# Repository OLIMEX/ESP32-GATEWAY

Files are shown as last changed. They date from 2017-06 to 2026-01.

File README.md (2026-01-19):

# ESP32-GATEWAY
ESP32 WiFi / BLE development board with Ethernet, microSD card, GPIOs, made with KiCAD

Board page: https://www.olimex.com/Products/IoT/ESP32/ESP32-GATEWAY/open-source-hardware

Hardware is released under Apache 2.0 License

Box design is released under CC BY 4.0 License

Software is released under GPL3 License

Documentation is released under CC BY-SA 3.0

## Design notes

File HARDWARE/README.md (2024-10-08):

# ESP32-GATEWAY
ESP32 WIFI / BLE development board with Ethernet, micro SD card, GPIOs made with KiCAD.

Notice that we use the latest nightly KiCad builds.

Hardware change log:

- Hardware revision I

1. To reduce noise getting picked by Ethernet clock, disconnected GPIO17 from the CON1 header. Added 
jumper pads GPIO17_E1 (open by default) if somebody wants to lead it to the header...

---

- Hardawre revision H

1. Added diode D5 on esp_en;
3. Added TVS1 on PHY;
4. Opravi se value na NA(HN1x20);
5. T1 now LMUN2211LT1G;
6. USB connector changed to type C (more popular nowadays);
7. Added r12 and c6;
8. Added CE sign;
9. R28,R31,R32,R33 lowered to 0402 size;
10. DCDC - SY8089 changed to TPS62A02ADRLR. C3 now NA. L2 changed to 1.0uH/2.5A/CD32;
11. Updated the CH340X module to the latest one. 

---

- Hardware revision G

1. R54 removed. R24 and R16 moved further away from the button.
2. Improved EN signal - added C5(1uF/0603) on pin #3 of ESP32. R24 now 10k.

---

- Hardware revision F

- Added 3D view. Major changes to GPIO header, SD card mode, power consumption!:

1. GPIO6-11, which are used by the ESP32's internal flash, were disconnected from CON1 
and the 6 SD card signals are now routed instead for use when SD card is not present;
2.  SD card changed from 4-bit mode of operation to 1-bit mode of operation! Added 3 
NA resistor pads (R9-R11) for backwards compatiblity.
3. A lot of deep sleep mode improvements to lower the consumption to 100uA or less:

- R19 was changed from 4.99k/1%/R0603 to 220k/R0603;

- R20 was changed from 1.1k/1%/R0603 to 49.9k/1%/R0603;

- R30 was changed from 10k/0603 to 1M/R0603;

- LED_E1 jumper added to provide an option to disable the power LED;

- R24 changed from 1k/0603 to 1M/R0603;

- U5(CH340)'s pin 20disconnected from GND and left opened;

- CH340 now powered only when USB is present;

- R35 and R40 were changed from 220R/R0603 to 10k/R0603;

- D1 and D3 added, 1N5819S4/SOD123, as level shifters;

4. L2 was changed from 2.2uH/1.5A/DCR<0.1R/CD32 to 2.2uH/1.5A/DCR=72mR/20%/3.00x3.00x1.50mm/CD32(NR3015T2R2M);
5. U3's value was changed from ESP-WROOM-32 to ESP32-WROOM-32D-4MB;
6. U9(BAT54C(SOT23-3)) was renamed to D4;

---

- Hardware revision E1

1. Added C2/22uF/0603 for slower PHY powering

- Hardware revision E

1. R5 connected after T1's collector and value changed from NA to 1K. 
2. Improved drill distances.

- Hardware revision D

>Major Ethernet schematic changes, now similar to ESP32-PoE:

1. LAN8710's pin XTAL1 was disconnected from GPIO0 and connected to GPIO17/EMAC_CLK_OUT_180. GPIO17 
is now source clock. GPIO5 is now used as Ethernet "power enable pin".
2. CR1(Q50MHz/25ppm/3V/4P/5x3.2mm) and all surrounding elements were deleted.
3. U8(NCP303LSN27T1G(SOT-23-5)) and all surrounding elements were deleted.
4. U10(BAT54C), R44 and R5 were deleted.
5. FET1, R5, R6, C2, T1 and L1 were added to enable Ethernet power on/off feature.
6. GPIO5 is used for Ethernet power on/off.

- Hardware revision C

1. R5(1k) resistor added between OSC_EN and NRST(pin #19) of LAN8710A chip. Later, it was changed to NA!
2. U2 changed from SY8009AAAC(SOT23-5) to SY8089AAAC(SOT23-5).
3. FET2 changed from IRLML6402 to WPM2015-3/TR.
4. ESP32-WROOM module pad improvements 

>Major changes to the Ethernet PHY and reset similar to EVB's_Rev_D1:

5. U8 changed from BD5230G-TR(SSOP5/SOT-23-5) to NCP303LSN27T1G(SOT-23-5).
6. C28 changed from 10nF/50V/20%/Y5V/C0603 to 470nF/16V/10%/X7R/C0603.
7. C18 changed from 10uF/6.3V/20%/X5R/C0603 to NA.
8. R38 changed from 100k to 10k/R0603.
9. R5 changed from 1k/R0603 to NA.

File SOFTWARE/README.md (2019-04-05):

# ESP32-GATEWAY software development

This repo contains ESP-IDF examples for Olimex ESP32-GATEWAY.

Since there are major hardware changes between revision C and D, there
are two folders with examples! The clock source for the Ethernet is different!

If you own newer board, revision D or newer then get the IDF exmaples from
folder "Newest-hardware-revisions"

If you have board revision B or C then get the demos from folder
"Hardware-revisions-B-or-C"

If you are looking for Arduino demos just install the official ESP32 json,
our board is supported in the official branches.

## Install ESP-IDF
To run the examples in this directory or your own you'll need to get
SDK from Espressif called [ESP-IDF](https://github.com/espressif/esp-idf).
We recommend reading their
[setup guide](https://github.com/espressif/esp-idf#setting-up-esp-idf).

When IDF_PATH is in your PATH you're ready to continue with example running.

## Run examples
To run our example all you need to do is:

* Run menuconfig
```sh
    make menuconfig
```

    * Configure serial flasher

    ESP32-GATEWAY has built-in serial flasher to help users upload their projects.
    Connect the board to PC via USB-micro cable. New serial device should
    apear, for example **/dev/ttyUSB0**. Then in the menuconfig configure
    flasher as follows:

    ```
    Serial flasher config  --->
            (/dev/ttyUSB0) Default serial port
            Default baud rate (115200 baud) --->
            [*] Use compressed upload
            Flash SPI mode (DIO)  --->
            Flash SPI speed (40 MHz) --->
            Flash size (4 MB) --->
            [*] Detect flash size when flashing bootloader
            Before flashing (Reset to bootloader)  --->
            After flashing (Reset after flashing)  --->
            'make monitor' baud rate (115200 bps)  --->
    ```

    * Configure example

    Some examples have their own configuration menu. If it's present
    you can modify the options:

    ```
    Example Configuration  --->
            Select board relay to use in the example (Relay 1)  --->
    ```

Exit and save configuration.

* Compile example
To compile example run:
```sh
make
```

* Uploading example
As we previously mention uploading application is done automatically.
If serial flasher is configured do:
```sh
make flash
```

You'll see something like this:
```
esptool.py v2.0-beta3
Flashing binaries to serial port /dev/ttyUSB0 (app at offset 0x10000)...
esptool.py v2.0-beta3
Connecting........__
Uploading stub...
Running stub...
Stub running...
Configuring flash size...
Auto-detected Flash size: 4MB
Flash params set to 0x0220
Compressed 15808 bytes to 9219...
Wrote 15808 bytes (9219 compressed) at 0x00001000 in 0.8 seconds (effective 154.5 kbit/s)...
Hash of data verified.
Compressed 356080 bytes to 168292...
Wrote 356080 bytes (168292 compressed) at 0x00010000 in 14.9 seconds (effective 191.3 kbit/s)...
Hash of data verified.
Compressed 3072 bytes to 82...
Wrote 3072 bytes (82 compressed) at 0x00008000 in 0.0 seconds (effective 1905.4 kbit/s)...
Hash of data verified.

Leaving...
Hard resetting...
```

Optionally you can open serial monitor by typing:
```sh
make monitor
```

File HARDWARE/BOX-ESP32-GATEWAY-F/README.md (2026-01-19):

Box can be purchased from here: https://www.olimex.com/Products/IoT/ESP32/BOX-ESP32-GATEWAY-F/

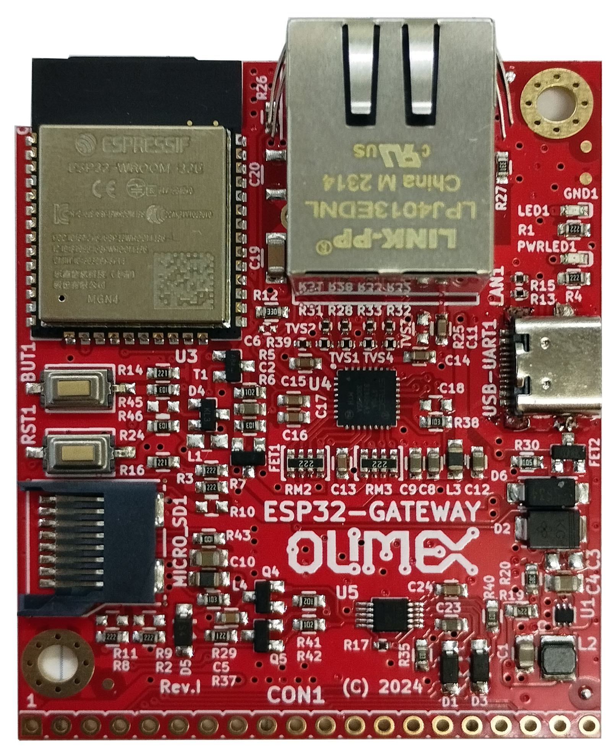
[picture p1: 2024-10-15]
DOCS/ESP32-GATEWAY-2-USB-C.jpg

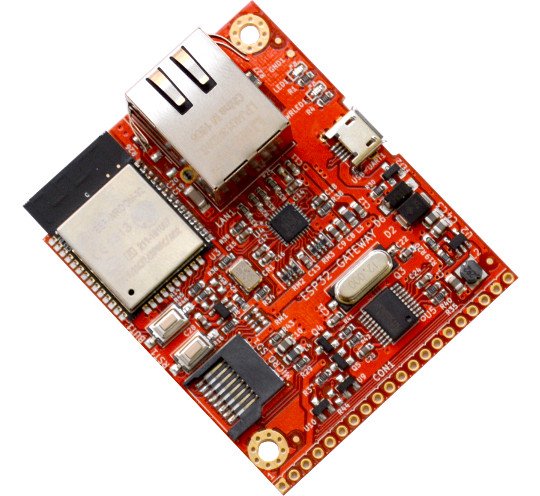
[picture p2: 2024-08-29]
DOCS/ESP32-GATEWAY-1.jpg

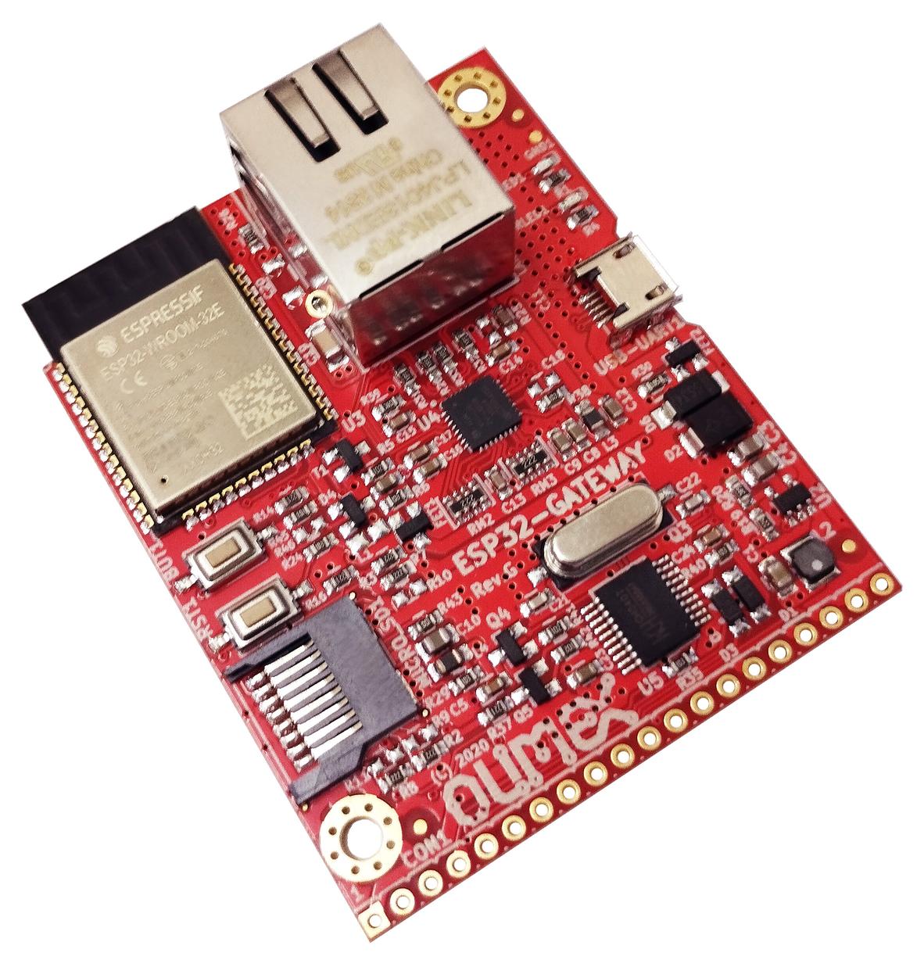
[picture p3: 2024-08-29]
DOCS/ESP32-GATEWAY-1-new.jpg

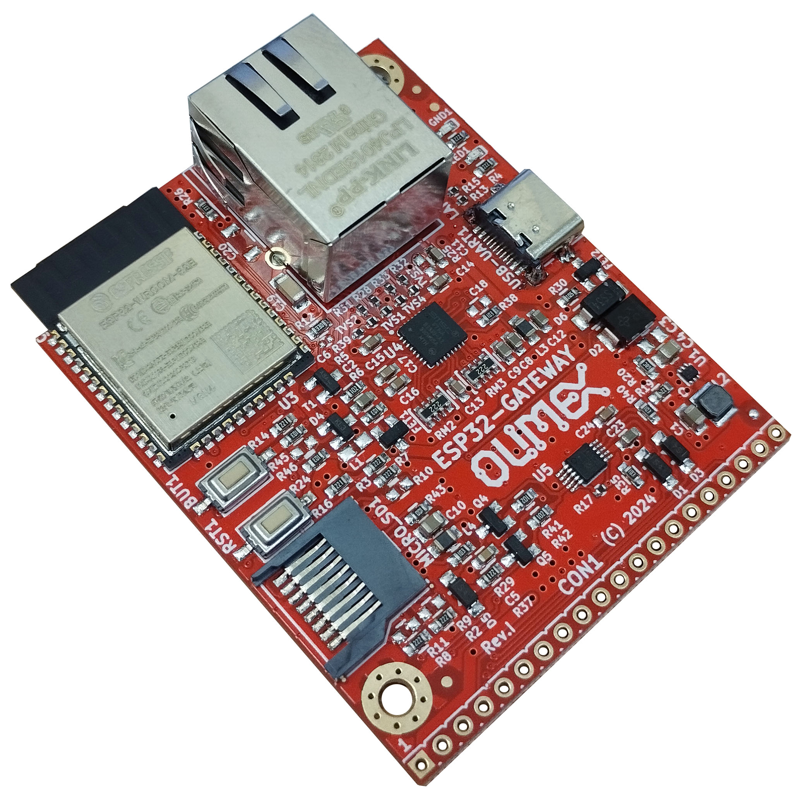
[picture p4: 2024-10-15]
DOCS/ESP32-GATEWAY-USB-C.jpg

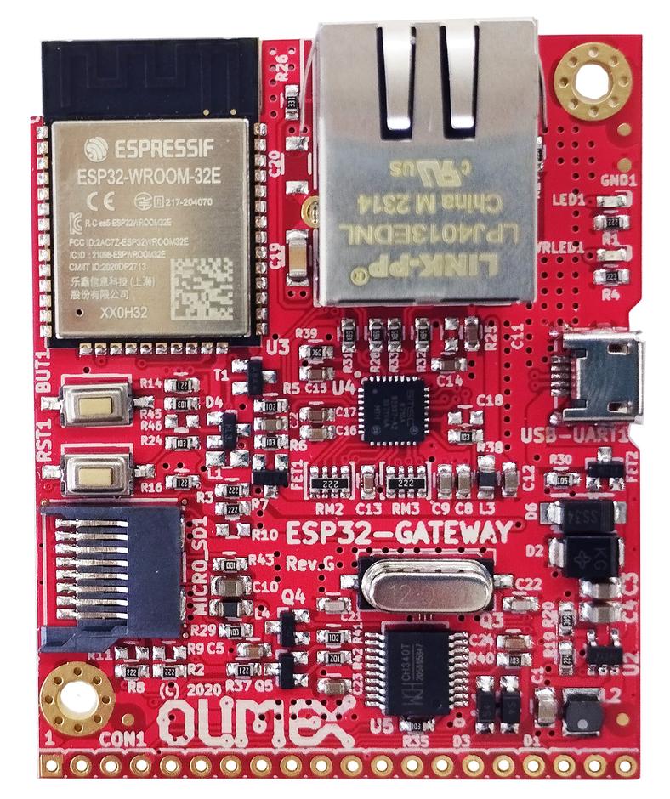
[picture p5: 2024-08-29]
DOCS/ESP32-GATEWAY-2-new.jpg

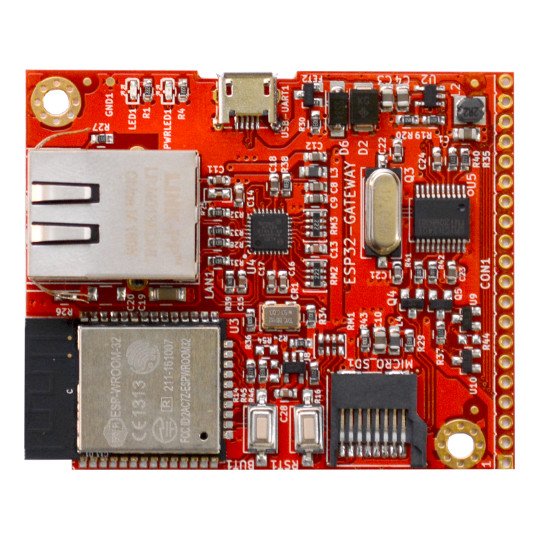
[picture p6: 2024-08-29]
DOCS/ESP32-GATEWAY-2.jpg

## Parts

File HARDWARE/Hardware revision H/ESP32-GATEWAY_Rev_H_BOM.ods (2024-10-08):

Qty | Designation | Package | Designator
1 | 0R(Board_Mounted) | R_0603_5MIL_DWS | R25
1 | 10R/R0603 | R_0603_5MIL_DWS | R43
1 | 33R/R0603 | R_0603_5MIL_DWS | R12
4 | 49.9R/1%/R0402 | R_0402_5MIL_DWS | R28,R31,R32,R33
3 | 220R/R0603 | R_0603_5MIL_DWS | R37,R16,R14
2 | 330R/R0603 | R_0603_5MIL_DWS | R27,R26
3 | 1k/R0603 | R_0603_5MIL_DWS | R5,R42,R41
6 | 2.2k/R0603 | R_0603_5MIL_DWS | R3,R2,R1,R4,R8,R7
1 | 4.7k/R0402 | R_0402_5MIL_DWS | R17
2 | 5.1k/1%/R0402 | R_0402_5MIL_DWS | R13,R15
7 | 10k/R0603 | R_0603_5MIL_DWS | R35,R29,R6,R45,R40,R38,R24
1 | 12.1k/1%/R0402 | R_0402_5MIL_DWS | R39
1 | 49.9k/1%/R0603 | R_0603_5MIL_DWS | R20
1 | 220k/R0603 | R_0603_5MIL_DWS | R19
1 | 1M/R0603 | R_0603_5MIL_DWS | R30
2 | RA1206_(4X0603)_4B8_2.2k | R_MATRIX_4 | RM3,RM2
1 | 1nF/2000V/10%/X7R/C1206 | C_1206_5MIL_DWS_ISO | C19
6 | 100nF/50V/20%/Y5V/C0603 | C_0603_5MIL_DWS | C24,C17,C15,C14,C13,C11
1 | 1uF/10V/10%/X5R/C0603 | C_0603_5MIL_DWS | C5
1 | 2.2uF/6.3V/10%/X5R/C0603 | C_0603_5MIL_DWS | C16
5 | 22uF/6.3V/20%/X5R/C0603 | C_0603_5MIL_DWS | C2,C23,C12,C9,C8
3 | 47uF/6.3V/20%/X5R/C0805 | C_0805_5MIL_DWS | C4,C10,C1
1 | 1.0uH/2.5A/DCR=30mR/20%/3x3x 1.5mm/CD32(SWPA3015S1R0MT) | CD32 | L2
2 | 600OHM/2A/UPZ2012E-601-2R0TF | L_0805_5MIL_DWS | L4,L3
3 | 1N5819S4/SOD123 | SOD-123_1C-2A_KA | D3,D1,D5
1 | 1N5822/SS34/SMA | SMA-KA | D6
1 | BAT54C(SOT23-3) | SOT23-3 | D4
1 | SMBJ6.0A(DO-214AA) | DO214AA_1(K)-2(A) | D2
1 | LED/GREEN/0603 | LED_0603_KA | LED1
1 | LED/RED/0603 | LED_0603_KA | PWRLED1
4 | GG0402052R542P | D_0402_5MIL_DWS | TVS2,TVS3,TVS4,TVS1
1 | LMUN2211LT1G | SOT23 | T1
2 | WPM2015-3/TR | SOT23 | FET1,FET2
2 | BC817-40(SOT23) | SOT23 | Q5,Q4
1 | ESP32-WROOM-32E-N4 | ESP-WROOM-32_MODULE | U3
1 | LAN8710A-EZC-ABC | QFN32_EP(33)_5.00x5.00x 0.90mm_Pitch_0.50mm | U4
1 | CH340X(MSOP-10) | MSOP-10_Pitch-0.5mm_ 3.00x3.00x1.00mm | U5
1 | TPS62A02ADRLR(SOT-563-6) | SOT-563-6 | U1
1 | USB-C-16P-F-PTH | USB2.0_TYPE-C (A40-00119-A52-12) | USB-UART1
1 | TFC-WXCP11-08-LF | TFC-WXCP11-08-LF | MICRO_SD1
1 | RJLD-060TC1(LPJ4013EDNL) | RJLBC-060TC1 | LAN1
2 | T1107A(6x3,8x2,5MM) | T1107A(6x3,8x2,5MM) | RST1,BUT1
1 | Opened | SJ | PHY_RST1
1 | Closed | SJ | LED_E1
1 | NA(10uF/6.3V/20%/X5R/C0603) | C_0603_5MIL_DWS | C18
1 | NA(47uF/6.3V/20%/X5R/C0805) | C_0805_5MIL_DWS | C3
1 | NA(FB0805/600R/2A) | L_0805_5MIL_DWS | L1
1 | NA(1nF/2000V/10%/X7R/C1206) | C_1206_5MIL_DWS_ISO | C20
1 | NA(HN1x20) | HN1x20 | CON1
4 | NA/R0603 | R_0603_5MIL_DWS | R46,R10,R9,R11
1 | NA/C0402 | C_0402_5MIL_DWS | C6

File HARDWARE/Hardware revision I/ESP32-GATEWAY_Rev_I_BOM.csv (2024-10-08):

Id | Designator | Package | Quantity | Designation | Supplier and ref
1 | U4 | QFN32_EP(33)_5.00x5.00x0.90mm_Pitch_0.50mm | 1 | LAN8710A-EZC-ABC
2 | USB-UART1 | USB2.0_TYPE-C(A40-00119-A52-12) | 1 | USB-C-16P-F-PTH
3 | D3,D1,D5 | SOD-123_1C-2A_KA | 3 | 1N5819S4/SOD123
4 | R19 | R_0603_5MIL_DWS | 1 | 220k/R0603
5 | R35,R29,R6,R45,R40,R38,R24 | R_0603_5MIL_DWS | 7 | 10k/R0603
6 | U5 | MSOP-10_Pitch-0.5mm_3.00x3.00x1.00mm | 1 | CH340X(MSOP-10)
7 | U3 | ESP-WROOM-32_MODULE | 1 | ESP32-WROOM-32E-N4
8 | Sign_CE | CE_Sign | 1 | CE_Sign
9 | LED_E1 | SJ | 1 | Closed
10 | MICRO_SD1 | TFC-WXCP11-08-LF | 1 | TFC-WXCP11-08-LF
11 | Logo-OlimexBIG,Logo-OLimeX | OLIMEX_LOGO_TB | 2
12 | R5,R42,R41 | R_0603_5MIL_DWS | 3 | 1k/R0603
13 | L1 | L_0805_5MIL_DWS | 1 | NA(FB0805/600R/2A)
14 | C2,C23,C12,C9,C8 | C_0603_5MIL_DWS | 5 | 22uF/6.3V/20%/X5R/C0603
15 | T1 | SOT23 | 1 | LMUN2211LT1G
16 | FET1,FET2 | SOT23 | 2 | WPM2015-3/TR
17 | D2 | DO214AA_1(K)-2(A) | 1 | SMBJ6.0A(DO-214AA)
18 | R3,R2,R1,R4,R8,R7 | R_0603_5MIL_DWS | 6 | 2.2k/R0603
19 | Sign_RoHS | LOGO_ROHS_1 | 1 | Val**
20 | Sign-RecyclBin | LOGO_RECYCLEBIN_1 | 1
21 | Sign_Pb-Free | LOGO_PBFREE | 1
22 | Logo-OSHW | LOGO_OPENHARDWARE_8x8 | 1
23 | Sign-Antistatic | LOGO_ANTISTATIC_1 | 1 | Val**
24 | LED1 | LED_0603_KA | 1 | LED/GREEN/0603
25 | CON1 | HN1x20 | 1 | NA(HN1x20)
26 | R37,R16,R14 | R_0603_5MIL_DWS | 3 | 220R/R0603
27 | C4,C10,C1 | C_0805_5MIL_DWS | 3 | 47uF/6.3V/20%/X5R/C0805
28 | C3 | C_0805_5MIL_DWS | 1 | NA(47uF/6.3V/20%/X5R/C0805)
29 | R20 | R_0603_5MIL_DWS | 1 | 49.9k/1%/R0603
30 | R46,R10,R9,R11 | R_0603_5MIL_DWS | 4 | NA/R0603
31 | R30 | R_0603_5MIL_DWS | 1 | 1M/R0603
32 | D6 | SMA-KA | 1 | 1N5822/SS34/SMA
33 | C24,C17,C15,C14,C13,C11 | C_0603_5MIL_DWS | 6 | 100nF/50V/20%/Y5V/C0603
34 | C20 | C_1206_5MIL_DWS_ISO | 1 | NA(1nF/2000V/10%/X7R/C1206)
35 | C19 | C_1206_5MIL_DWS_ISO | 1 | 1nF/2000V/10%/X7R/C1206
36 | R43 | R_0603_5MIL_DWS | 1 | 10R/R0603
37 | R27,R26 | R_0603_5MIL_DWS | 2 | 330R/R0603
38 | PWRLED1 | LED_0603_KA | 1 | LED/RED/0603
39 | GND1 | TESTPAD_40-ROUND | 1 | TESTPAD
40 | C18 | C_0603_5MIL_DWS | 1 | NA(10uF/6.3V/20%/X5R/C0603)
41 | C16 | C_0603_5MIL_DWS | 1 | 2.2uF/6.3V/10%/X5R/C0603
42 | PHY_RST1,GPIO17_E1 | SJ | 2 | Opened
43 | MH1,MH2 | Mounting_hole_Shield_3.3mm | 2 | Mounting_hole_Shield_3.3mm
44 | L4,L3 | L_0805_5MIL_DWS | 2 | 600OHM/2A/UPZ2012E-601-2R0TF
45 | Q5,Q4 | SOT23 | 2 | BC817-40(SOT23)
46 | L2 | CD32 | 1 | 1.0uH/2.5A/DCR=30mR/20%/3.00x3.00x1.50mm/CD32(SWPA3015S1R0MT)
47 | RM3,RM2 | R_MATRIX_4 | 2 | RA1206_(4X0603)_4B8_2.2k
48 | RST1,BUT1 | T1107A(6x3,8x2,5MM) | 2 | T1107A(6x3,8x2,5MM)
49 | D4 | SOT23-3 | 1 | BAT54C(SOT23-3)
50 | FID1,FID3 | Fiducial1x3 | 2 | Fiducial
51 | R25 | R_0603_5MIL_DWS | 1 | 0R(Board_Mounted)
52 | C5 | C_0603_5MIL_DWS | 1 | 1uF/C0603
53 | LAN1 | RJLBC-060TC1 | 1 | RJLD-060TC1(LPJ4013EDNL)
54 | R12 | R_0603_5MIL_DWS | 1 | 33R/R0603
55 | R28,R31,R32,R33 | R_0402_5MIL_DWS | 4 | 49.9R/1%/R0402
56 | FID4,FID2 | Fiducial1x3_Past | 2 | Fiducial
57 | TVS2,TVS3,TVS4,TVS1 | D_0402_5MIL_DWS | 4 | GG0402052R542P
58 | C6 | C_0402_5MIL_DWS | 1 | NA/C0402
59 | R39 | R_0402_5MIL_DWS | 1 | 12.1k/1%/R0402
60 | U1 | SOT-563-6 | 1 | TPS62A02ADRLR(SOT-563-6)
61 | R13,R15 | R_0402_5MIL_DWS | 2 | 5.1k/1%/R0402
62 | R17 | R_0402_5MIL_DWS | 1 | 4.7k/R0402

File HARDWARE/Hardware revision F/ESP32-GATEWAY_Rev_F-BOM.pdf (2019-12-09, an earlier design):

09:20:28 | ESP32-GATEWAY_Rev_F | 04/30/2019
Qty | Designation | Package | Designator
1 | 0R(board_mounted) | 0R_0603 | R25
1 | 10R/R0603 | R_0603_5MIL_DWS | R43
4 | 49.9R/1%/R0603 | R_0603_5MIL_DWS | R28,R31,R32,R33
3 | 220R/R0603 | R_0603_5MIL_DWS | R14,R16,R37
2 | 330R/R0603 | R_0603_5MIL_DWS | R26,R27
3 | 1k/R0603 | R_0603_5MIL_DWS | R5,R41,R42
6 | 10k/R0603 | R_0603_5MIL_DWS | R6,R29,R35,R38,R40,R45
6 | 2.2k/R0603 | R_0603_5MIL_DWS | R1,R2,R3,R4,R7,R8
1 | 12.1k/1%/R0603 | R_0603_5MIL_DWS | R39
1 | 49.9k/1%/R0603 | R_0603_5MIL_DWS | R20
1 | 220k/R0603 | R_0603_5MIL_DWS | R19
1 | 1M/R0603 | R_0603_5MIL_DWS | R24,R30
2 | RA1206_(4X0603)_4B8_2.2k | R_MATRIX_4 | RM2,RM3
2 | 27pF/50V/5%/C0G/C0603 | C_0603_5MIL_DWS | C21,C22
1 | 1nF/2000V/10%/X7R/C1206 | C_1206_5MIL_DWS_ISO | C19
6 | 100nF/50V/20%/Y5V/C0603 | C_0603_5MIL_DWS | C11,C13,C14,C15,C17,C24
1 | 2.2uF/6.3V/10%/X5R/C0603 | C_0603_5MIL_DWS | C16
5 | 22uF/6.3V/20%/X5R/C0603 | C_0603_5MIL_DWS | C2,C8,C9,C12,C23
4 | 47uF/6.3V/20%/X5R/C0805 | C_0805_5MIL_DWS | C1,C3,C4,C10
1 | 2.2uH/1.5A/DCR=72mR/20%/ 3.00x3.00x1.50mm/ CD32(NR3015T2R2M) | CD32 | L2
2 | FB0805/600R/2A | L_0805_5MIL_DWS | L3,L4
1 | 1N5822/SS34/SMA | SMA-KA | D6
1 | SMBJ6.0A(DO-214AA) | DO214AA_1(K)-2(A) | D2
1 | BAT54C(SOT23-3) | SOT23-3 | D4
2 | 1N5819S4/SOD123 | SOD123 | D1,D3
1 | LED/GREEN/0603 | LED_0603_KA | LED1
1 | LED/RED/0603 | LED_0603_KA | PWRLED1
2 | WPM2015-3/TR | SOT23 | FET1,FET2
1 | DTC114YKA | SOT23 | T1
2 | BC817-40(SOT23) | SOT23 | Q4,Q5
1 | Q12MHz/20pF/30ppm/2P/ HC-49SM(SMD) | Q_49U3HMS | Q3
1 | ESP32-WROOM-32D-4MB | ESP-WROOM-32_MODULE | U3
1 | SY8089AAAC(SOT23-5) | SOT-23-5 | U2
1 | CH340T(SSOP20W) | SSOP-20W | U5
1 | LAN8710A-EZC(QFN32) | QFN32_EP(33)_5.00x5.00x0.90mm_ Pitch_0.50mm | U4
2 | T1107A(6x3,8x2,5MM) | T1107A(6x3,8x2,5MM) | BUT1,RST1
1 | TFC-WXCP11-08-LF | TFC-WXCP11-08-LF | MICRO_SD1
1 | RJLD-060TC1(LPJ4013EDNL) | RJLBC-060TC1 | LAN1
1 | MISB-SWMM-5B-LF (USB_MICRO) | USB-MICRO_ MISB-SWMM-5B_LF | USB-UART1
1 | Opened | SJ | PHY_RST1
1 | Closed | SJ | LED_E1
1 | NA(10uF/6.3V/20%/X5R/C0603) | C_0603_5MIL_DWS | C18
1 | NA(1nF/2000V/10%/X7R/C1206) | C_1206_5MIL_DWS_ISO | C20
5 | NA/R0603 | R_0603_5MIL_DWS | R9,R10,R11,R46,R54
1 | NA(NH1x20) | HN1x20 | CON1
1 | NA(FB0805/600R/2A) | L_0805_5MIL_DWS | L1

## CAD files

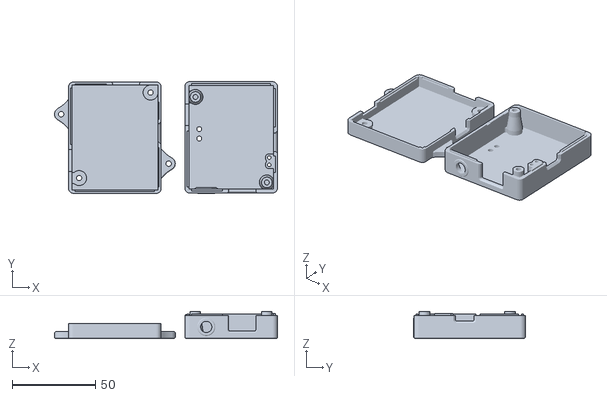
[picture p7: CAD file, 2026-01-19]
HARDWARE/BOX-ESP32-GATEWAY-F/esp32_gateway-v16.stl
134.2 x 67.7 x 16.3

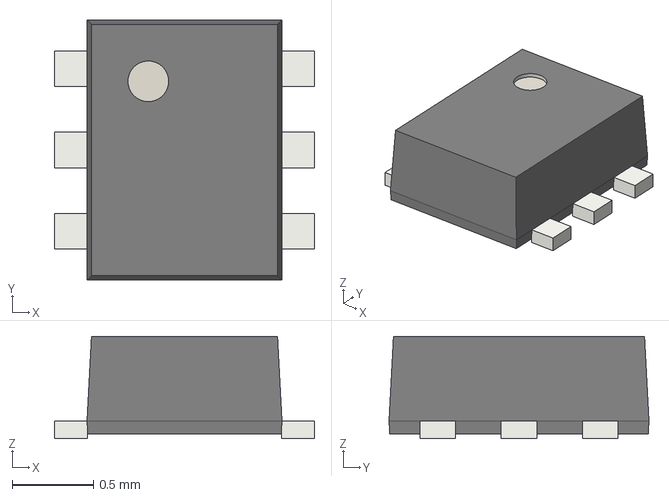
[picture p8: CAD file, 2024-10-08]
HARDWARE/Hardware revision H/3d/SOT-563.step
1.60 x 1.60 x 0.63 mm

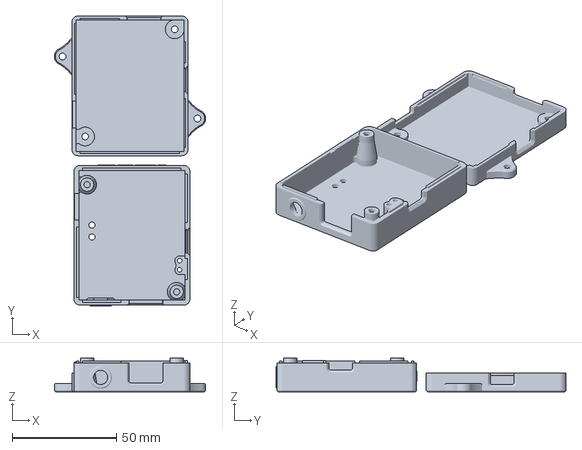
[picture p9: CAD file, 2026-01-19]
HARDWARE/BOX-ESP32-GATEWAY-F/esp32_gateway-v16-bambu-lab-project.3mf
72.7 x 139.2 x 16.3 mm

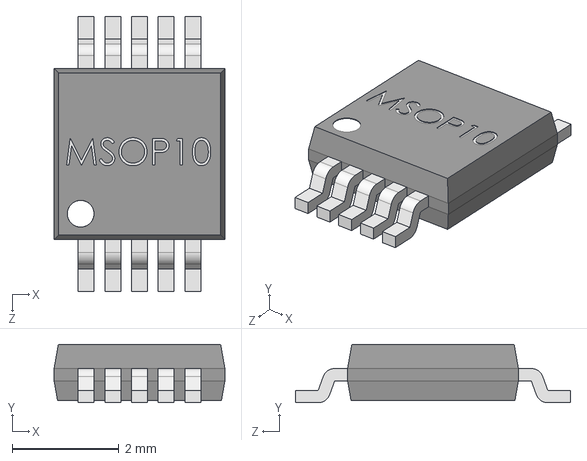
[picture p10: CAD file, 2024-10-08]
HARDWARE/Hardware revision H/3d/MSOP10-1.step
3.20 x 1.10 x 5.15 mm

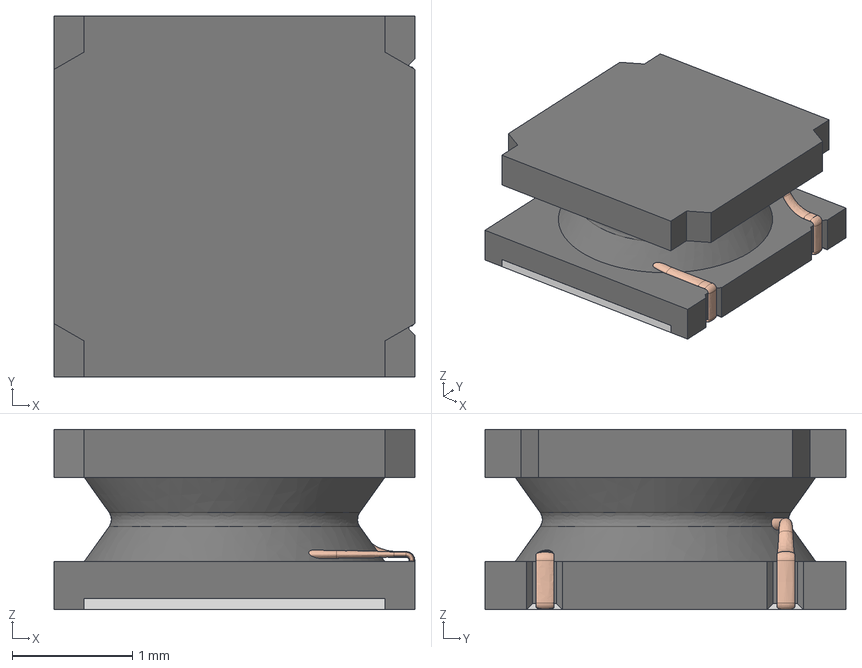
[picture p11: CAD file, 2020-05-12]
HARDWARE/Hardware revision H/3d/L-CD32_shielded.step
3.00 x 3.00 x 1.50 mm

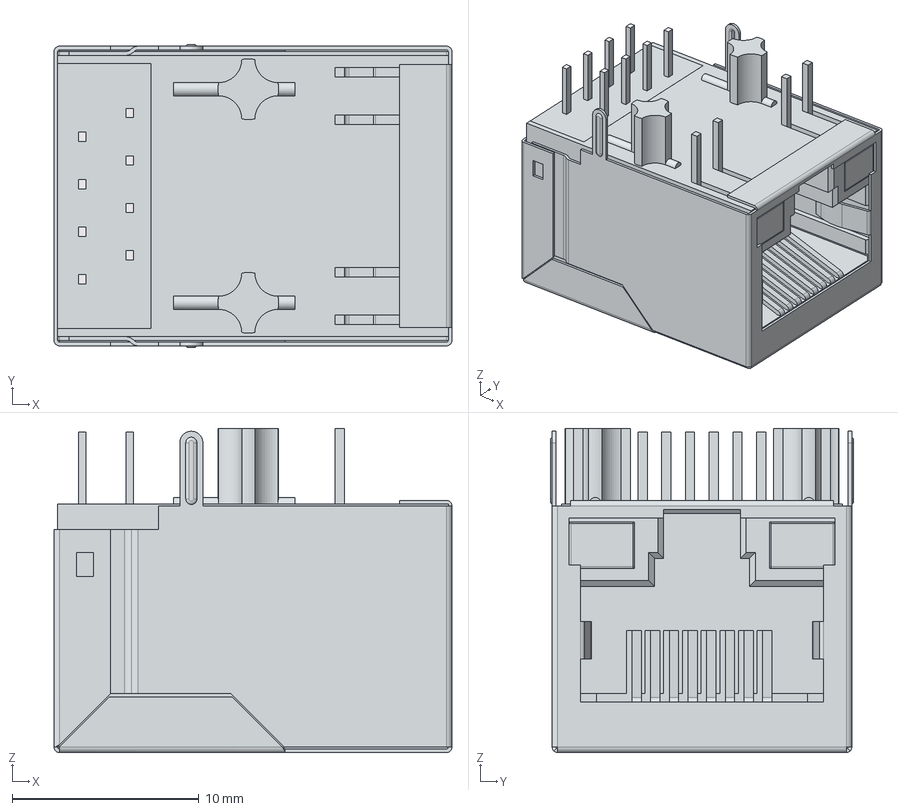
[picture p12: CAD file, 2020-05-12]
HARDWARE/Hardware revision H/3d/Connector_1Port_RJ45_Magjack_10-100Base-T_AutoMDIX_Wurth_Electronics-7499010441.stp
21.3 x 16.2 x 17.4 mm
Shielding
Insulator 3
Insulator 1
Insulator 2
Green_Yellow_LED x 2

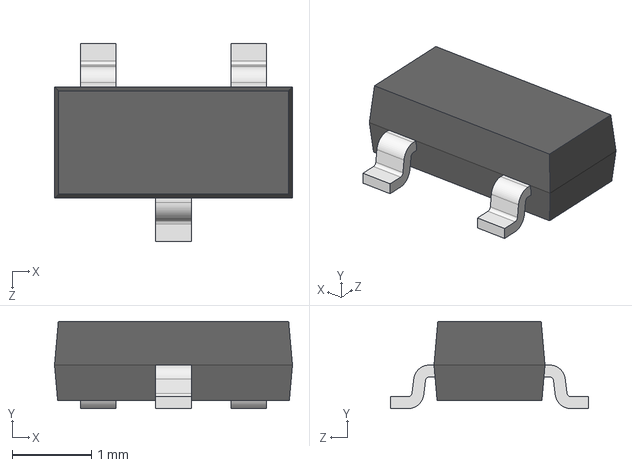
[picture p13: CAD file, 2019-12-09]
HARDWARE/Hardware revision H/3d/SOT-23.step
3.00 x 1.10 x 2.50 mm

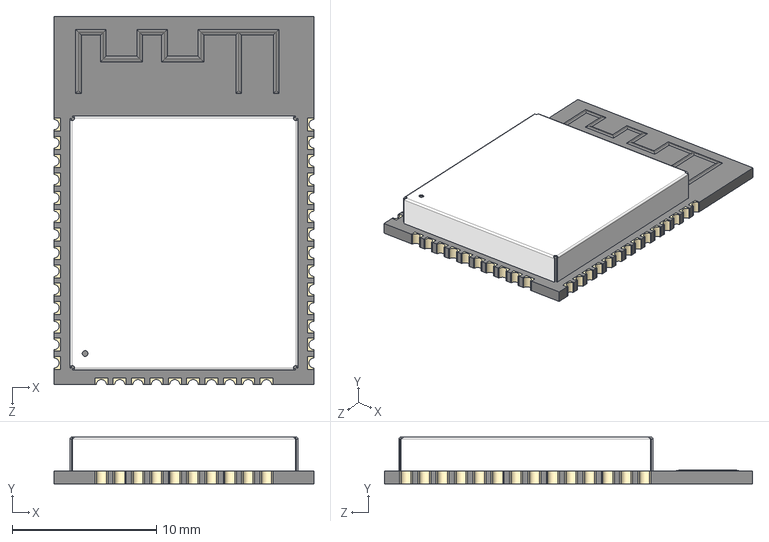
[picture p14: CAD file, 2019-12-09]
HARDWARE/Hardware revision H/3d/ESP32-WROOM-32D-56544.STEP
18.0 x 3.25 x 25.5 mm

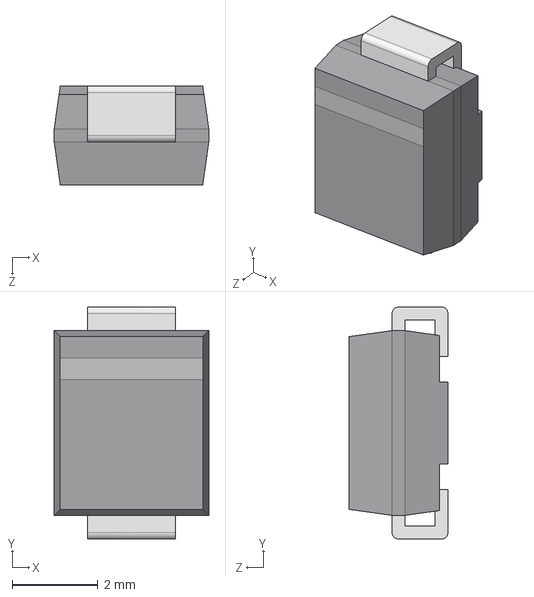
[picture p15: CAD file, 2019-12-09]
HARDWARE/Hardware revision I/3d/DO-214AA_SMB.step
3.60 x 5.40 x 2.30 mm

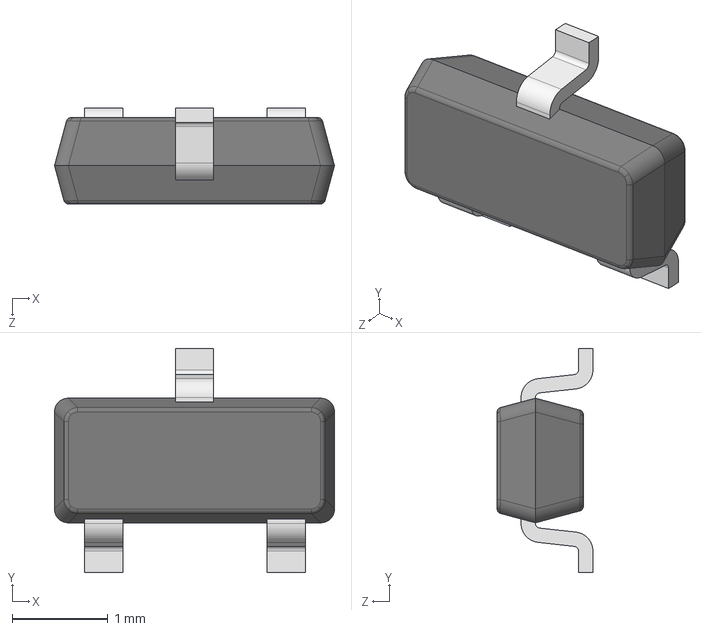
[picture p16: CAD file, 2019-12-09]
HARDWARE/Hardware revision H/3d/BAT54.step
2.92 x 2.34 x 1.00 mm

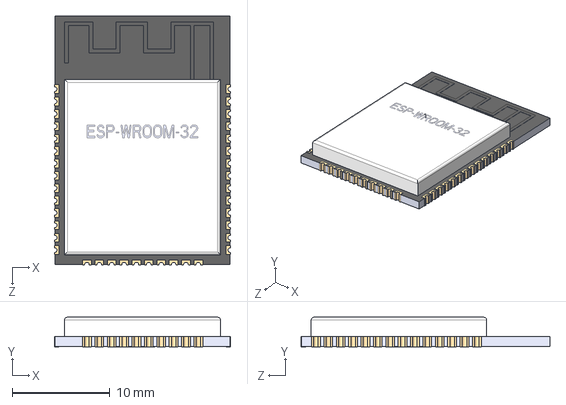
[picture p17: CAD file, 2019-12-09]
HARDWARE/Hardware revision I/3d/esp-wroom-32.step
18.1 x 3.04 x 25.5 mm

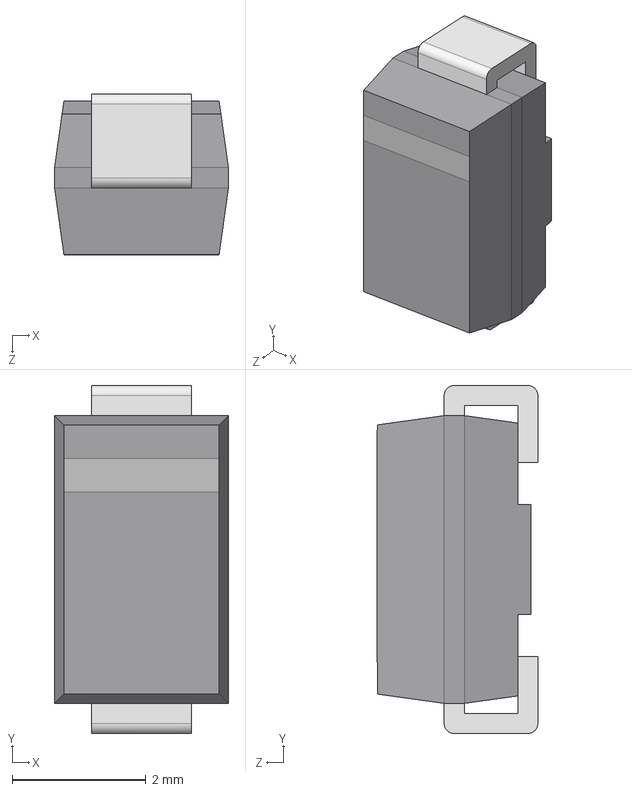
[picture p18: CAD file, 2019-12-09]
HARDWARE/Hardware revision I/3d/DO-214AC_SMA.step
2.60 x 5.20 x 2.40 mm

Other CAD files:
HARDWARE/Hardware revision F/3d/CD32_inductor.step
HARDWARE/Hardware revision G/3d/SOT-23-5.step
HARDWARE/Hardware revision G/3d/User_Library-Crystal_HC49_US-SM.step
HARDWARE/Hardware revision G/3d/usb_micro_4p.stp
HARDWARE/Hardware revision H/3d/434121043836 (rev1).stp
HARDWARE/Hardware revision H/3d/5040771891.stp
HARDWARE/Hardware revision H/3d/QFN32_5x5.step
HARDWARE/Hardware revision H/3d/SOD123.step
HARDWARE/Hardware revision I/3d/434121043836 (rev1).stp
HARDWARE/Hardware revision I/3d/5040771891.stp
HARDWARE/Hardware revision I/3d/QFN32_5x5.step
HARDWARE/Hardware revision I/3d/SOD123.step

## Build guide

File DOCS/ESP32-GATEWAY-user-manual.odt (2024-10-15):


ESP32-GATEWAY

User Manual

Document revision 2.1, October 2024 | www.olimex.com

# 1. What is ESP32-GATEWAY

ESP32-GATEWAY is a mature Open Source Hardware development board that incorporates n ESP32 module. The ESP32-GATEWAY board is designed and manufactured by Olimex, while the ESP32 module is designed and manufactured by Espressif systems. The ESP32 modules are extremely popular WIFI/BT modules due to their size, price, and very good documentation.

The ESP32-GATEWAY board has the following features:

- ESP32-WROOM-32E or ESP32-WROOM-32UE module with WiFi, BLE connectivity
- USB type C connector for powering and programming with CH340 USB serial converter
- Ethernet 100Mb interface with LAN8710A driver
- MicroSD card
- Reset button
- User button
- Power status LED
- User LED
- GPIO 20 pin connector with all ESP32 ports
- Dimensions: (50 x 62)mm ~ (1.95 x 2.45)"
- Optional external antenna (-EA)
- Industrial grade -40+85C version available (-IND)

## 1.1 ESP32-GATEWAY variants

The board has 4 variants – ESP32-GATEWAY, ESP32-GATEWAY-EA, ESP32-GATEWAY-EA-IND, ESP32-GATEWAY-IND. The base variant ESP32-GATEWAY works in commercial temperature range (0-70 degrees C) and has on-module antenna.

ESP32-GATEWAY and ESP32-GATEWAY-IND come with ESP32-WROOM-32E module;

ESP32-GATEWAY-EA and ESP32-GATEWAY-EA-IND come with ESP32-WROOM-32UE and external antenna;

ESP32-GATEWAY and ESP32-GATEWAY-EA work in the commercial temperature range 0-70C;

ESP32-GATEWAY-IND and ESP32-GATEWAY-EA-IND have all components rated for operating in the industrial temperature range -40+85C.

## 1.2 Board use requirements

You only need a fitting USB cable and a personal computer. The latest hardware revision of the board requires USB type C connector. Usually only such cable is required:

https://www.olimex.com/Products/Components/Cables/USB-CABLE-A-TO-C-1M/

Notice that older hardware revisions came with USB micro connector and require USB micro cable.

The computer needs software compatible with ESP32 modules. Most commonly used tools are ESP-IDF and Arduino IDE with ESP32 package. You can use ESP32-GATEWAY with any software tool that supports the main ESP32 module.

## 1.3 ESP32-GATEWAY Open Source Licenses

ESP32-GATEWAY is Open Source Hardware, listed in OSHWA.org here:

https://certification.oshwa.org/bg000012.html

The hardware files are released under CERN OSHW (https://github.com/OLIMEX/USB-gLINK/blob/master/cern_ohl_s_v2.pdf) license.

The software is released under GPL 3 license (https://github.com/OLIMEX/USB-gLINK/blob/master/LICENSE).

The documentation is released under CC BY-SA 3.0 (https://creativecommons.org/licenses/by-sa/3.0/) license.

# 2. ESP32-GATEWAY general layout

Ethernet commector

ESP32 module

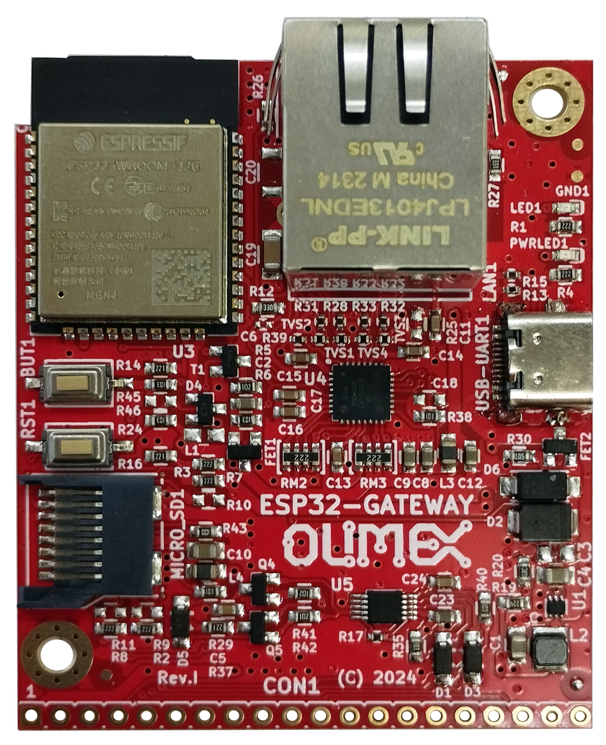
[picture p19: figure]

CON1 header

User LED

Power status LED

USB type C

User

button

Reset

button

MicroSD

card holder

Mount hole

# 3. ESP32-GATEWAY power supply and consumption

ESP32-GATEWAY typically consumes around 50mA of current depending on the software. The board can consume much less (uA) using the ESP32 power saving modes.

The absolute maximum power ESP32-GATEWAY can draw from the power supply would be the determined by the maximum input of the regulator on the power input line. Of course, consider that on-board peripherals and the main module would use some of that current. When you power the board from either the USB or the +5V pin of the CON1 header → the regulator is TPS62A02ADRLR can output maximum 2000mA continuously.

# 4. ESP32-GATEWAY schematics and dimensions

ESP32-GATEWAY was designed with KiCAD (free and open-source CAD tool). ESP32-GATEWAY schematics and sources can be found at GitHub here:

https://github.com/OLIMEX/ESP32-GATEWAY/tree/master/HARDWARE

There are also PDF exports if you don’t want to install KiCAD.

Board dimensions can be found here:

https://www.olimex.com/Products/IoT/ESP32/ESP32-GATEWAY/resources/ESP32-GATEWAY-general-dim.png

# 5. ESP32-GATEWAY pinout description:

The board’s pinout can be seen here:

https://www.olimex.com/Products/IoT/ESP32/ESP32-GATEWAY/resources/ESP32-GATEWAY-GPIOs-Rev.F-up.pdf

The ESP32 chip has very good multiplexer so you can set the free GPIO pins for alternative functions via software means.

The SD card interface is in 1-bit eMMC mode.

By default GPIO17 is not lead to the CON1 header to reduce noise on the Ethernet clock line. You can solder together the pads of jumper GPIO17_E1 if you wish to lead it to the CON1 header.

# 6. ESP32-GATEWAY software installation

Esspresif guide for Arduino IDE installation (https://docs.espressif.com/projects/arduino-esp32/en/latest/installing.html) – after installation – there is own entry for the board, it should be listed as OLIMEX ESP32-GATEWAY in the board selection.

Espressif ESP-IDF installation (https://github.com/espressif/esp-idf).

Esspressif guide for PlatformIO installation (https://docs.espressif.com/projects/arduino-esp32/en/latest/installing.html).

Olimex provides some ESP-IDF and Arduino examples here:

https://github.com/OLIMEX/ESP32-GATEWAY/tree/master/SOFTWARE

# 7. FAQ

- I received ESP32-GATEWAY and expected USB micro connector but the board came with USB type C connector. Was there a mistake?
  - No. We updated the design with USB type C connector in 2024. It is the more popular connector nowadays.
- I have ESP32-GATEWAY and it appears Ethernet is generating a lot of noise. How can I lower the noise?
  - In hardware revisions prior to revision H, this might be caused by bigger than needed driver strength set by the software on the Ethernet clock pin (GPIO17). Lower the drive strength of the digital output num 17 from the default value 20mA to 5mA. There are usually 4 levels of strength from 0 to 3.
    In Arduino this can be done with:
      gpio_set_drive_capability((gpio_num_t)GPIO_NUM_17, GPIO_DRIVE_CAP_0);
    and also you need to include at top:
      #include "driver/gpio.h"

# 8. Document revision history

Revision 2.1 October 2024

- Added FAQ section

- Updated pictures

Revision 2.0 October 2024

- Hardware design changed – main changes are USB connector now USB type C and Ethernet clock routing improved, jumpers added at bottom

Revision 1.0 August 2024

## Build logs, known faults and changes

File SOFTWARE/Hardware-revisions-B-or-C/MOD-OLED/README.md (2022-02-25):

Demo example for Olimex ESP32-GATEWAY (revision B) with Olimex MOD-OLED-128x64.

Used I2C-1 for communication between the host board and the module. More comments can be found in main.c. 

After programming on the screen you will see a welcome message. When you click the button BUT1, a counter will appear on the screen.

Products used:

ESP32-GATEWAY: https://www.olimex.com/Products/IoT/ESP32-GATEWAY/open-source-hardware

MOD-OLED-128x64: https://www.olimex.com/Products/Modules/LCD/MOD-OLED-128x64/open-source-hardware

The hardware setup looks like this:

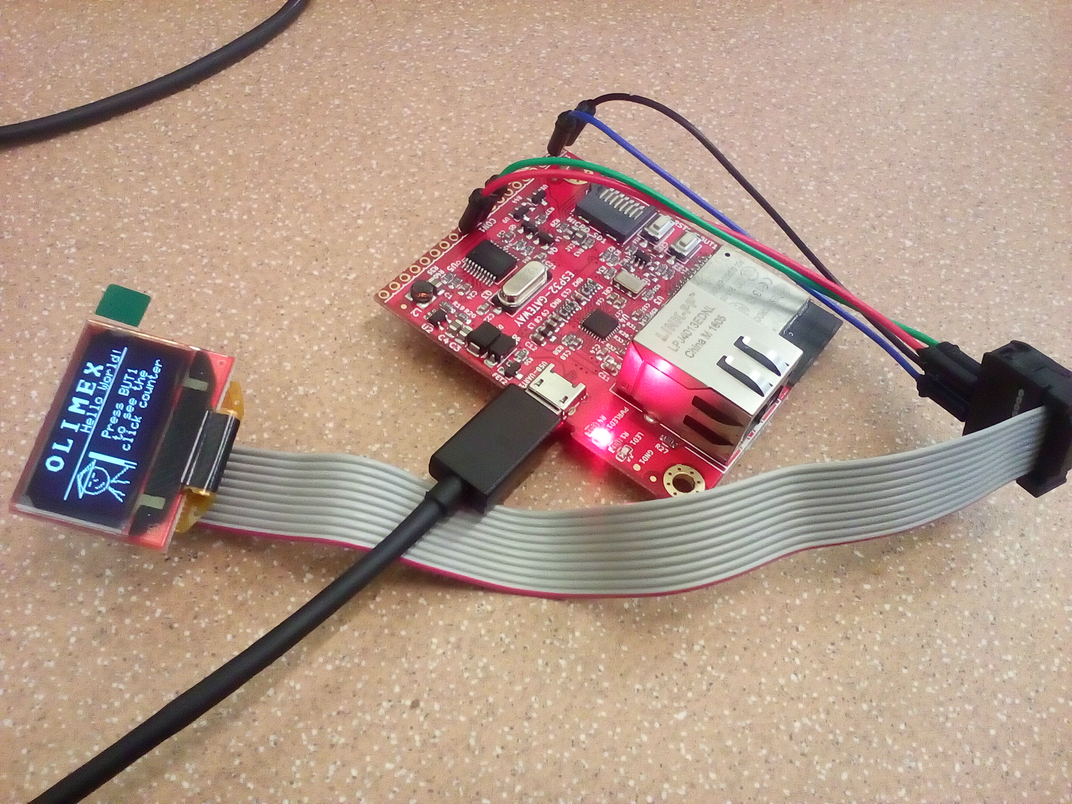
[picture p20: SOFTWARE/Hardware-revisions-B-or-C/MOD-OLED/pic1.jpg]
Hardware setup


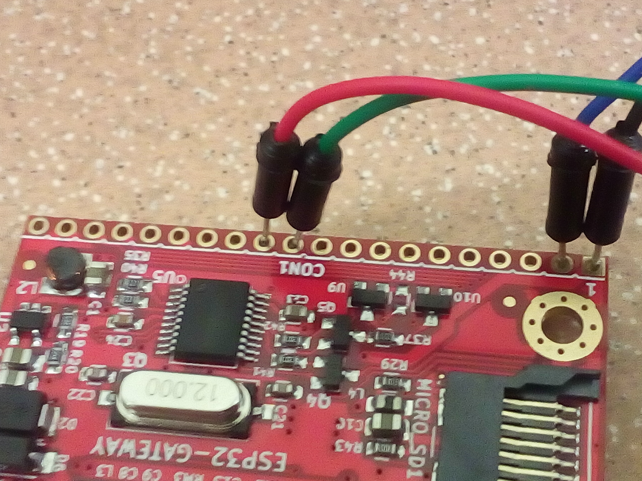
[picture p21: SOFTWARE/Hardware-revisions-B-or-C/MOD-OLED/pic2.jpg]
Hardware setup2


Stanimir Petev
2018/03/27

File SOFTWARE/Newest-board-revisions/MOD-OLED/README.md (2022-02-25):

Demo example for Olimex ESP32-GATEWAY (revision B) with Olimex MOD-OLED-128x64.

Used I2C-1 for communication between the host board and the module. More comments can be found in main.c. 

After programming on the screen you will see a welcome message. When you click the button BUT1, a counter will appear on the screen.

Products used:

ESP32-GATEWAY: https://www.olimex.com/Products/IoT/ESP32-GATEWAY/open-source-hardware

MOD-OLED-128x64: https://www.olimex.com/Products/Modules/LCD/MOD-OLED-128x64/open-source-hardware

The hardware setup looks like this:

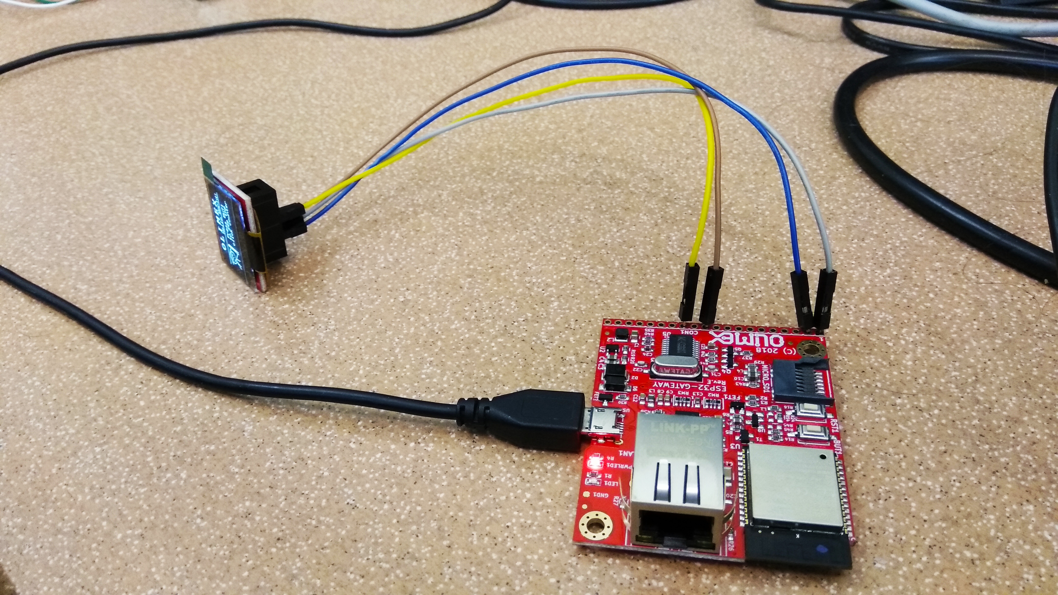
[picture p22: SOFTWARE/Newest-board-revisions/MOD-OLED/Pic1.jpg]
Hardware setup


Stanimir Petev
2018/03/27

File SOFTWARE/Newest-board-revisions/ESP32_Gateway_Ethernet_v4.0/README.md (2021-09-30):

# Ethernet Example
(See the README.md file in the upper level 'examples' directory for more information about examples.)

## Overview

This example demonstrates basic usage of `Ethernet driver` together with `tcpip_adapter`. The work flow of the example could be as follows:

1. Install Ethernet driver
2. Send DHCP requests and wait for a DHCP lease
3. If get IP address successfully, then you will be able to ping the device

If you have a new Ethernet application to go (for example, connect to IoT cloud via Ethernet), try this as a basic template, then add your own code.

## How to use example

### Hardware Required

To run this example, it's recommended that you have the Olimex board ESP32-GATEWAY or one of its variants. This example should also work for 3rd party ESP32 board as long as it's integrated with a supported Ethernet PHY chip. Up until now, ESP-IDF supports up to four Ethernet PHY: LAN8720, IP101, DP83848 and RTL8201, additional PHY drivers should be implemented by users themselves.

Notice that Olimex board uses LAN8710 chip but the libraries for LAN8710 and LAN8720 are similar (the chips are very similar).

Besides that, esp_eth component can drive third-party Ethernet module which integrates MAC and PHY and provides common communication interface (e.g. SPI, USB, etc).This example will take the LAN8720 library for the an example, illustrating how to install the Ethernet driver in the same manner. In this project by default this feature is disabled. If you want to enable it:

```
idf.py menuconfig
```

then option and navigate to "Component config -> Ethernet" and check the "Support SPI to Ethernet Module" and then in that submenu check "Use LAN8720".

### Configure the project

```
idf.py menuconfig
```

See common configurations for Ethernet examples from [upper level](../../README.md#run-examples).

### Build, Flash, and Run

Build the project and flash it to the board, then run monitor tool to view serial output:

```
idf.py -p PORT build flash monitor
```

(Replace PORT with the name of the serial port to use.)

(To exit the serial monitor, type ``Ctrl-]``.)

See the [Getting Started Guide](https://docs.espressif.com/projects/esp-idf/en/latest/get-started/index.html) for full steps to configure and use ESP-IDF to build projects.

## Example Output

```bash
I (394) eth_example: Ethernet Started
I (3934) eth_example: Ethernet Link Up
I (3934) eth_example: Ethernet HW Addr 30:ae:a4:c6:87:5b
I (5864) tcpip_adapter: eth ip: 192.168.2.151, mask: 255.255.255.0, gw: 192.168.2.2
I (5864) eth_example: Ethernet Got IP Address
I (5864) eth_example: ~~~~~~~~~~~
I (5864) eth_example: ETHIP:192.168.2.151
I (5874) eth_example: ETHMASK:255.255.255.0
I (5874) eth_example: ETHGW:192.168.2.2
I (5884) eth_example: ~~~~~~~~~~~
```

Now you can ping your ESP32 in the terminal by entering `ping 192.168.2.151` (it depends on the actual IP address you get).

## Troubleshooting

For any technical queries, please open an [issue](https://github.com/OLIMEX/ESP32-GATEWAY/issues) on GitHub. We will get back to you as soon as possible.

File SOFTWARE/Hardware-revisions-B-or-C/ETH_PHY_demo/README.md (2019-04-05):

# Ethernet Example 
( customized for Olimex ESP32-GATEWAY revision B or revision C with LAN8710 ) 

Initializes and enables the Ethernet interface, then sends DHCP requests and tries to obtain a DHCP lease. 
If successful then you will be able to ping the device.

IMPORTANT! This example is not suitable for newer ESP32-GATEWAY bords (revision D or  newer)! Only hardware reivsion C or older!
There are major hardware changes between revision C and D! The clock source for the Ethernet is different!
# PHY Configuration

Use "make menuconfig" to set the PHY model and the PHY address, and configure the SMI I/O pins (see below). These configuration items will vary depending on the hardware configuration you are using.

The customize default example configuration is correct for Olimex ESP32-GATEWAY revision C or older with LAN8710 PHY. 

## PHY Address

The PHY address depends on the hardware and the PHY configuration. Olimex ESP32-GATEWAY revision C or older use PHY address 0.

FYI:
* Address 31 is correct for Espressif's Ethernet board with TLK110 PHY.
* Address 1 is correct for the common Waveshare LAN8720 PHY breakout.
* Default Address 0 is correct for the Olimex ESP32 EVB REV B IoT LAN8710 PHY Board with CAN
* Other LAN8720 breakouts may take address 0.

If the PHY address is incorrect then the EMAC will initialise but all attempts to read/write configuration registers on the PHY will fail.

## RMII PHY Wiring

The following PHY connections are required for RMII PHY data connections. These GPIO pin assignments cannot be changed.

| GPIO | RMII Signal | ESP32 EMAC Function | Notes |
| --- | --- | --- | ----- |
| 0 | REF_CLK | EMAC_TX_CLK | Currently this must be a 50MHz reference clock input from the PHY (ext_osc configuration). |
| 21 | TX_EN | EMAC_TX_EN | |
| 19 | TX0 | EMAC_TXD0 | |
| 22 | TX1 | EMAC_TXD1 | |
| 25 | RX0 | EMAC_RXD0 | |
| 26 | RX1 | EMAC_RXD1 | |
| 27 | CRS_DV | EMAC_RX_DRV | |

## RMII PHY SMI Wiring

The following PHY connections are required for RMII PHY SMI (aka MDIO) management interface. These GPIO pin assignments can be changed to any unused GPIO pin.

For the example, these pins are configured via `make menuconfig` under the Example configuration.

| Default Example GPIO | RMII Signal | Notes |
| --- | --- | --- |
| 23 | MDC | Output to PHY |
| 18 | MDIO | Bidirectional |

The defaults in the customized example are correct for Olimex EVB-REV-B Ethernet IoT board with CAN.

## Note about GPIO0

Because GPIO0 is a strapping pin for entering UART flashing mode on reset, care must be taken when also using this pin as EMAC_TX_CLK. If the clock output from the PHY is oscillating during reset, the ESP32 may randomly enter UART flashing mode.

One solution is to use an additional GPIO as a "power pin", which either powers the PHY on/off or enables/disables the PHY's own oscillator. This prevents the clock signal from being active during a system reset. For this configuration to work, GPIO0 also needs a pullup resistor and the "power pin" GPIO will need a pullup/pulldown resistor - as appropriate in order to keep the PHY clock disabled when the ESP32 is in reset.

See the example source code to see how the "power pin" GPIO can be managed in software.

To using GPIO 17 for this function can be overriden. Example on Espressif's Ethernet development board, GPIO 17 is the power pin used to enable/disable the PHY oscillator.

On Olimex ESP32 EVB REV B IoT LAN8710 PHY Board with CAN there is a own solution from Olimex.
For deeper Information look in the Hardware folder on Olimex Github. There is the Shematic.
Also there is the HDK with board pcb and other design Informations.

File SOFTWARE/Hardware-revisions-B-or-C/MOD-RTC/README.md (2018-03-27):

Demo example for Olimex ESP32-GATEWAY with Olimex MOD-RTC.

Used I2C-1 for communication between the host board and the module. You can find more information in the comments in the main.c file.

After programming on the terminal you will see the date and time updated each second. By default it is set to 28 February 2020; 23:59:50 (you can change that in code).

Products used:

ESP32-GATEWAY: https://www.olimex.com/Products/IoT/ESP32-GATEWAY/open-source-hardware

MOD-RTC: https://www.olimex.com/Products/Modules/Time/MOD-RTC/open-source-hardware

Hardware setup:

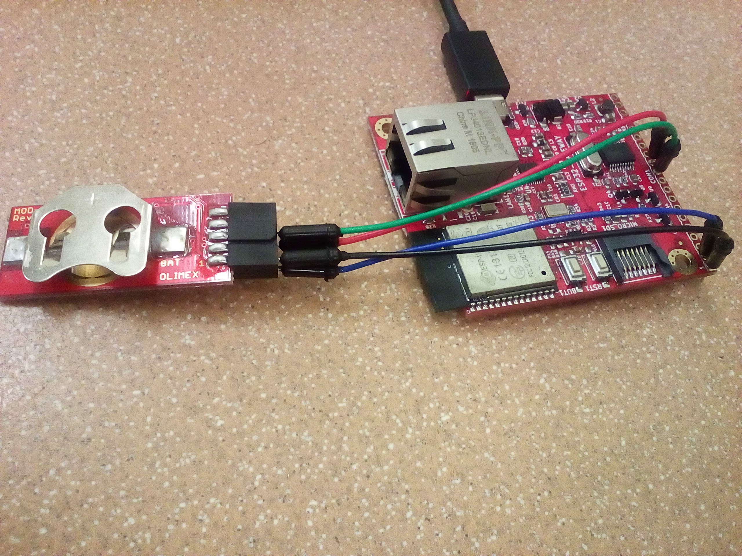
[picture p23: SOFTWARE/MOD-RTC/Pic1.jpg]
Hardware setup


Hardware setup2

Stanimir Petev
2018/03/27

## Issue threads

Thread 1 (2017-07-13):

Error when open project with Kicad version 4.0.6

hainv1990, 2017-07-13:
Dear Olimex,

I downloaded your hardware design and open project with Kicad v4.0.6 (newest).
But when I try to open kicad_pcb file. I receive an "error loading board. Kicad was unable to open this file... Date of kicad required (or newer): 01/23/2017"
Please help me how i can open this file. What version of kicad you are using.
Thanks alot.

DanKoloff, 2017-07-14:
The error message is pretty self-explanatory. Please use a version of KiCad that was released after 23d of January 2017. Use the latest nightly build of KiCad.

Yes, 4.0.6 is the latest stable release of KiCad but we are a major feedback contributor and we use the latest nightly builds so we can provide the KiCad team with information about behavior of latest release. We often report bugs and issues. We often request features. Not a lot of companies create such complex designs (let alone open-hardware ones) with KiCad and our expertise is important to keep KiCad moving forward.

andrewmarles, 2018-03-21:
Should probably make mention of this in the readme for your project.  Most professional developers use release versions of tools, not experimental.

Closed 2018-10-02.

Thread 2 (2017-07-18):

No Code in software folder

pranaysharma, 2017-07-18:
Hi there is no code in the software folder of the repo?
Is this an error form my side or the software/samples are not ready yet

DanKoloff, 2018-03-27:
Code now uploaded and tested.

Closed 2018-03-27.

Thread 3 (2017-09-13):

Ethernet not working properly?

magnifikus, 2017-09-13:
Trying to get the Gateway up with the ESP32-EVB PHY Example
1. i need to enable the layer 2->3 copy in the phy settings or i get emac rx error!! on every packet on ethernet
2. the board is not getting any dhcp address, sniffing the ethernet i not even see an outgoing dhcp request

any ideas?

DanKoloff, 2017-09-14:
The IDF changed and this issue appeared. Until we fix it, use the workaround provided by user "wobaekat" in the forums: https://www.olimex.com/forum/index.php?topic=5891.0

DanKoloff, 2018-03-27:
The examples had been updated and should work properly with the latest ESP-IDF without problems.

Closed 2018-10-02.

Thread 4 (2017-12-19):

Not receiving DHCP after hard reset and soft reboot on screen

Smeedy, 2017-12-19:
First off, nice work. I'm really fond of the design as we need a board to operate as a gateway in an industrial environment where WiFi is not an option. I'm testing a specimen of the rev-b which works ok'ish, but is seems a little flaky. Hope this is a case of change-user.

When I build the ethernet example from the IDF (v3.1-dev-84-gf8bda324) and use the following options I get an IP
```
#
# Example Configuration
#
CONFIG_PHY_TLK110=
CONFIG_PHY_LAN8720=y
CONFIG_PHY_ADDRESS=0
CONFIG_PHY_CLOCK_GPIO0_IN=y
CONFIG_PHY_CLOCK_GPIO0_OUT=
CONFIG_PHY_CLOCK_GPIO16_OUT=
CONFIG_PHY_CLOCK_GPIO17_OUT=
CONFIG_PHY_CLOCK_MODE=0
CONFIG_PHY_USE_POWER_PIN=
CONFIG_PHY_SMI_MDC_PIN=23
CONFIG_PHY_SMI_MDIO_PIN=18
```
But something is off as it seems. When I do a power cycle or a hard button reset, it fails to get an IP from the DHCP server (loops 0.0.0.0). When I do a `make monitor` or the trusted `screen /dev/cu.wchusbserial1410 115200` the device does a soft reboot and then I get an IP in the second loop and everything is fine.

What am I missing?

DanKoloff, 2017-12-20:
I can't say exactly but some suggestions that might help you debug the issue. Are you trying to get IP from Ethernet or WIFI DHCP server? Does this happen sometimes or every time? Have you tried with another piece of network equipment (can it be related to the DHCP server)? Can you try using the Arduno example (this might be the easiest way to determine if it is purely software issue)?

Closed 2018-10-02.

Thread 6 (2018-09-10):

Gateway bluetooth - wifi / lan example with mqtt

Netoperz, 2018-09-10:
Is it possible to get a demo sketch for arduino, that will use gateway board as BLE serial <==> wifi/lan gateway ?

i would like to see the bluetooth wifi lan running in tasks in arduino ide.

DO You have any suggestions how to do that ?

DanKoloff, 2019-07-16:
Doesn't look like an issue to me.

Closed 2019-07-16.

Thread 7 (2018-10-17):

Rev C board does not work with ETH_PHY_demo out of the box

jcwren, 2018-10-17:
Installed esp-idf v3.1 SDK and the xtensa-exp32-elf toolchain. Cloned the ESP32-GATEWAY project. Built the ETH_PHY_demo with the defaults as specified in the README.me file, and flashed the board. Board is coming up, sees the link is up, but never DHCPs an address. A couple of other Ethernet devices I have correctly DHCP on this same cable.

Green LED is on solid, yellow LED is blinking.

Do any changes need to be made to the configuration between the rev B and rev C versions?

Edit: Board is connected to a gigabit switch, but I also tried a 10/100 switch. Same problem.

```
$ make monitor
MONITOR
--- WARNING: Serial ports accessed as /dev/tty.* will hang gdb if launched.
--- Using /dev/cu.usbserial-1430 instead...
--- idf_monitor on /dev/cu.usbserial-1430 115200 ---
--- Quit: Ctrl+] | Menu: Ctrl+T | Help: Ctrl+T followed by Ctrl+H ---
ets Jun  8 2016 00:22:57

rst:0x1 (POWERON_RESET),boot:0x1b (SPI_FAST_FLASH_BOOT)
configsip: 0, SPIWP:0xee
clk_drv:0x00,q_drv:0x00,d_drv:0x00,cs0_drv:0x00,hd_drv:0x00,wp_drv:0x00
mode:DIO, clock div:2
load:0x3fff0018,len:4
load:0x3fff001c,len:5712
ho 0 tail 12 room 4
load:0x40078000,len:9020
load:0x40080000,len:6064
0x40080000: _iram_start at /Users/jcw/Projects/esp-idf/components/freertos/xtensa_vectors.S:1685

entry 0x40080330
0x40080330: _KernelExceptionVector at ??:?

I (30) boot: ESP-IDF v3.1 2nd stage bootloader
I (30) boot: compile time 12:33:38
I (30) boot: Enabling RNG early entropy source...
I (35) boot: SPI Speed      : 40MHz
I (39) boot: SPI Mode       : DIO
I (43) boot: SPI Flash Size : 4MB
I (47) boot: Partition Table:
I (51) boot: ## Label            Usage          Type ST Offset   Length
I (58) boot:  0 nvs              WiFi data        01 02 00009000 00006000
I (65) boot:  1 phy_init         RF data          01 01 0000f000 00001000
I (73) boot:  2 factory          factory app      00 00 00010000 00100000
I (80) boot: End of partition table
I (84) esp_image: segment 0: paddr=0x00010020 vaddr=0x3f400020 size=0x0bd10 ( 48400) map
I (110) esp_image: segment 1: paddr=0x0001bd38 vaddr=0x3ffb0000 size=0x022d0 (  8912) load
I (114) esp_image: segment 2: paddr=0x0001e010 vaddr=0x3ffb22d0 size=0x00000 (     0) load
I (117) esp_image: segment 3: paddr=0x0001e018 vaddr=0x40080000 size=0x00400 (  1024) load
0x40080000: _iram_start at /Users/jcw/Projects/esp-idf/components/freertos/xtensa_vectors.S:1685

I (126) esp_image: segment 4: paddr=0x0001e420 vaddr=0x40080400 size=0x01bf0 (  7152) load
I (138) esp_image: segment 5: paddr=0x00020018 vaddr=0x400d0018 size=0x27718 (161560) map
0x400d0018: _stext at ??:?

I (200) esp_image: segment 6: paddr=0x00047738 vaddr=0x40081ff0 size=0x06fe0 ( 28640) load
0x40081ff0: esp_clk_apb_freq at /Users/jcw/Projects/esp-idf/components/esp32/clk.c:179

I (213) esp_image: segment 7: paddr=0x0004e720 vaddr=0x400c0000 size=0x00000 (     0) load
I (213) esp_image: segment 8: paddr=0x0004e728 vaddr=0x50000000 size=0x00000 (     0) load
I (225) boot: Loaded app from partition at offset 0x10000
I (225) boot: Disabling RNG early entropy source...
I (231) cpu_start: Pro cpu up.
I (235) cpu_start: Starting app cpu, entry point is 0x40080e9c
0x40080e9c: call_start_cpu1 at /Users/jcw/Projects/esp-idf/components/esp32/cpu_start.c:225

I (0) cpu_start: App cpu up.
I (245) heap_init: Initializing. RAM available for dynamic allocation:
I (252) heap_init: At 3FFAE6E0 len 00001920 (6 KiB): DRAM
I (258) heap_init: At 3FFBC3A0 len 00023C60 (143 KiB): DRAM
I (264) heap_init: At 3FFE0440 len 00003BC0 (14 KiB): D/IRAM
I (270) heap_init: At 3FFE4350 len 0001BCB0 (111 KiB): D/IRAM
I (277) heap_init: At 40088FD0 len 00017030 (92 KiB): IRAM
I (283) cpu_start: Pro cpu start user code
I (301) cpu_start: Starting scheduler on PRO CPU.
I (0) cpu_start: Starting scheduler on APP CPU.
I (304) system_api: Base MAC address is not set, read default base MAC address from BLK0 of EFUSE
I (304) emac: emac start !!!

I (314) emac: emac reset done
I (454) emac: emac start success !!!
I (4454) Olimex_ESP32_GATEWAY_REV_B_eth_example: ~~~~~~~~~~~
I (4454) Olimex_ESP32_GATEWAY_REV_B_eth_example: ETHIP:0.0.0.0
I (4454) Olimex_ESP32_GATEWAY_REV_B_eth_example: ETHPMASK:0.0.0.0
I (4454) Olimex_ESP32_GATEWAY_REV_B_eth_example: ETHPGW:0.0.0.0
I (4464) Olimex_ESP32_GATEWAY_REV_B_eth_example: ~~~~~~~~~~~
I (4474) emac: eth link_up!!!
I (6474) Olimex_ESP32_GATEWAY_REV_B_eth_example: ~~~~~~~~~~~
I (6474) Olimex_ESP32_GATEWAY_REV_B_eth_example: ETHIP:0.0.0.0
I (6474) Olimex_ESP32_GATEWAY_REV_B_eth_example: ETHPMASK:0.0.0.0
I (6474) Olimex_ESP32_GATEWAY_REV_B_eth_example: ETHPGW:0.0.0.0
I (6484) Olimex_ESP32_GATEWAY_REV_B_eth_example: ~~~~~~~~~~~
<repeats endlessly>
```

jtarazonaf, 2018-12-19:
Same problem

hoene, 2019-01-13:
The current changes in revision D and E to solve this problem are not good either.
GPIO17 and GPIO5 are getting useless and we do not have any replacement on the GPIO header.

DanKoloff, 2019-01-14:
We are, indeed, considering reducing the 4-bit SD to 1-bit SD as in ESP32-EVB and ESP32-PoE. It is in our TODO notes for the next hardware revision of ESP32-GATEWAY. This would free some pins that were used for the Ethernet reset control and clock.

We were forced to have a custom delay circuit in ESP32-EVB since we had no free pins, and we still utilize the clock delay in ESP32-EVB. However, there is no need of such circuit in ESP32-PoE or ESP32-GATEWAY (since we have free GPIO pins). The clock circuit in ESP32-PoE is similar to the circuits of other manufacturers of ESP32 boards with Ethernet, so it should be easier to get it working.

As @hoene noticed in revision D and newer of ESP32-GATEWAY and all revisions of ESP32-PoE the Ethernet requires two extra pins - a power control pin and the Ethernet clock pin. In ESP32-GATEWAY the power control pin is GPIO5 and in ESP32-PoE (the example you linked) the power control pin is GPIO12. The Ethernet clock pin is GPIO17. This is also written in the hardware changes here: https://github.com/OLIMEX/ESP32-GATEWAY/tree/master/HARDWARE

For ESP32-GATEWAY you should edit these definitions in Arduino for ESP32:

#define ETH_CLK_MODE ETH_CLOCK_GPIO17_OUT
#define ETH_PHY_POWER 5

DanKoloff, 2020-07-17:
We made separate folders for older and newer revisions, there is also an Ethernet example for version 4.0 of the toolchain. The main folder now has two sub-folders "Hardware-revisions-B-or-C" and "Newest-board-revisions".

https://github.com/OLIMEX/ESP32-GATEWAY/tree/master/SOFTWARE

Closed 2020-07-17.

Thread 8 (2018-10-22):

ble scan performance?

4nte, 2018-10-22:
Are there any testing results with this gateway? I'm specifically interested in how much BLE devices can be scanned in a 2-5 second interval.
I have my own esp32 gateway which only scans 10-30beacons in 2sec scanning period, while there is 60+ beacons nearby.

** If I disable WIFI, the BT scan works perfectly, this is a known ESP32 problem.

DanKoloff, 2020-07-17:
The BLE is part of the ESP32 module and performance is pretty much the same as advertised by espressif. You should check for the specs in this official FAQ file here: https://www.espressif.com/sites/default/files/documentation/ESP32_FAQs__EN.pdf

Closed 2020-07-17.

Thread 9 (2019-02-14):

Using two SPI buses

wcpettus, 2019-02-14:
I'm trying to configure an ESP32-Gateway to talk with an SPI device.  I feel I must be missing something about the hardware configuration.

I've started with the SPI_Multiple_Buses example code, but the default pins for VSPI (18,19,23,5) and HSPI (14,12,13,15) are mostly not exposed to the extension headers.  Consulting the schematic (I'm using a rev C) I have access to
GPIO 5,16,17,32,33
GPI 34,35,36,39
Debug only 6,7,8,9,10,11

I've verified I can see SPI signals on the 5 pins I have access to, I'm explicitly told to skip the 6 SD-related pins, and the other 4 are input only?  That seems like a waste of header real estate, and how can one operate two SPI buses concurrently (alternatively this would limit the number of SS pins for a single SPI bus)?

Probably some trivial ignorance on my part?

DrTester0x42, 2019-07-19:
@wcpettus This is a good question have you found the answer to this yet?

Looking at the boards headers I am not seeing any dedicated SPI ports. What are your thoughts? @TsvetanUsunov

wcpettus, 2019-07-19:
I would love to know the answer.  I also tried asking on the forums but never heard anything back:
https://www.olimex.com/forum/index.php?topic=7090.0

drdelgado, 2019-09-13:
@wcpettus were you able to get SPI peripheral + ethernet functionality working?

wcpettus, 2019-09-13:
that's right - I've been using an SPI to communicate with an ADC and ethernet to readout the data

drdelgado, 2019-09-19:
@wcpettus any chance you'd be willing to share your code?

fightforlife, 2023-03-11:
I would also love to hear how an external SPI Device can be User with this Board? ( HSPI and VSPI seems Not to be available in the Header)

wcpettus, 2023-03-12:
Prefaced with the disclaimer that I don't think this is the final code version, but this is what I found digging through old code directories; clearly I should have documented better and answered 3.5 years ago when the original question was fresh (or made the undergrad who was doing the implementation do so :D)

This at least seems to work with an ADC, use SPI, and have ethernet functionality.

```arduino
include <MCP3XXX.h>
 #include <ETH.h>

 //Define ADC interfaces
 #define CS_PIN 5     // ESP8266 default SPI pins
 #define CLK_PIN 32  // Should work with any other GPIO pins, since the library does not formally
 #define MOSI_PIN 16   // use SPI, but rather performs pin bit banging to emulate SPI communication.
 #define MISO_PIN 17   //
 MCP3204 adc;

 //Define network settings
 static bool eth_connected = false;
 IPAddress ip(10, 0, 0, 2);
 IPAddress gate(10, 0, 0, 1);
 IPAddress mask(255, 255, 255, 0);

 //Define telnet server parameters
 #define MAX_SRV_CLIENTS 4
 WiFiServer server(23);
 WiFiClient serverClients[MAX_SRV_CLIENTS];
 const byte charLim = 32;
 const char terminator = '\n';

 void WiFiEvent(WiFiEvent_t event)
 {
   switch (event) {
     case SYSTEM_EVENT_ETH_START:
       Serial.println("ETH Started");
       //set eth hostname here
       ETH.setHostname("arduino1");
       break;
     case SYSTEM_EVENT_ETH_CONNECTED:
       Serial.println("ETH Connected");
       break;
     case SYSTEM_EVENT_ETH_GOT_IP:
       Serial.print("ETH MAC: ");
       Serial.print(ETH.macAddress());
       Serial.print(", IPv4: ");
       Serial.print(ETH.localIP());
       if (ETH.fullDuplex()) Serial.print(", FULL_DUPLEX");
       Serial.print(", ");
       Serial.print(ETH.linkSpeed());
       Serial.println("Mbps");
       eth_connected = true;
       break;
     case SYSTEM_EVENT_ETH_DISCONNECTED:
       Serial.println("ETH Disconnected");
       eth_connected = false;
       break;
     case SYSTEM_EVENT_ETH_STOP:
       Serial.println("ETH Stopped");
       eth_connected = false;
       break;
     default:
       break;
   }
 }

 void setup()
 {
   Serial.begin(115200);

   WiFi.onEvent(WiFiEvent);
   ETH.begin();
   ETH.config(ip, gate, mask, gate);
   server.begin();
   server.setNoDelay(true);
   Serial.println("network and server setup initialized");
   adc.begin(CS_PIN, MOSI_PIN, MISO_PIN, CLK_PIN);
   Serial.println("setup done");
 }

 // function to handle new connections
 void handle_connection()
 {
   uint8_t i;
   if (server.hasClient()) {
     for (i = 0; i < MAX_SRV_CLIENTS; i++) {
       //find free/disconnected spot
       if (!serverClients[i] || !serverClients[i].connected()) {
         if (serverClients[i]) serverClients[i].stop();
         serverClients[i] = server.available();
         if (!serverClients[i]) Serial.println("available broken");
         Serial.print("New client: ");
         Serial.print(i); Serial.print(' ');
         Serial.println(serverClients[i].remoteIP());
         serverClients[i].print("You are connection ");
         serverClients[i].print(i); serverClients[i].print(" to ");
         serverClients[i].println(ETH.getHostname());
         serverClients[i].print(">");
         //flush input buffer on connection
         while (serverClients[i].available()) serverClients[i].read();
         break;
       }
     }
     if (i >= MAX_SRV_CLIENTS) {
       //no free/disconnected spot so reject
       server.available().stop();
     }
   }
 }

 // function to read commands from controls
 void read_connection()
 {
   uint8_t i;
   for (i = 0; i < MAX_SRV_CLIENTS; i++) {
     if (serverClients[i] && serverClients[i].connected()) {
       if (serverClients[i].available()) {
         char input[charLim + 2];
         uint8_t nRx = 0;
         bool incomplete = true;
         while (serverClients[i].available()) {
           input[nRx] = serverClients[i].read();
           if (input[nRx] == terminator) {
             input[nRx + 2] = '\0';
             parse_command(&serverClients[i], input);
             incomplete = false;
             break;
           } else if (nRx < charLim) {
             nRx ++;
           }
         }
         if (incomplete) serverClients[i].println("ERROR: Incomplete transmission");
       }
     }
     else {
       if (serverClients[i]) serverClients[i].stop();
     }
   }
 }

 // funtion to interpret received command
 void parse_command(WiFiClient *client, char *input)
 {
   Serial.print("Received command: ");
   Serial.println(input);
   client->print(input);
   switch (input[0]) {
     // READ option, <RN>, return ADC input N value
     case 'R':
       measurement(client, input[1] - '0'); // expect a uint8_t
       break;
     // TEST option, <T> return 1
     case 'T':
       client->println(1);
       break;
     default:
       client->println("ERROR: Invalid command");
       break;
   }
   client->print(">");
 }

 // function to record measurements from a coldhead ADC
 void measurement(WiFiClient *client, uint8_t chanID)
 {
   if (chanID > 3) return;
   client->print("Ch: ");
   client->print(chanID);
   client->print("; Val: ");
   client->println(adc.analogRead(chanID));
 }

 void loop()
 {
   if (eth_connected) {
     //check if there are any new clients
     handle_connection();
     //check clients for data
     read_connection();
   } else {
     Serial.println("ETH not connected!");
     delay(100);
     for (uint8_t i = 0; i < MAX_SRV_CLIENTS; i++) {
       if (serverClients[i]) serverClients[i].stop();
     }
   }
 }
 ```

fightforlife, 2023-03-12:
Thanks you very much for the example of using Software SPI/bitbanging.
While checking the Docs I found that the Hardware HSPI Pins are available on the header in newer Board revisions. (But then ofcourse you can Not use the sdcard at the same time).

Closed 2023-04-26.

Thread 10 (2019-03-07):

ETH_PHY_demo cannot work with rev E board

avalla, 2019-03-07:
Hello,
I cannot make the example work with REV E board.
I also tried with ESP32-EVB example, but the result is the same

```
[Mar  7 11:03:21.069] I (28) boot: ESP-IDF v3.1.3 2nd stage bootloader
[Mar  7 11:03:21.079] I (28) boot: compile time 09:44:15
[Mar  7 11:03:21.082] I (28) boot: Enabling RNG early entropy source...
[Mar  7 11:03:21.087] I (33) boot: SPI Speed      : 40MHz
[Mar  7 11:03:21.090] I (37) boot: SPI Mode       : DIO
[Mar  7 11:03:21.096] I (41) boot: SPI Flash Size : 4MB
[Mar  7 11:03:21.098] I (45) boot: Partition Table:
[Mar  7 11:03:21.104] I (49) boot: ## Label            Usage          Type ST Offset   Length
[Mar  7 11:03:21.110] I (56) boot:  0 nvs              WiFi data        01 02 00009000 00006000
[Mar  7 11:03:21.118] I (63) boot:  1 phy_init         RF data          01 01 0000f000 00001000
[Mar  7 11:03:21.126] I (71) boot:  2 factory          factory app      00 00 00010000 00100000
[Mar  7 11:03:21.132] I (78) boot: End of partition table
[Mar  7 11:03:21.137] I (82) esp_image: segment 0: paddr=0x00010020 vaddr=0x3f400020 size=0x0d8d8 ( 55512) map
[Mar  7 11:03:21.154] I (111) esp_image: segment 1: paddr=0x0001d900 vaddr=0x3ffb0000 size=0x022dc (  8924) load
[Mar  7 11:03:21.162] I (115) esp_image: segment 2: paddr=0x0001fbe4 vaddr=0x40080000 size=0x00400 (  1024) load
[Mar  7 11:03:21.171] I (118) esp_image: segment 3: paddr=0x0001ffec vaddr=0x40080400 size=0x00024 (    36) load
[Mar  7 11:03:21.182] I (127) esp_image: segment 4: paddr=0x00020018 vaddr=0x400d0018 size=0x277e8 (161768) map
[Mar  7 11:03:21.237] I (192) esp_image: segment 5: paddr=0x00047808 vaddr=0x40080424 size=0x08dc0 ( 36288) load
[Mar  7 11:03:21.257] I (213) boot: Loaded app from partition at offset 0x10000
[Mar  7 11:03:21.263] I (213) boot: Disabling RNG early entropy source...
[Mar  7 11:03:21.268] I (214) cpu_start: Pro cpu up.
[Mar  7 11:03:21.271] I (217) cpu_start: Starting app cpu, entry point is 0x40080eb4
[Mar  7 11:03:21.279] I (0) cpu_start: App cpu up.
[Mar  7 11:03:21.282] I (228) heap_init: Initializing. RAM available for dynamic allocation:
[Mar  7 11:03:21.288] I (234) heap_init: At 3FFAE6E0 len 00001920 (6 KiB): DRAM
[Mar  7 11:03:21.296] I (240) heap_init: At 3FFBC3B8 len 00023C48 (143 KiB): DRAM
[Mar  7 11:03:21.302] I (247) heap_init: At 3FFE0440 len 00003BC0 (14 KiB): D/IRAM
[Mar  7 11:03:21.307] I (253) heap_init: At 3FFE4350 len 0001BCB0 (111 KiB): D/IRAM
[Mar  7 11:03:21.315] I (260) heap_init: At 400891E4 len 00016E1C (91 KiB): IRAM
[Mar  7 11:03:21.321] I (266) cpu_start: Pro cpu start user code
[Mar  7 11:03:21.326] I (284) cpu_start: Starting scheduler on PRO CPU.
[Mar  7 11:03:21.332] I (0) cpu_start: Starting scheduler on APP CPU.
[Mar  7 11:03:21.338] I (287) system_api: Base MAC address is not set, read default base MAC address from BLK0 of EFUSE
[Mar  7 11:03:21.349] I (287) emac: emac start !!!
[Mar  7 11:03:21.351]
[Mar  7 11:03:21.351] I (297) emac: emac reset done
[Mar  7 11:03:22.339] E (1297) emac: Timed out waiting for PHY register 0x2 to have value 0x0007 (mask 0xffff). Current value 0xffff
[Mar  7 11:03:23.339] E (2297) emac: Timed out waiting for PHY register 0x3 to have value 0xc0f0 (mask 0xfff0). Current value 0xffff
[Mar  7 11:03:24.339] E (3297) emac: Timed out waiting for PHY register 0x2 to have value 0x0007 (mask 0xffff). Current value 0xffff
[Mar  7 11:03:25.339] E (4297) emac: Timed out waiting for PHY register 0x3 to have value 0xc0f0 (mask 0xfff0). Current value 0xffff
[Mar  7 11:03:26.339] E (5297) emac: Timed out waiting for PHY register 0x2 to have value 0x0007 (mask 0xffff). Current value 0xffff
[Mar  7 11:03:27.339] E (6297) emac: Timed out waiting for PHY register 0x3 to have value 0xc0f0 (mask 0xfff0). Current value 0xffff
[Mar  7 11:03:28.339] E (7297) emac: Timed out waiting for PHY register 0x2 to have value 0x0007 (mask 0xffff). Current value 0xffff
[Mar  7 11:03:29.339] E (8297) emac: Timed out waiting for PHY register 0x3 to have value 0xc0f0 (mask 0xfff0). Current value 0xffff
[Mar  7 11:03:30.339] E (9297) emac: Timed out waiting for PHY register 0x2 to have value 0x0007 (mask 0xffff). Current value 0xffff
[Mar  7 11:03:31.339] E (10297) emac: Timed out waiting for PHY register 0x3 to have value 0xc0f0 (mask 0xfff0). Current value 0xffff
```

avalla, 2019-03-07:
I found the trick, the configuration was wrong, the right one is the following (using esp-idf ethernet example):

```
CONFIG_PHY_TLK110=
CONFIG_PHY_LAN8720=y
CONFIG_PHY_ADDRESS=0
CONFIG_PHY_CLOCK_GPIO0_IN=
CONFIG_PHY_CLOCK_GPIO0_OUT=
CONFIG_PHY_CLOCK_GPIO16_OUT=
CONFIG_PHY_CLOCK_GPIO17_OUT=y
CONFIG_PHY_CLOCK_MODE=3
CONFIG_PHY_USE_POWER_PIN=y
CONFIG_PHY_POWER_PIN=17
CONFIG_PHY_SMI_MDC_PIN=23
CONFIG_PHY_SMI_MDIO_PIN=18
```

Closed 2019-03-07.

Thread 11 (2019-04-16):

Power consumption for Deep sleep mode

david711205, 2019-04-16:
Hi
Have you ever measured power consumption of the device on deep sleep mode?
Could you provide the measurement result?

DanKoloff, 2020-07-17:
Revsion F of ESP32-GATEWAY consumes around 100uA in deep sleep mode.

Closed 2020-07-17.

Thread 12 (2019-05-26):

Serial Interface with Rev E

sammer-h, 2019-05-26:
Hello.

First I used Rev B for an application which needs two serial ports.
One for communication with an other device, the second for flash and monitor and CLI.

But with Rev E Uart2 is not usable because Pin 17 is clock output for  ETH
and Pins for Uart1 seem to be used for internal purpose.

Is there any solution for this problem.

Thank for any ideas.

DanKoloff, 2019-05-27:
You can configure another pin for UART2. What environment do you use?

sammer-h, 2019-05-27:
Thank you for the fast reply.
I found the answer in the documentation, too.
Enviroment: Linux with newest esp-idf.

DanKoloff, 2019-05-27:
Glad you got it going. Closing the issue as solved.

Closed 2019-05-27.

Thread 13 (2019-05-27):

ETH Example Never Aquires IP

drdelgado, 2019-05-27:
Plugged ethernet cable into my belkin router, and I continueously see the following message for the ETH example (https://github.com/OLIMEX/ESP32-GATEWAY/tree/master/SOFTWARE/Newest-board-revisions/ETH_PHY_demo):

```
053) Olimex_ESP32_GATEWAY_REV_B_eth_example: ETHIP:0.0.0.0
I (55053) Olimex_ESP32_GATEWAY_REV_B_eth_example: ETHPMASK:0.0.0.0
I (55053) Olimex_ESP32_GATEWAY_REV_B_eth_example: ETHPGW:0.0.0.0
I (55063) Olimex_ESP32_GATEWAY_REV_B_eth_example: ~~~~~~~~~~~
I (57073) Olimex_ESP32_GATEWAY_REV_B_eth_example: ~~~~~~~~~~~
I (57073) Olimex_ESP32_GATEWAY_REV_B_eth_example: ETHIP:0.0.0.0
I (57073) Olimex_ESP32_GATEWAY_REV_B_eth_example: ETHPMASK:0.0.0.0
I (57073) Olimex_ESP32_GATEWAY_REV_B_eth_example: ETHPGW:0.0.0.0
I (57083) Olimex_ESP32_GATEWAY_REV_B_eth_example: ~~~~~~~~~~~
I (59093) Olimex_ESP32_GATEWAY_REV_B_eth_example: ~~~~~~~~~~~
I (59093) Olimex_ESP32_GATEWAY_REV_B_eth_example: ETHIP:0.0.0.0
```

never gets an IP what steps do I need to take to ensure IP connection

drdelgado, 2019-05-27:
@Stanimir-Petev

DanKoloff, 2019-05-28:
It is probably something in your hardware setup or network configuration (firewall, improper settings, routing, etc). We tested the demo for the newer revisions with board from revision E today - it works fine and acquires IP. Please notice that each ESP32-GATEWAY board pass an Ethernet test after manufacturing. This is the log from our test:

```
# make monitor
MONITOR
--- idf_monitor on COM81 115200 ---
--- Quit: Ctrl+] | Menu: Ctrl+T | Help: Ctrl+T followed by Ctrl+H ---
ets Jun  8 2016 00:22:57

rst:0x1 (POWERON_RESET),boot:0x1a (SPI_FAST_FLASH_BOOT)
configsip: 0, SPIWP:0xee
clk_drv:0x00,q_drv:0x00,d_drv:0x00,cs0_drv:0x00,hd_drv:0x00,wp_drv:0x00
mode:DIO, clock div:2
load:0x3fff0018,len:4
load:0x3fff001c,len:5788
load:0x40078000,len:9176
load:0x40080000,len:6008
0x40080000: _iram_start at C:/esp/esp-idf/components/freertos/xtensa_vectors.S:1685

entry 0x4008032c
0x4008032c: _KernelExceptionVector at ??:?

I (28) boot: ESP-IDF v3.1.2-dirty 2nd stage bootloader
I (29) boot: compile time 09:13:10
I (29) boot: Enabling RNG early entropy source...
I (34) boot: SPI Speed      : 40MHz
I (38) boot: SPI Mode       : DIO
I (42) boot: SPI Flash Size : 4MB
I (46) boot: Partition Table:
I (49) boot: ## Label            Usage          Type ST Offset   Length
I (57) boot:  0 nvs              WiFi data        01 02 00009000 00006000
I (64) boot:  1 phy_init         RF data          01 01 0000f000 00001000
I (72) boot:  2 factory          factory app      00 00 00010000 00100000
I (79) boot: End of partition table
I (83) esp_image: segment 0: paddr=0x00010020 vaddr=0x3f400020 size=0x0bc94 ( 48276) map
I (109) esp_image: segment 1: paddr=0x0001bcbc vaddr=0x3ffb0000 size=0x022a0 (  8864) load
I (113) esp_image: segment 2: paddr=0x0001df64 vaddr=0x3ffb22a0 size=0x00000 (     0) load
I (116) esp_image: segment 3: paddr=0x0001df6c vaddr=0x40080000 size=0x00400 (  1024) load
0x40080000: _iram_start at C:/esp/esp-idf/components/freertos/xtensa_vectors.S:1685

I (125) esp_image: segment 4: paddr=0x0001e374 vaddr=0x40080400 size=0x01c9c (  7324) load
I (137) esp_image: segment 5: paddr=0x00020018 vaddr=0x400d0018 size=0x2788c (161932) map
0x400d0018: _stext at ??:?

I (199) esp_image: segment 6: paddr=0x000478ac vaddr=0x4008209c size=0x07040 ( 28736) load
0x4008209c: _xt_panic at C:/esp/esp-idf/components/freertos/xtensa_vectors.S:361

I (211) esp_image: segment 7: paddr=0x0004e8f4 vaddr=0x400c0000 size=0x00000 (     0) load
I (212) esp_image: segment 8: paddr=0x0004e8fc vaddr=0x50000000 size=0x00000 (     0) load
I (224) boot: Loaded app from partition at offset 0x10000
I (224) boot: Disabling RNG early entropy source...
I (230) cpu_start: Pro cpu up.
I (233) cpu_start: Starting app cpu, entry point is 0x40080ea0
0x40080ea0: call_start_cpu1 at C:/esp/esp-idf/components/esp32/cpu_start.c:231

I (0) cpu_start: App cpu up.
I (244) heap_init: Initializing. RAM available for dynamic allocation:
I (251) heap_init: At 3FFAE6E0 len 00001920 (6 KiB): DRAM
I (257) heap_init: At 3FFBC380 len 00023C80 (143 KiB): DRAM
I (263) heap_init: At 3FFE0440 len 00003BC0 (14 KiB): D/IRAM
I (269) heap_init: At 3FFE4350 len 0001BCB0 (111 KiB): D/IRAM
I (276) heap_init: At 400890DC len 00016F24 (91 KiB): IRAM
I (282) cpu_start: Pro cpu start user code
I (300) cpu_start: Starting scheduler on PRO CPU.
I (0) cpu_start: Starting scheduler on APP CPU.
I (321) system_api: Base MAC address is not set, read default base MAC address from BLK0 of EFUSE
I (321) emac: emac start !!!

I (321) emac: emac resetting ....
I (321) emac: emac reset done
I (341) emac: emac start success !!!
I (4341) emac: eth link_up!!!
I (4441) Olimex_ESP32_GATEWAY_REV_B_eth_example: ~~~~~~~~~~~
I (4441) Olimex_ESP32_GATEWAY_REV_B_eth_example: ETHIP:0.0.0.0
I (4441) Olimex_ESP32_GATEWAY_REV_B_eth_example: ETHPMASK:0.0.0.0
I (4441) Olimex_ESP32_GATEWAY_REV_B_eth_example: ETHPGW:0.0.0.0
I (4451) Olimex_ESP32_GATEWAY_REV_B_eth_example: ~~~~~~~~~~~
I (5311) event: eth ip: 192.168.0.148, mask: 255.255.255.0, gw: 192.168.0.1
I (6461) Olimex_ESP32_GATEWAY_REV_B_eth_example: ~~~~~~~~~~~
I (6461) Olimex_ESP32_GATEWAY_REV_B_eth_example: ETHIP:192.168.0.148
I (6461) Olimex_ESP32_GATEWAY_REV_B_eth_example: ETHPMASK:255.255.255.0
I (6461) Olimex_ESP32_GATEWAY_REV_B_eth_example: ETHPGW:192.168.0.1
I (6471) Olimex_ESP32_GATEWAY_REV_B_eth_example: ~~~~~~~~~~~
```

drdelgado, 2019-05-28:
@dankoloff what is your network setup here?

DanKoloff, 2019-05-29:
I am connected to TP-Link router with OpenWRT. It looks like this: https://i.imgur.com/TpNQMiH.png

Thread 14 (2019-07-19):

Maximum number of bluetooth pairing

DrTester0x42, 2019-07-19:
My issue is less of an issue and more of question, what is the maximum number of bluetooth devices that can be paired to a single ESP32 board?

DanKoloff, 2020-07-17:
By default it is 3 but it can be set in the (1-7) range.

Closed 2020-07-17.

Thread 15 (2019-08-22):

ETH_PHY_demo doesn't build

phibreDE, 2019-08-22:
The network classes have changed in the espressif esp-ide git and the example no longer builds.

`ESP32-GATEWAY/SOFTWARE/Newest-board-revisions/ETH_PHY_demo/main/ethernet_example_main.c:49:10: fatal error: eth_phy/phy_lan8720.h: No such file or directory
 #include "eth_phy/phy_lan8720.h"
`

Could you adapt the examples to the new toolchain?

DanKoloff, 2019-08-22:
Certainly looks like this one: https://github.com/OLIMEX/ESP32-POE/issues/7#issuecomment-523761856

We are aware of the issue that caused it. All ESP32 Ethernet demos of all boards are probably affected.

wlbe4, 2020-06-01:
When can we expect a fix so the examples can compile and run on new toolchain (v4.x)?

DanKoloff, 2020-07-17:
Such example is published here: https://github.com/OLIMEX/ESP32-GATEWAY/tree/master/SOFTWARE/Newest-board-revisions/ESP32_Gateway_Ethernet_v4.0

wlbe4, 2020-07-17:
Thanks

Closed 2020-07-17.

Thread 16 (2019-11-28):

Ethernet activity indicator flashes constantly when using wifi softAP

will-emmerson, 2019-11-28:
The yellow ethernet activity indicator flashes constantly when using softAP, even when sending or receiving no data. This may be a hardware problem specific to the boards I'm using, which are Olimex Gateway and Olimex PoE, I don't have access to any other ESP32 boards with ethernet.
Both ethernet and softAP still work fine, so it's not exactly a huge problem. I don't actually know whether it indicates some kind of network activity or if the light is just flashing for no reason.
Below is a minimal PoC to make it happen (for IDF master), which just uses the same code as the softAP and ethernet examples:

```C
#include <esp_eth.h>
#include <esp_eth_mac.h>
#include <esp_eth_phy.h>
#include <esp_log.h>
#include <esp_netif.h>
#include <esp_netif_defaults.h>
#include <esp_netif_types.h>
#include <esp_wifi.h>
#include <nvs_flash.h>

void internal_flash_init() {
    esp_err_t err = nvs_flash_init();
    if (err == ESP_ERR_NVS_NO_FREE_PAGES || err == ESP_ERR_NVS_NEW_VERSION_FOUND) {
        ESP_ERROR_CHECK(nvs_flash_erase());
        err = nvs_flash_init();
    }
    ESP_ERROR_CHECK(err);
}

void ethernet_init(void) {
    esp_netif_config_t cfg = ESP_NETIF_DEFAULT_ETH();
    esp_netif_t *eth_netif = esp_netif_new(&cfg);
    ESP_ERROR_CHECK(esp_eth_set_default_handlers(eth_netif));
    eth_mac_config_t mac_config = ETH_MAC_DEFAULT_CONFIG();
    esp_eth_mac_t *mac = esp_eth_mac_new_esp32(&mac_config);
    eth_phy_config_t phy_config = ETH_PHY_DEFAULT_CONFIG();
    phy_config.phy_addr = 0;
    esp_eth_phy_t *phy = esp_eth_phy_new_lan8720(&phy_config);
    esp_eth_config_t config = ETH_DEFAULT_CONFIG(mac, phy);
    esp_eth_handle_t eth_handle = NULL;
    ESP_ERROR_CHECK(esp_eth_driver_install(&config, &eth_handle));
    ESP_ERROR_CHECK(esp_netif_attach(eth_netif, eth_handle));
}

void wifi_softap_init(void) {
    esp_netif_create_default_wifi_ap();
    wifi_init_config_t cfg = WIFI_INIT_CONFIG_DEFAULT();
    ESP_ERROR_CHECK(esp_wifi_init(&cfg));
    ESP_ERROR_CHECK(esp_wifi_set_mode(WIFI_MODE_AP));
    wifi_config_t wifi_config = {.ap = {.authmode = WIFI_AUTH_OPEN, .max_connection=5,}};
    ESP_ERROR_CHECK(esp_wifi_set_config(ESP_IF_WIFI_AP, &wifi_config));
    ESP_ERROR_CHECK(esp_wifi_start());
}

void app_main() {
    internal_flash_init();
    esp_netif_init();
    ESP_ERROR_CHECK(esp_event_loop_create_default());
    ethernet_init();
    wifi_softap_init();
}
```

The ethernet is configured in the `sdkconfig.defaults` file:
```
CONFIG_ETH_ENABLED=y
CONFIG_ETH_USE_ESP32_EMAC=y
CONFIG_ETH_PHY_INTERFACE_RMII=y
CONFIG_ETH_RMII_CLK_OUTPUT=y
CONFIG_ETH_RMII_CLK_OUT_GPIO=17
CONFIG_ETH_SMI_MDC_GPIO=23
CONFIG_ETH_SMI_MDIO_GPIO=18
```

DanKoloff, 2023-04-27:
Activity indicator should blink when there is any communication going between the port and the network, which is usually all the times when things are working alright. If it stops blinking or lights off then there is a network problem.  LEDs are described in table 2-2 on page 11 of the Ethernet chip's (LAN8710) datasheet here: hhttps://ww1.microchip.com/downloads/en/DeviceDoc/00002164B.pdf

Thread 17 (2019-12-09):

Revision F hardware

ArendJan, 2019-12-09:
I recently bought a esp32 gateway revision F, but I am unable to find the correct schematics for that revision.
At least the pinout is different, but are there any other changes?

DanKoloff, 2019-12-09:
There are major changes in the hardware design. Differences to the pins at the GPIO header, 1-bit SD card mode now implemented, a lot of improvements for the power consumption during sleep and deep sleep! Added 3D view in the design files. I've added the resources and the differences now.

ArendJan, 2019-12-10:
Thanks!

Closed 2019-12-10.

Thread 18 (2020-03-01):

UART1

mikeme2009, 2020-03-01:

mikeme2009, 2020-03-01:
wire problem

Closed 2020-03-01.

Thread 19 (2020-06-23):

I2S codec?

serjepatoff, 2020-06-23:
Not an issue, just a question.

Is it possible to attach i2s audio in/out codec to ESP32-GATEWAY without clocking and pin assignment conflicts with EMAC? Something like Cirrus/Wolfson WM8731 audio ADC/DAC?

DanKoloff, 2023-04-26:
Sure, it seems the I2S function can be set to free GPIOs:

https://docs.espressif.com/projects/esp-idf/en/v4.2/esp32/api-reference/peripherals/i2s.html

Closed 2023-04-26.

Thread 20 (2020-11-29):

SD Card example only works with 1-bit mode, not 4-bit

MattEttus, 2020-11-29:
If I choose to use 4-bit mode by commenting out the line:
     host.flags = SDMMC_HOST_FLAG_1BIT;

Then I get the following errors:

I (0) cpu_start: Starting scheduler on APP CPU.
I (324) example: Initializing SD card
I (324) example: Using SDMMC peripheral
I (334) gpio: GPIO[13]| InputEn: 0| OutputEn: 1| OpenDrain: 0| Pullup: 0| Pulldown: 0| Intr:0
E (374) sdmmc_sd: sdmmc_check_scr: send_scr returned 0xffffffff
E (374) example: Failed to mount filesystem. If you want the card to be formatted, set format_if_mount_failed = true.

1-bit mode works fine.  Is something else necessary in order to use 4-bit mode?  The schematic shows all 4 bits being connected.  I am using a Rev. G board.

DanKoloff, 2020-11-29:
This is expected, It is how latest hardware revisions of ESP32-GATEWAY are wired, in order to leave more GPIO pins. You can solder resistors R9, R10, R11 to re-enable 4-bit mode of operation.

Refer to the revision changes notice for revision F here: https://github.com/OLIMEX/ESP32-GATEWAY/tree/master/HARDWARE

MattEttus, 2020-11-30:
Thanks, I missed that in the doc.  I'll ad din zero ohm Rs.

Closed 2020-11-30.

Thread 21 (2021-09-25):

Broken links

Tangerino, 2021-09-25:
Several broken links in the section "upper level" at
```url
https://github.com/OLIMEX/ESP32-GATEWAY/tree/master/SOFTWARE/Newest-board-revisions/ESP32_Gateway_Ethernet_v4.0
```

DanKoloff, 2021-09-30:
Thanks, it is fixed now. The README was copy-pasted from the original demo code and never properly edited.

Closed 2021-09-30.

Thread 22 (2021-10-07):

Ethernet support

Tangerino, 2021-10-07:
Just added a week ago, the documentation at:
```url
https://github.com/OLIMEX/ESP32-GATEWAY/tree/master/SOFTWARE/Newest-board-revisions/ESP32_Gateway_Ethernet_v4.0
```

Is not correct, there is no support for LAN8720 in the SDK.

Also how to make it work with the GPIO0/17 clock mode since it was removed from the sdk v4?

DanKoloff, 2021-11-01:
What? If you mean the README.md it seems it only explains ESP32-EVB, but no real mention of ESP32-GATEWAY. Will look into it.

Closed 2021-11-16.

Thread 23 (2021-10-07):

Wire1 not working in revG

Razzorback225, 2021-10-07:
Hi,

I've tried several times to get Wire1 working as the default pins for I2C are not available but could not achieve this.

I tried to setup Wire1 with these pins :

16 for SDA, 17 for SCL
36 for SDA, 35 for SCL
15 for SDA, 2 for SCL

And function used was 'Wire1.begin(SDA, SCL, 100000)'

All the tests have been done without SD card mounted or Ethernet.

Can I have a bit of help on this please?

DanKoloff, 2021-10-07:
Refer to this: https://www.olimex.com/Products/IoT/ESP32/ESP32-GATEWAY/resources/ESP32-GATEWAY-GPIOs-Rev.F-up.pdf and also refer to the schematic.

I would avoid pins 16 and 17 since they are used for the Ethernet chip. No matter if you have cable attached the pins are in use.

Notice that GPI35 and GPI36 and GPI39 are only inputs for the board (hence why are they named GPI instead of GPIO).

Use GPIO4, GPIO12, GPIO13, GPIO32, GPI35, GPI36, GPI39.

DanKoloff, 2022-02-15:
Closing due to inactivity.

Closed 2022-02-15.

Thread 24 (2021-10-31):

Ethernet Example not working in espidf 3.40300.0 (4.3.0) (Board Rev. E)

derlucas, 2021-10-31:
Im hitting a problem where i'm compiling my old project with Platformio using the recent ESP platform. The Board does not get an IP anymore with the recent IDF SDK. To narrow it down, i made two examples to compare.

Example with current framework-espidf 3.40300.0 (4.3.0) not getting an IP Address:
https://github.com/derlucas/esp32_cubes/tree/ethernettesting/gateway_firmware

And an example with an older version framework-espidf 3.40001.200521 (4.0.1) which is working correctly:
https://github.com/derlucas/esp32_cubes/tree/ethernettesting-1.12.4/gateway_firmware

The minor changes are due to the API change from tcpipadapter to netif. In SDKconfig i turned on the Clock Output on Pin 17 for the Network Chip.

I tried fiddling with different timeouts in mac_config and phy_config without success. It does not matter, if phy_config.reset_gpio_num is "-1" or on "5".

It does not make a difference if the board is powered on (cold boot) or the RST1 button is pressed.
The green LED is steady on and the yellow LED is blinking. I tried different cables and an USB->ETH Adapter on my computer, it makes no difference. (I don't think it's a hardware issue, since the board is working with an older SDK Version).

I've seen this issue https://github.com/espressif/esp-idf/issues/3998 but there is no helping information.

It would be very nice, if someone could figure out where the Problem is any maybe deliver a working Ethernet Example for espidf 4.3.0.

Lucas

derlucas, 2021-10-31:
I missed the command:

 // Set default handlers to process TCP/IP stuffs
ESP_ERROR_CHECK(esp_eth_set_default_handlers(eth_netif));

found the Problem when trying the examples with a ESP32-POE board and had a look at the latest example on the corresponding repo of that other board.

Closed 2021-10-31.

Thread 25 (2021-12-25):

has anyone ported this example to esp-idf 4.x?

gherlein, 2021-12-25:
These appear to be for 3.x.  Has someone ported?

DanKoloff, 2022-01-18:
There is one example for version 4.0:

https://github.com/OLIMEX/ESP32-GATEWAY/tree/master/SOFTWARE/Newest-board-revisions/ESP32_Gateway_Ethernet_v4.0

Closed 2023-05-23.

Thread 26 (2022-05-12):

Cant find "Use LAN8720" in "Support SPI to Ethernet Module" and then in that submenu check

joshuacv, 2022-05-12:
I am using esp-idf to flash the ESP32_Gateway_Ethernet_v4.0 to an Olimex-ESP32-gateway. I followed the instructions and at menuconfig step, I did not find the LAN8720 module in the "support SPI to ethernet module" submenu.

Any ideas?

DanKoloff, 2022-05-13:
What is the exact version of ESP-IDF that you use?

malandles, 2023-04-12:
Both v4.4.4 and v5.0.1 do not have that option anymore.

DanKoloff, 2023-04-13:
Example configuration - Internal EMAC - Ethernet PHY device - LAN87xx

Closed 2023-04-26.

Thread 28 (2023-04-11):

ESP32_Gateway_Ethernet_v4.0 Compile Error: tcpip_adapter.h: No such file or directory

khanliKU, 2023-04-11:
I recently installed ESP-IDF. I can't compile the example. I ran the following command from the ESP-IDF terminal:

```
$ idf.py build
...
C:/Users/khanli/Workspace/ESP32-GATEWAY/SOFTWARE/Newest-board-revisions/ESP32_Gateway_Ethernet_v4.0/main/ethernet_example_main.c:13:10: fatal error: tcpip_adapter.h: No such file or directory
   13 | #include "tcpip_adapter.h"
      |          ^~~~~~~~~~~~~~~~~
compilation terminated.
[832/841] Performing configure step for 'bootloader'-- Building ESP-IDF components for target esp32
-- Project sdkconfig file C:/Users/khanli/Workspace/ESP32-GATEWAY/SOFTWARE/Newest-board-revisions/ESP32_Gateway_Ethernet_v4.0/sdkconfig
-- Adding linker script C:/Users/khanli/esp/esp-idf/components/soc/esp32/ld/esp32.peripherals.ld
-- App "bootloader" version: v5.0.1
-- Adding linker script C:/Users/khanli/esp/esp-idf/components/esp_rom/esp32/ld/esp32.rom.ld
-- Adding linker script C:/Users/khanli/esp/esp-idf/components/esp_rom/esp32/ld/esp32.rom.api.ld
-- Adding linker script C:/Users/khanli/esp/esp-idf/components/esp_rom/esp32/ld/esp32.rom.libgcc.ld
-- Adding linker script C:/Users/khanli/esp/esp-idf/components/esp_rom/esp32/ld/esp32.rom.newlib-funcs.ld
-- Adding linker script C:/Users/khanli/esp/esp-idf/components/bootloader/subproject/main/ld/esp32/bootloader.ld
-- Adding linker script C:/Users/khanli/esp/esp-idf/components/bootloader/subproject/main/ld/esp32/bootloader.rom.ld
-- Components: bootloader bootloader_support efuse esp_app_format esp_common esp_hw_support esp_rom esp_system esptool_py freertos hal log main micro-ecc newlib partition_table soc spi_flash xtensa
-- Component paths: C:/Users/khanli/esp/esp-idf/components/bootloader C:/Users/khanli/esp/esp-idf/components/bootloader_support C:/Users/khanli/esp/esp-idf/components/efuse C:/Users/khanli/esp/esp-idf/components/esp_app_format C:/Users/khanli/esp/esp-idf/components/esp_common C:/Users/khanli/esp/esp-idf/components/esp_hw_support C:/Users/khanli/esp/esp-idf/components/esp_rom C:/Users/khanli/esp/esp-idf/components/esp_system C:/Users/khanli/esp/esp-idf/components/esptool_py C:/Users/khanli/esp/esp-idf/components/freertos C:/Users/khanli/esp/esp-idf/components/hal C:/Users/khanli/esp/esp-idf/components/log C:/Users/khanli/esp/esp-idf/components/bootloader/subproject/main C:/Users/khanli/esp/esp-idf/components/bootloader/subproject/components/micro-ecc C:/Users/khanli/esp/esp-idf/components/newlib C:/Users/khanli/esp/esp-idf/components/partition_table C:/Users/khanli/esp/esp-idf/components/soc C:/Users/khanli/esp/esp-idf/components/spi_flash C:/Users/khanli/esp/esp-idf/components/xtensa
-- Configuring done
-- Generating done
-- Build files have been written to: C:/Users/khanli/Workspace/ESP32-GATEWAY/SOFTWARE/Newest-board-revisions/ESP32_Gateway_Ethernet_v4.0/build/bootloader
ninja: build stopped: subcommand failed.
HINT: Please make sure that the header name is correct. Also please check if you've specified all component dependencies with 'idf_component_register(REQUIRES ...)'. If the component is not present then it should be added by the IDF Component Manager. For more information run 'idf.py docs -sp api-guides/build-system.html'.
Also, please check if the header file has been removed, renamed or relocated - refer to the migration guide for more information.
ninja failed with exit code 1, output of the command is in the c:\users\khanli\workspace\esp32-gateway\software\newest-board-revisions\esp32_gateway_ethernet_v4.0\build\log\idf_py_stderr_output_23280 and c:\users\khanli\workspace\esp32-gateway\software\newest-board-revisions\esp32_gateway_ethernet_v4.0\build\log\idf_py_stdout_output_23280
```

Closed 2023-04-12.

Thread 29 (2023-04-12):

Can no longer flash after a reset - Failed to connect to ESP32: No serial data received.

malandles, 2023-04-12:
## Specifications
- Board: ESP32-GATEWAY-EA
- ESP-IDF: v4.4.4

## Issue
Flashed the [hello-world example](https://github.com/espressif/esp-idf/tree/release/v4.4/examples/get-started/hello_world) from the ESP-IDF repository.

Had to press `BUT1` to enable download mode, then `RST1` to reset the board, then I could monitor successfully the hello world:
```
Hello world!
This is esp32 chip with 2 CPU core(s), WiFi/BT/BLE, silicon revision v3.0, 4MB external flash
Minimum free heap size: 301540 bytes
```

But then, I am unable to put back the download mode, each time I try to flash, I get this error:
```
esptool.py -p /dev/tty.usbserial-1460 -b 115200 --before default_reset --after hard_reset --chip esp32 write_flash --flash_mode dio --flash_freq 40m --flash_size detect 0x1000 bootloader/bootloader.bin 0x10000 ethernet_basic.bin 0x8000 partition_table/partition-table.bin

esptool.py v3.3.2
Serial port /dev/tty.usbserial-1460
Connecting......................................

A fatal error occurred: Failed to connect to ESP32: No serial data received.
For troubleshooting steps visit: https://docs.espressif.com/projects/esptool/en/latest/troubleshooting.html
```

Did I overwrite Olimex's bootloader? Is there a manipulation that can be done to reset to factory?

DanKoloff, 2023-04-13:
Probably a driver issue with CH340T. Make sure to reinstall the CH340 drivers.

You said that you held button BUT1 but that is unnecessary and probably did nothing, Olimex ESP32 boards enter programming mode automatically. Did you first configure the button BUT1 for manual boot operation? By default BUT1 acts only as a regular button connected to a GPIO. To be able to use it for manual boot you need to place 0 Ohm resistor on R46 pads, refer to the right side of the schematic where buttons are.

DanKoloff, 2023-04-14:
The button didn't do anything for sure, it is likely the restart that influenced the successful entry into bootloader mode. Also I am not sure but it might have something to do with these flags in your command line "--before default_reset --after hard_reset ", double check if your command parameters are required. Probably some timeout occurs and if you can replicate the restart timing you will probably be capable of programming the board again.

If nothing else works you should try connecting the boot button (placing 0 ohm resistor on the missing R46, it is 0603 size) but first:

- Double check your command line parameters;
- Try reinstalling the CH340 drivers;
- Try another USB port and cable, if using USB hub, consider testing without it;
- Try another version of esptool or maybe try with another tool to program the board like ESP32 for Arduino.

Some combinations of versions of esptool and CH340 drivers are known to cause timeouts. I'd also recommend searching online for similar timeouts between CH340 and esptool, check these:

https://github.com/espressif/esptool/issues/443
https://github.com/espressif/esptool/issues/592
https://www.olimex.com/forum/index.php?topic=8214.0

malandles, 2023-05-01:
- ❌  Double check your command line parameters;
  - Removed `--before` and `--after`, did not work
  - Replaced `--before default_reset` by `--before no_reset`, did not work
- ❌  Try reinstalling the CH340 drivers, did not work
- ❌  Try another USB port and cable, if using USB hub, consider testing without it;
   - Used multiple different cables, all had the same behaviour
   - Used multiple different ports (USB-C -> MicroUSB or USB-A -> MicroUSB), all had the same behaviour
   - Not using a USB hub
- ❌ Exact same error with ESP32 for Arduino: `A fatal error occurred: Failed to connect to ESP32: No serial data received.`

I will try to manually connecting to the boot.

Closed 2023-05-01.

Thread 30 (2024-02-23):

eth2ap and up/down cycle

rognskog, 2024-02-23:
Hello,
I am trying to use the eth2ap example (4.4.6) to bridge wifi/eth.
However, the ethernet interface seems to go up/down all the time. Any hints?

(8959) eth_example: Ethernet Link Down
I (8969) wifi:flush txq
I (8969) wifi:stop sw txq
I (8969) wifi:lmac stop hw txq
I (10959) eth_example: Ethernet Link Up
I (10969) wifi:mode : softAP (e0:5a:1b:66:5e:db)
I (10969) wifi:Total power save buffer number: 16
I (14959) eth_example: Ethernet Link Down
I (14969) wifi:flush txq
I (14969) wifi:stop sw txq
I (14969) wifi:lmac stop hw txq
I (16959) eth_example: Ethernet Link Up
I (16969) wifi:mode : softAP (e0:5a:1b:66:5e:db)
I (16969) wifi:Total power save buffer number: 16
I (18959) eth_example: Ethernet Link Down
I (18969) wifi:flush txq
I (18969) wifi:stop sw txq
I (18969) wifi:lmac stop hw txq

DanKoloff, 2024-10-11:
This is not something known. Maybe try newer version of the example. Maybe try to lower the drive strength of the digital output 17 from the default value 20mA to 5mA. There are usually 4 levels of strength from 0 to 3.

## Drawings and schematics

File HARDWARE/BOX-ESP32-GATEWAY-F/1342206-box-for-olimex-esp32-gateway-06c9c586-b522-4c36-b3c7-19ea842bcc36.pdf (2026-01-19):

## Box for Olimex ESP32-GATEWAY

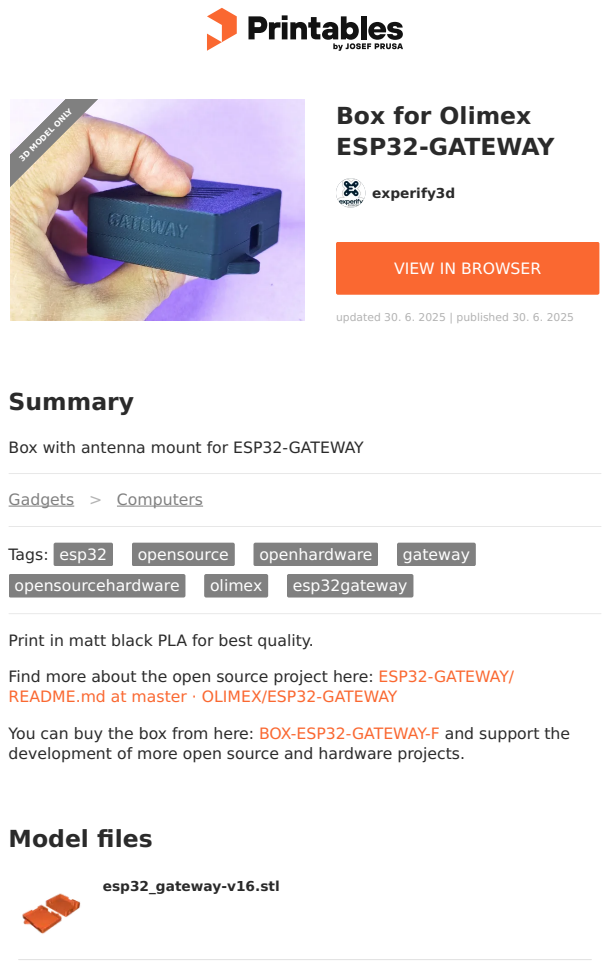
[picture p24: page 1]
Model files; Summary; Gadgets > Computers; Tags: esp32; opensource; openhardware; gateway; opensourcehardware; olimex; esp32gateway; experify3d; updated 30. 6. 2025 | published 30. 6. 2025; esp32_gateway-v16.stl; 3D MODEL ONLY

VIEW IN BROWSER (https://printables.com/model/1342206-box-for-olimex-esp32-gateway)

Box with antenna mount for ESP32-GATEWAY

Print in matt black PLA for best quality.

Find more about the open source project here: ESP32-GATEWAY/
README.md at master · OLIMEX/ESP32-GATEWAY (https://github.com/OLIMEX/ESP32-GATEWAY/blob/master/README.md)

You can buy the box from here: BOX-ESP32-GATEWAY-F (https://www.olimex.com/Products/IoT/ESP32/BOX-ESP32-GATEWAY-F/) and support the
development of more open source and hardware projects.

## License

This work is licensed under a
Creative Commons (4.0 International License)

Attribution (http://creativecommons.org/licenses/by/4.0/)

✖ | Sharing without ATTRIBUTION
✔ | Remix Culture allowed
✔ | Commercial Use
✔ | Free Cultural Works
✔ | Meets Open Definition

esp32_gateway-v16-bambu-lab-project.3mf

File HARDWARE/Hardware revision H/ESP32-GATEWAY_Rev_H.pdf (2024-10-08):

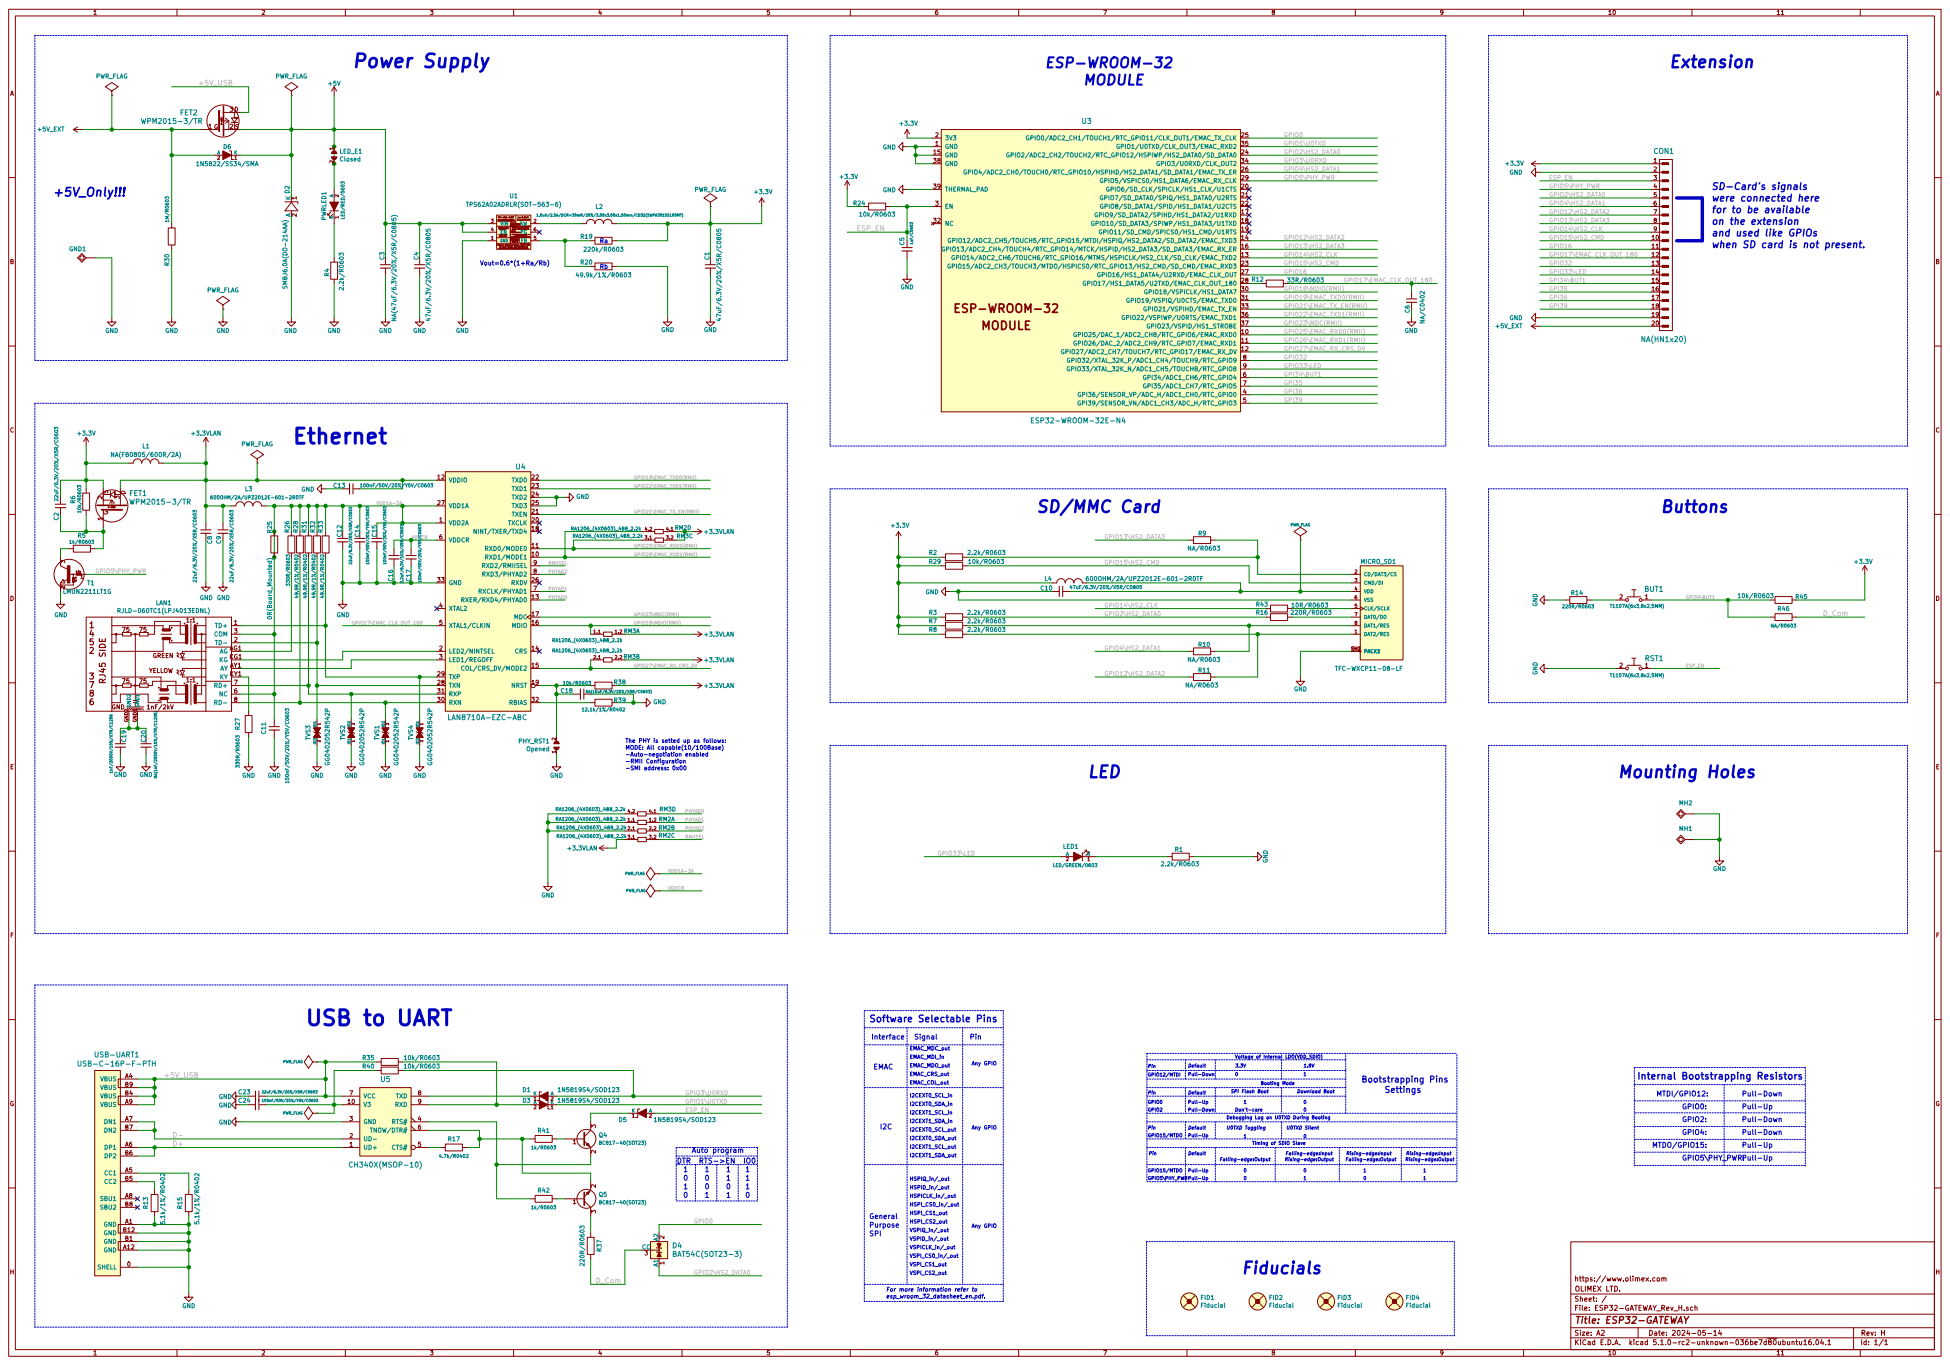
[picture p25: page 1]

when SD card is not present. GPIO14\HS2_CLK GPIO2\HS2_DATA0 GPIO15\HS2_CMD GPIO4\HS2_DATA1 GPIO12\HS2_DATA2 GPIO13\HS2_DATA3

were connected here
for to be available
on the extension
and used like GPIOs

In case a lower output ripple is desired, higher output capacitance can help reduce the ripple. Lx=1.0uH

(SOT563-6) A 0.47uH inductor can also be used a larger value reduces input voltage ripple. capacitors for the TPS62A02x. Cin=4.7uF/6.3V/X5R

Do not float. Enable control. FB Input Current, I(FB)=100nA(max) Feedback Reference Voltage, V(REF)=0.6V
Rb must not be higher than 100k to provide acceptable noise sensitivity. Shutdown Current I(SHDN)=0.01-2uA Switching TPS62A02ADRL V(ENH)=1.2V

Cout=(10 to 22)uF/6.3V/X5R (Vout>=1.8V). 22uF Recommended! Cout=22uF/6.3V/X5R (1.2V=<Vout<1.8V). Cout=44uF/6.3V/X5R (0.6V=<Vout<1.2V). DCR<50mR

VDDCR The PHY is setted up as follows: MODE: All capable(10/100Base)

EMAC_COL_out Interface EMAC EMAC_MDC_out EMAC_MDI_in EMAC_MDO_out EMAC_CRS_out | Any GPIO

Signal | Pin

Bootstrapping Pins Settings

I2CEXT0_SCL_in I2CEXT0_SDA_in I2CEXT1_SCL_in I2CEXT1_SDA_in I2CEXT0_SCL_out I2CEXT0_SDA_out I2CEXT1_SCL_out

DTR RTS->EN | IO0

File: ESP32-GATEWAY_Rev_H.sch Sheet: / OLIMEX LTD. https://www.olimex.com

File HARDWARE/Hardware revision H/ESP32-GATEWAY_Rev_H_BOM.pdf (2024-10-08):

ESP32-GATEWAY_Rev_H-BOM | 05/15/2024

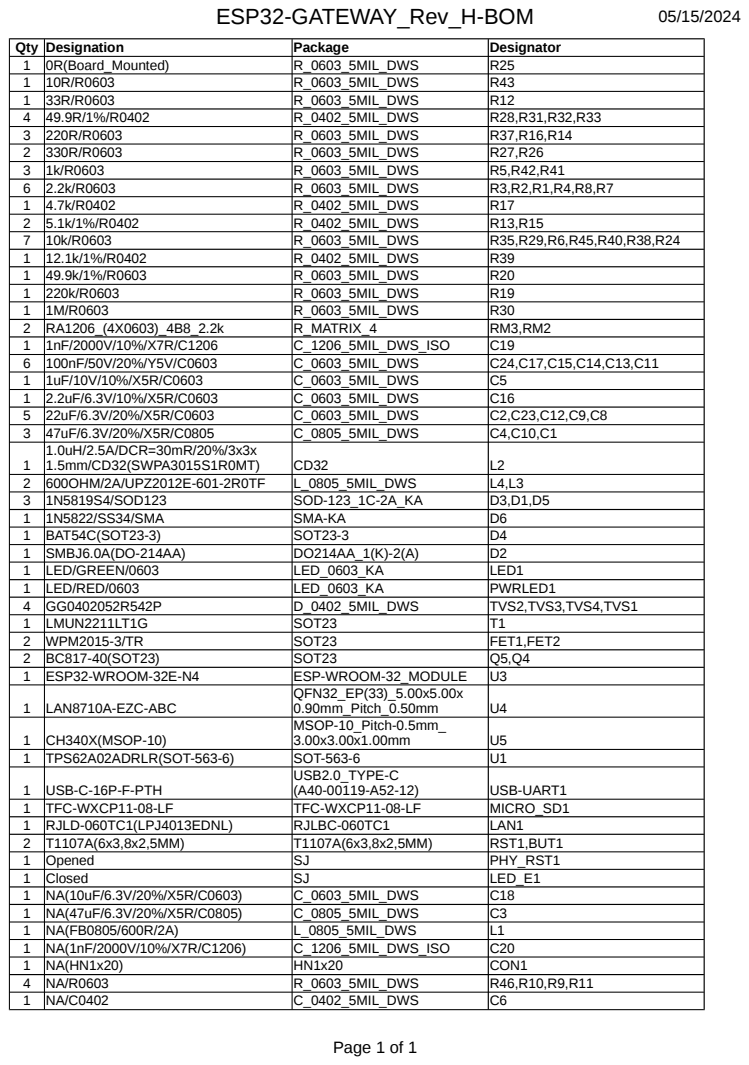
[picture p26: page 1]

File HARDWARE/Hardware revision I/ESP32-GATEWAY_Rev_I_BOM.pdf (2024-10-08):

ESP32-GATEWAY_Rev_I-BOM | 06/10/2024

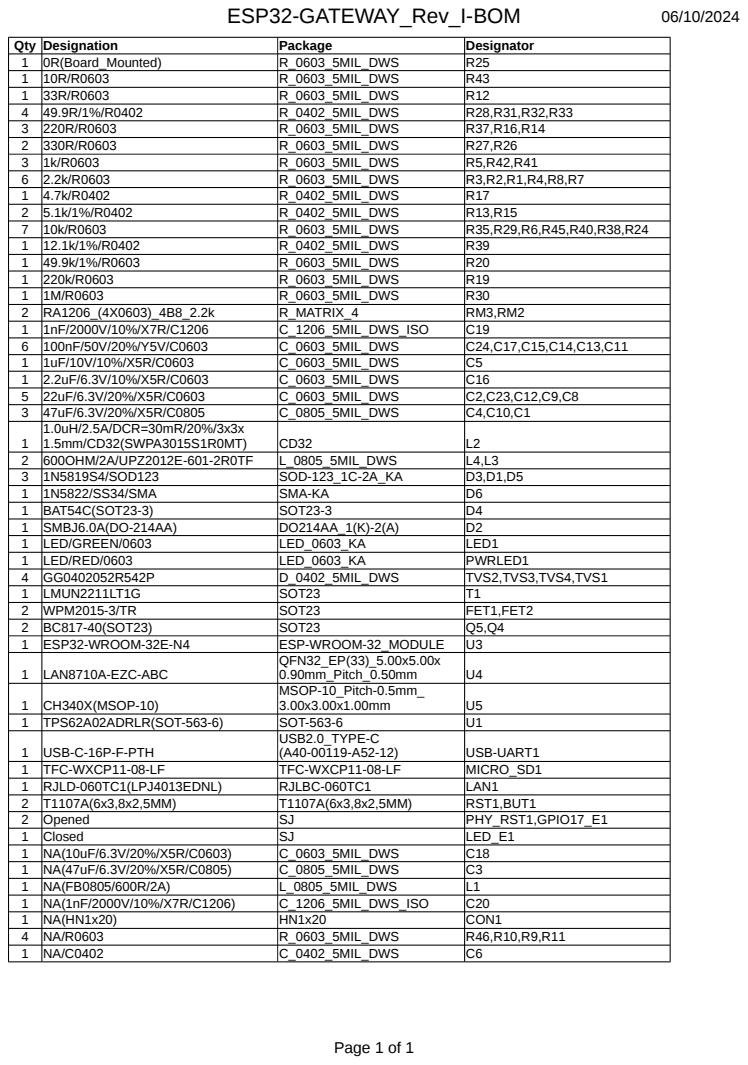
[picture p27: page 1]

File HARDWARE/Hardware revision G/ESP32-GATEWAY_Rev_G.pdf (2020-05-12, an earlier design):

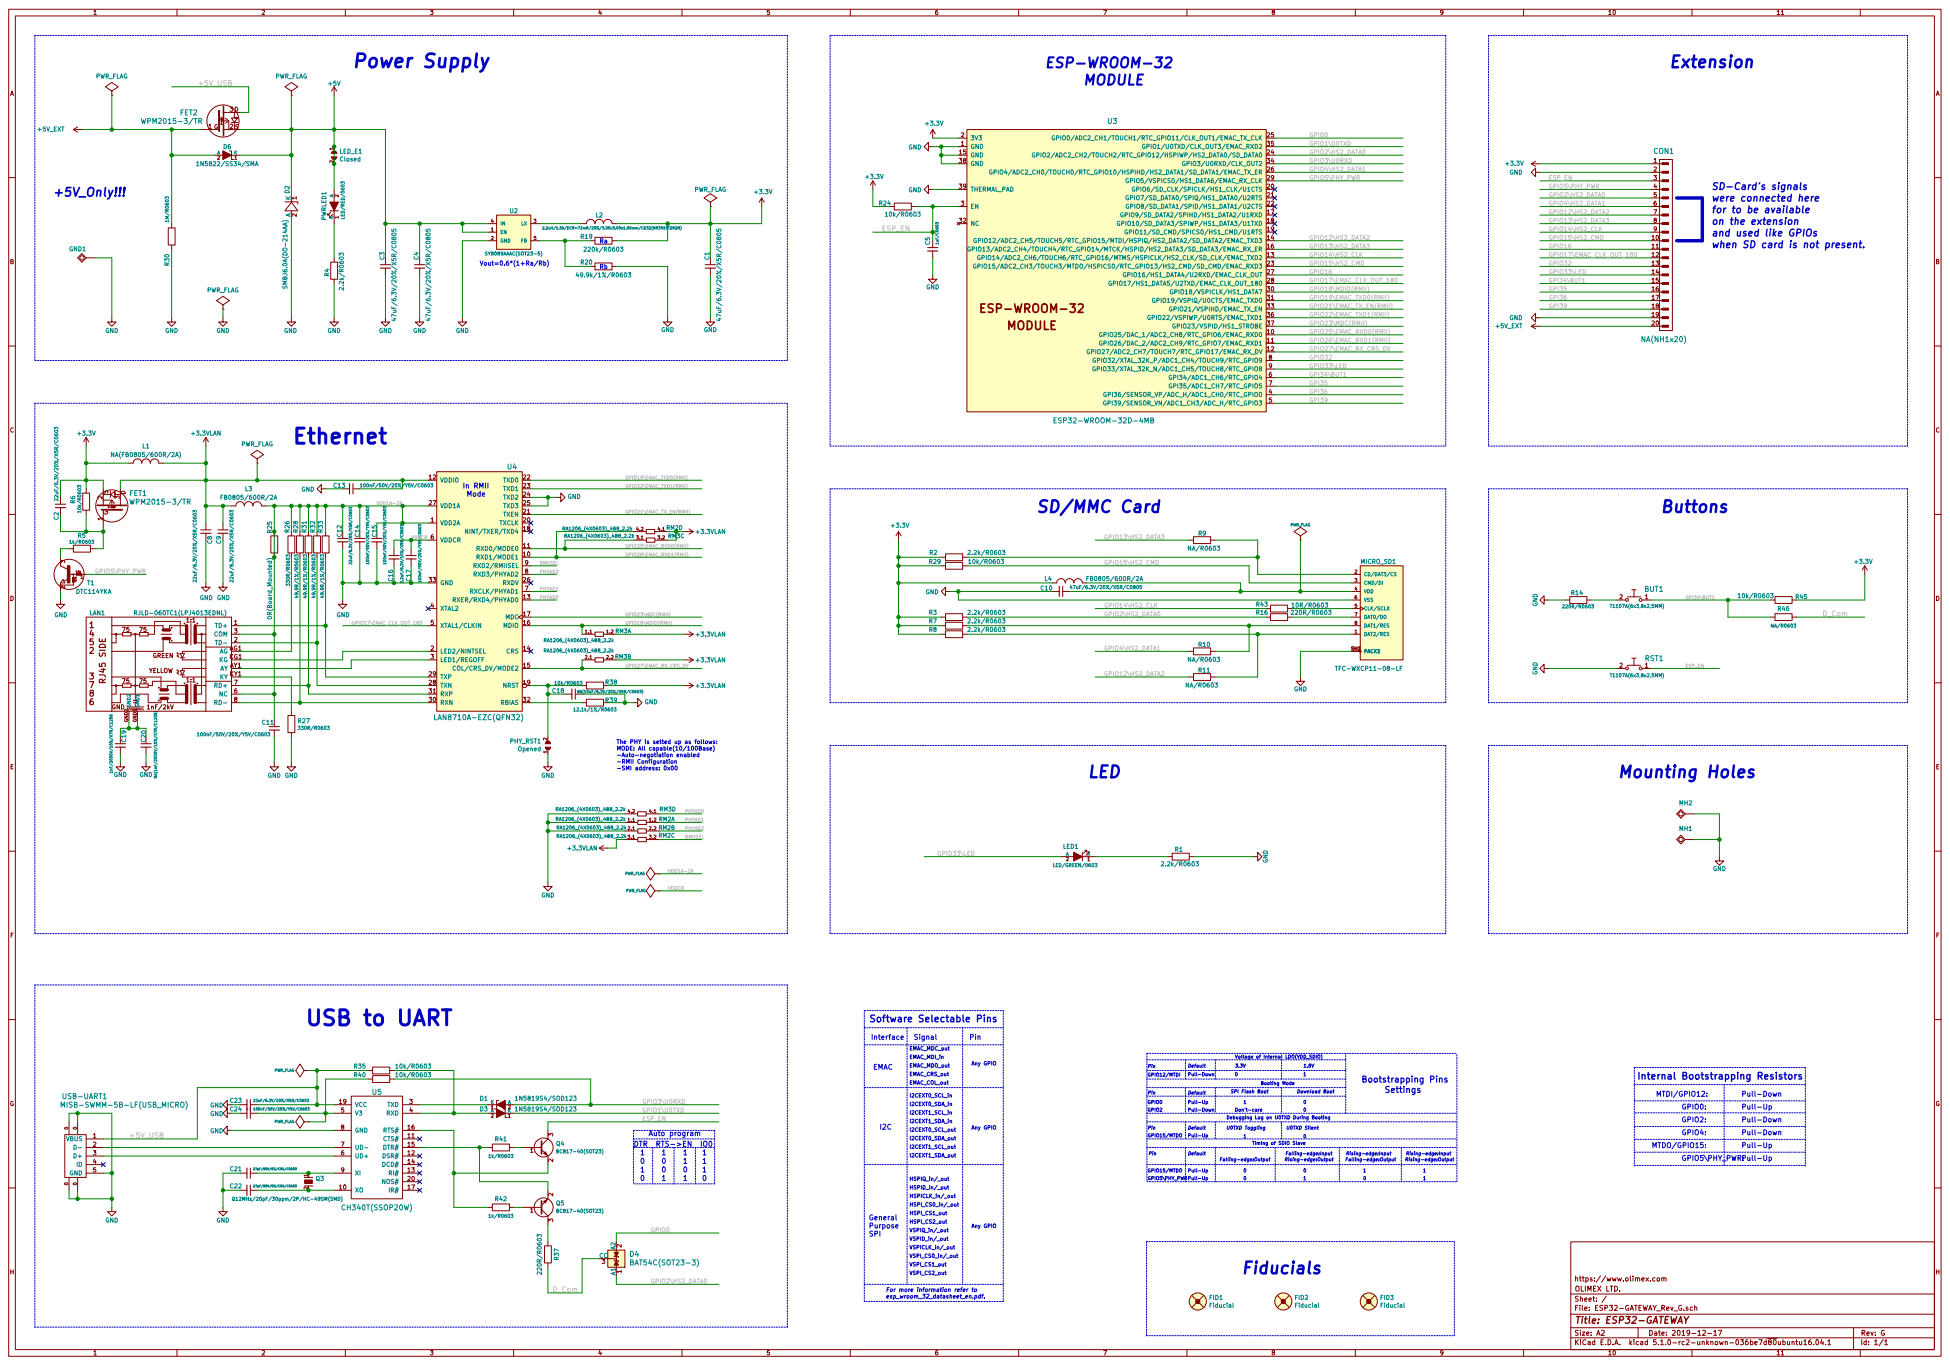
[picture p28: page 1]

2 PWRLED1 LED/RED/0603 GND GND GND

were connected here
for to be available
on the extension
and used like GPIOs

when SD card is not present. C2 22uF/6.3V/20%/X5R/C0603

VDDCR The PHY is setted up as follows: MODE: All capable(10/100Base)

MISB-SWMM-5B-LF(USB_MICRO) GND

File: ESP32-GATEWAY_Rev_G.sch Sheet: / OLIMEX LTD. https://www.olimex.com

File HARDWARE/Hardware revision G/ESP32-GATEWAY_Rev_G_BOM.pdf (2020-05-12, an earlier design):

ESP32-GATEWAY_Rev_G_BOM | 12/20/2019

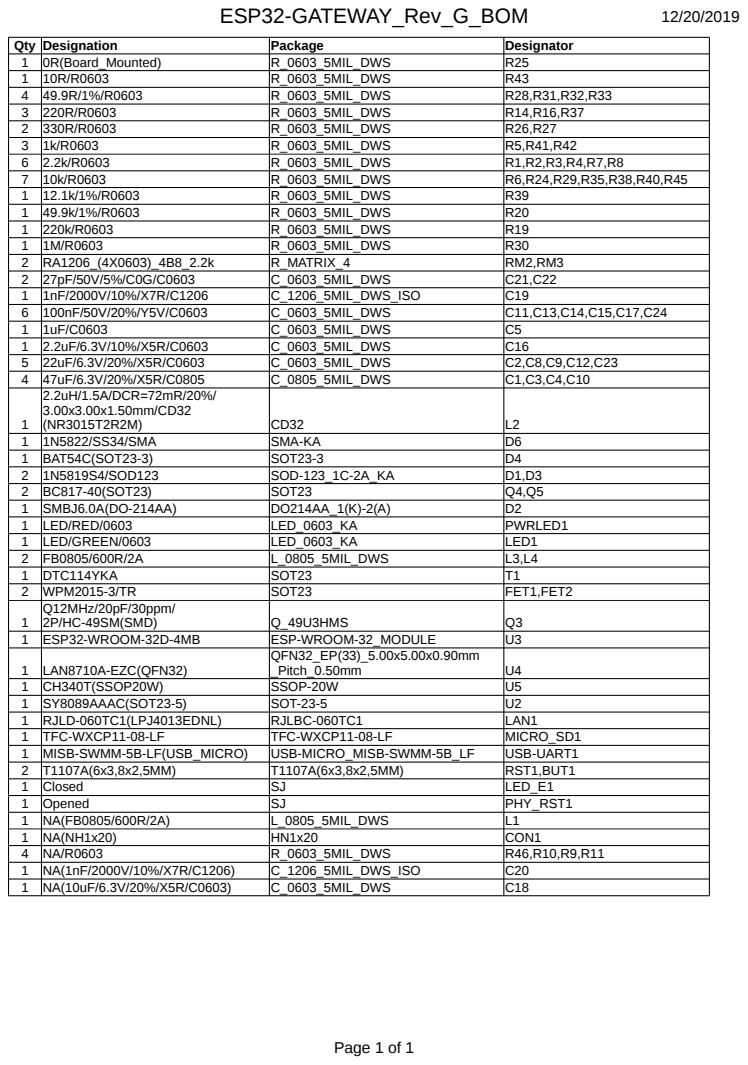
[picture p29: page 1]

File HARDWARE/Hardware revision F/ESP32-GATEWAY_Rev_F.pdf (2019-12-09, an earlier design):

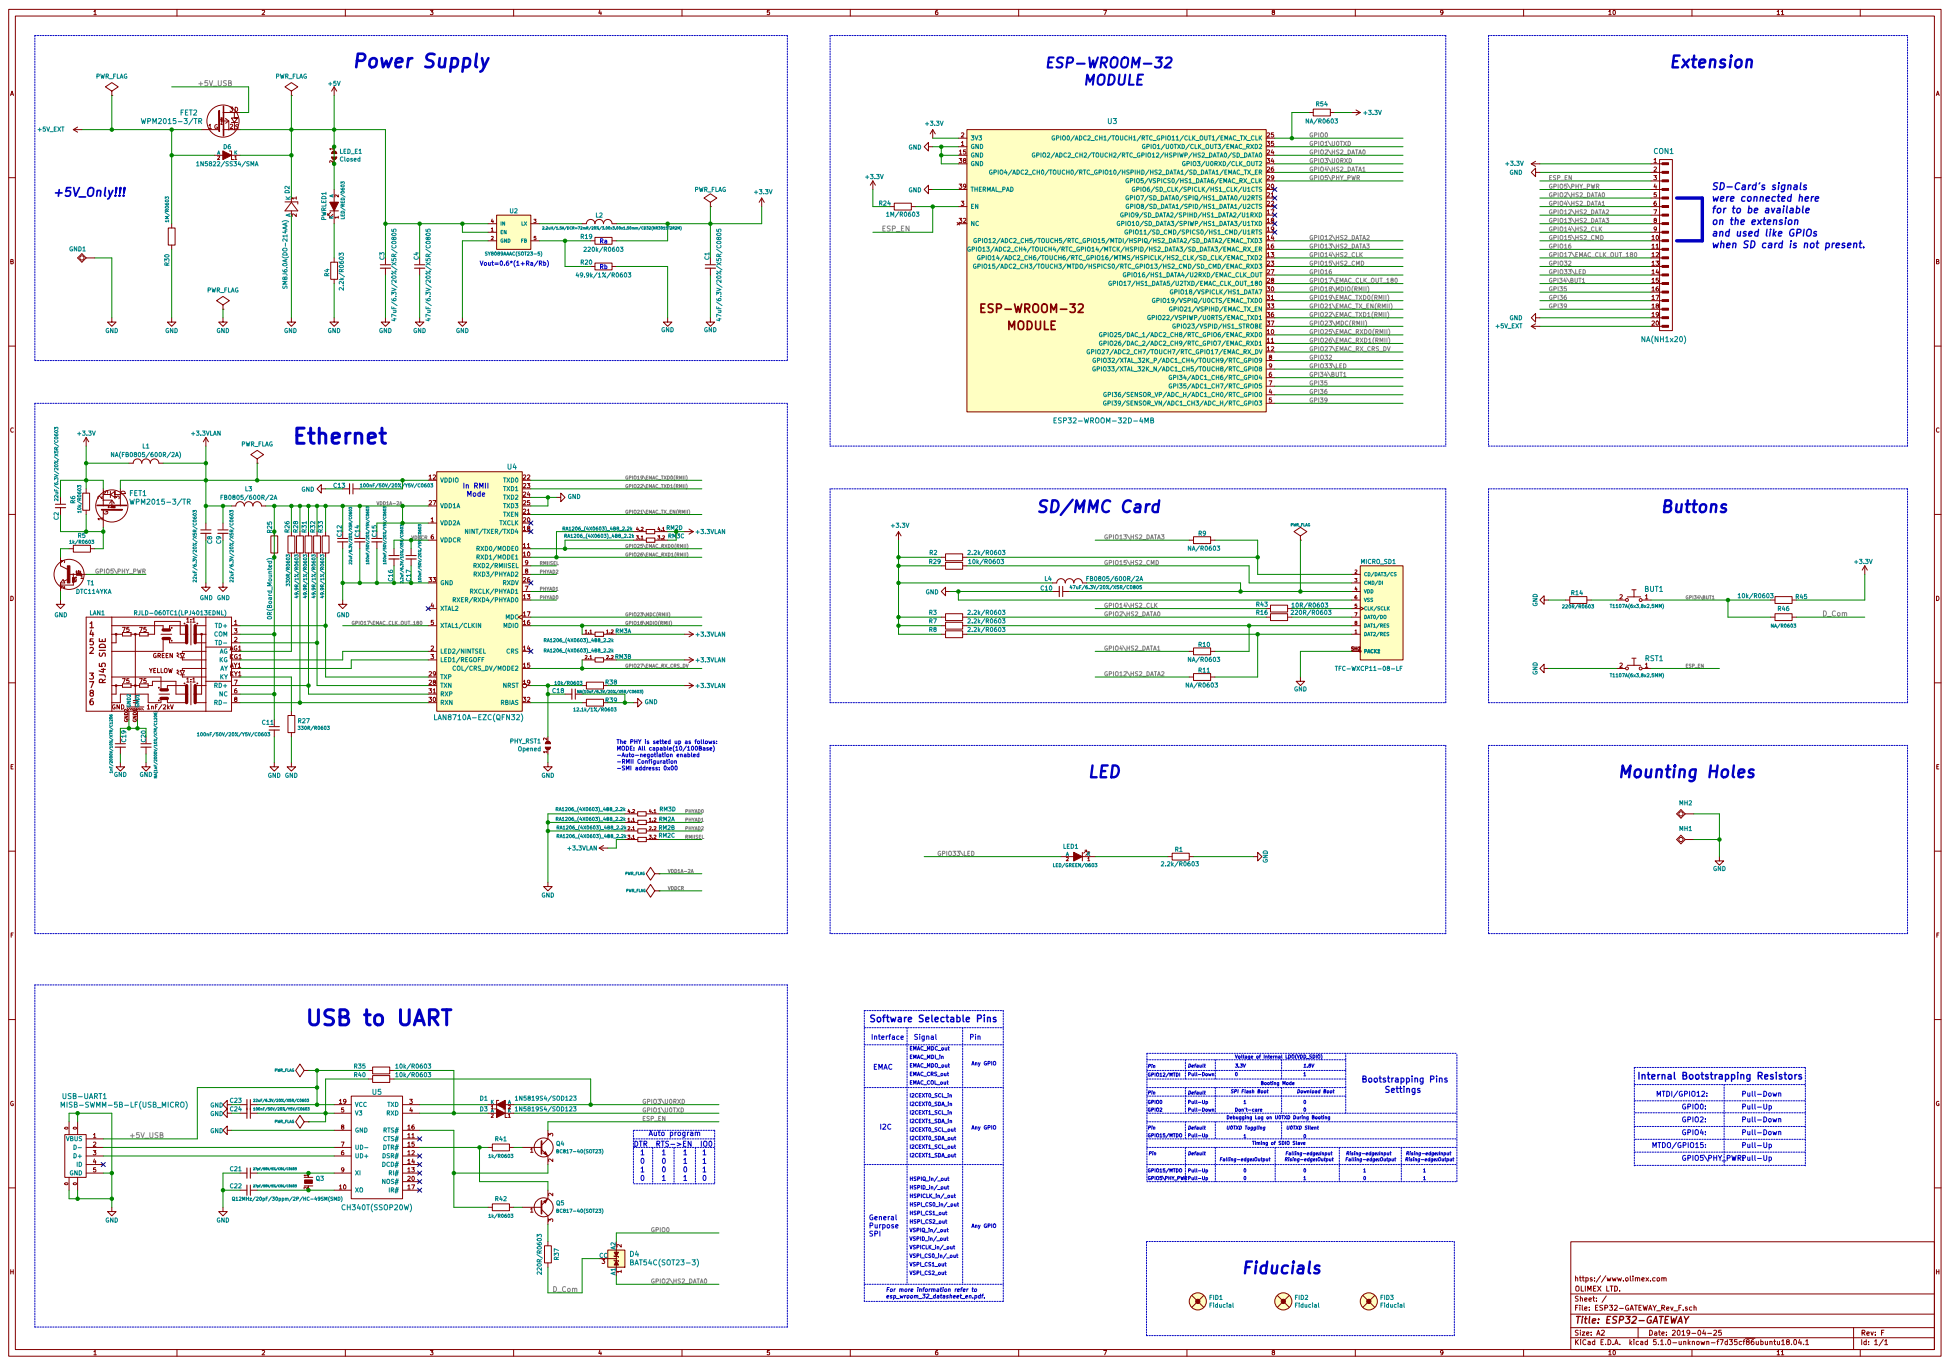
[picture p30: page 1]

MODULE SD/MMC Card

2 PWRLED1 LED/RED/0603 GND GND GND

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

GPIO13\HS2_DATA3 GPIO19\EMAC_TXD0(RMII) GPIO22\EMAC_TXD1(RMII) GPIO21\EMAC_TX_EN(RMII) GND

VDDCR The PHY is setted up as follows: MODE: All capable(10/100Base)
-Auto-negotiation enabled
-RMII Configuration

File: ESP32-GATEWAY_Rev_F.sch Sheet: / OLIMEX LTD. https://www.olimex.com

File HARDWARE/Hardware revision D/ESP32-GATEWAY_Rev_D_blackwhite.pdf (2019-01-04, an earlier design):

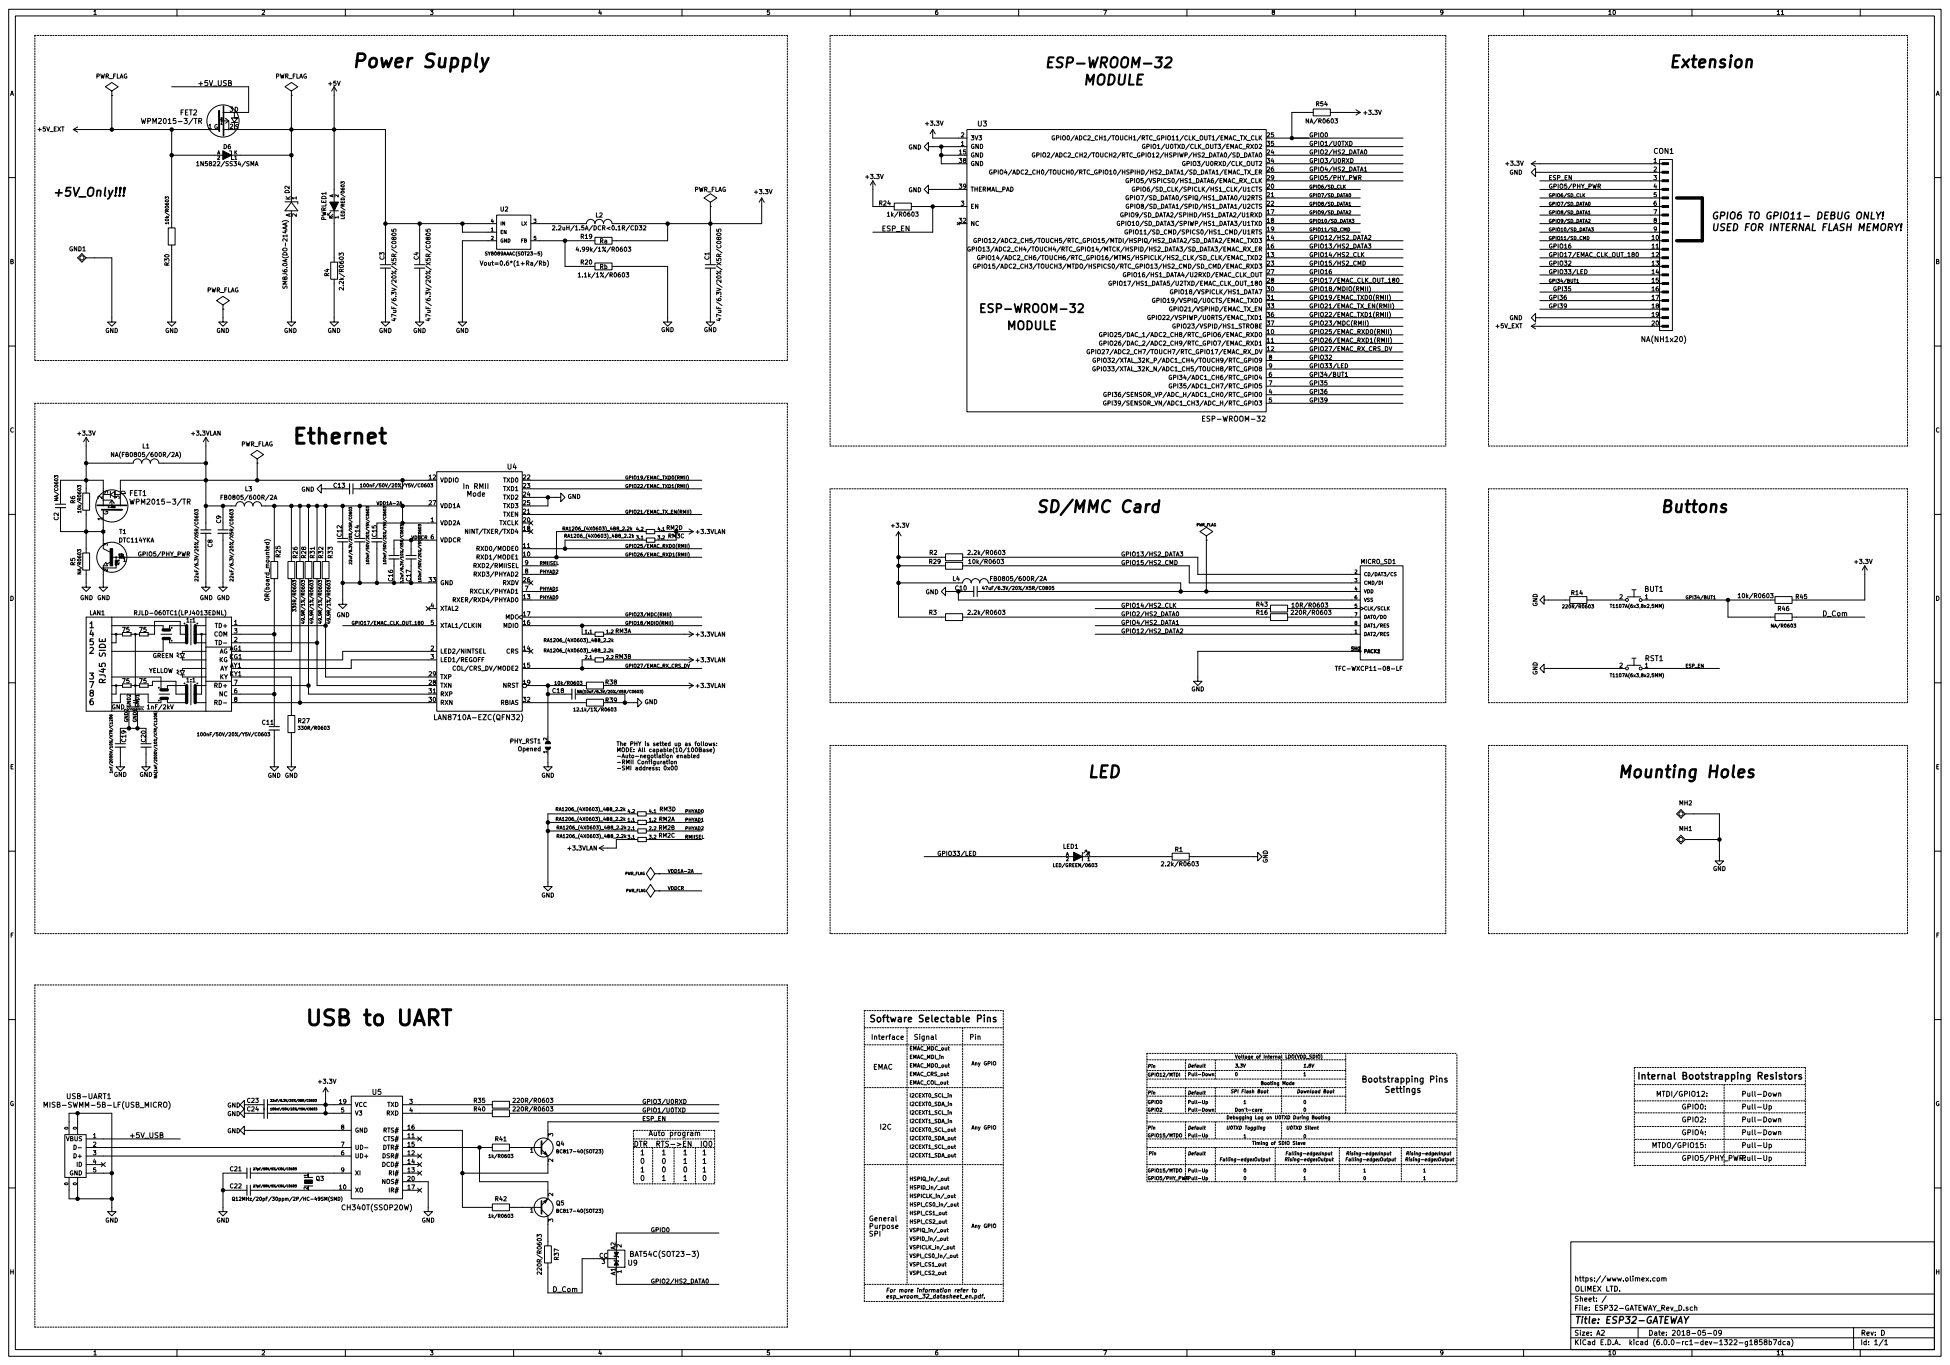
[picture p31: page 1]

2 PWRLED1 LED/RED/0603 GND GND GND

GPIO6 TO GPIO11- DEBUG ONLY!
USED FOR INTERNAL FLASH MEMORY!

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

MISB-SWMM-5B-LF(USB_MICRO) GND

File: ESP32-GATEWAY_Rev_D.sch Sheet: / OLIMEX LTD. https://www.olimex.com

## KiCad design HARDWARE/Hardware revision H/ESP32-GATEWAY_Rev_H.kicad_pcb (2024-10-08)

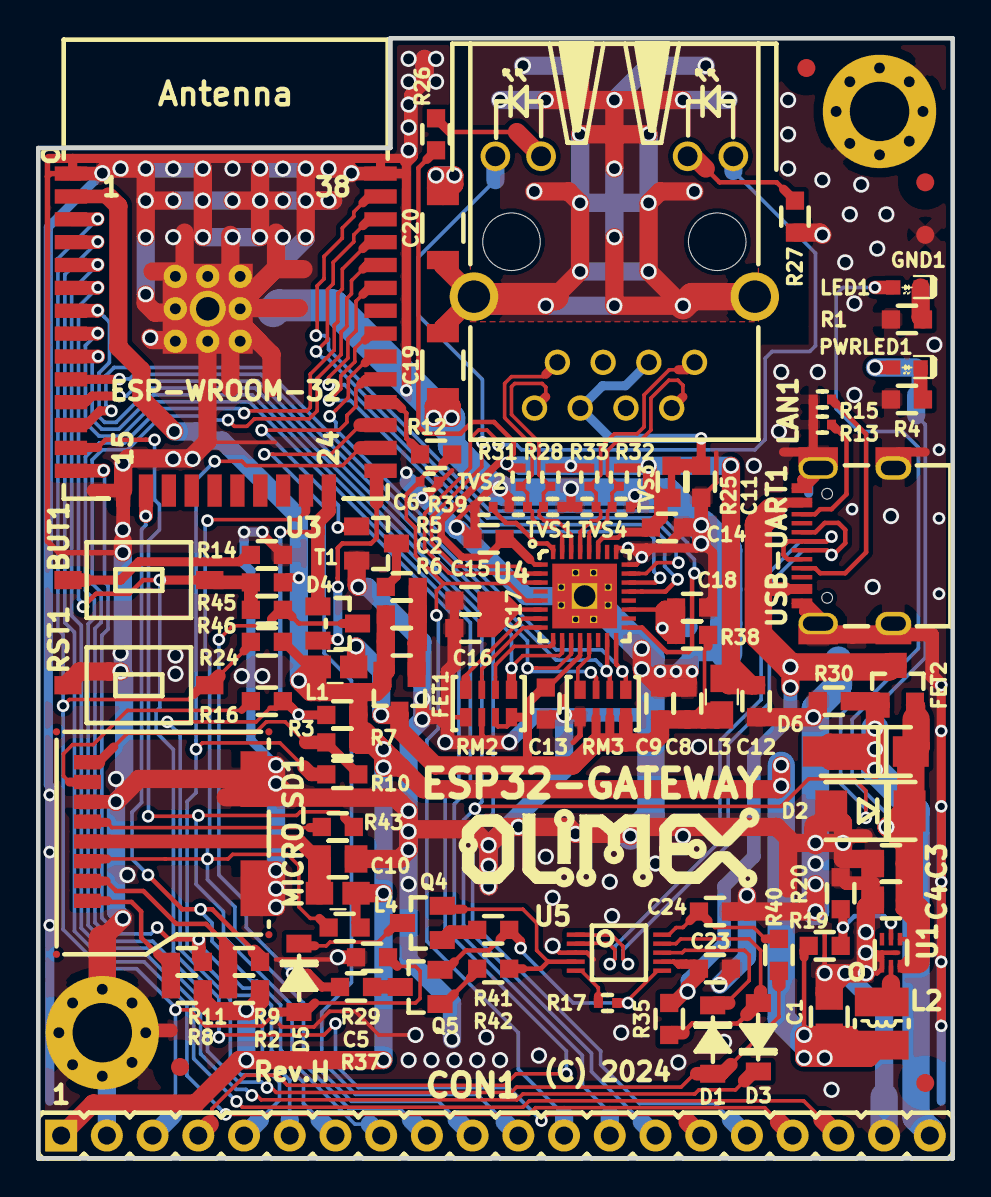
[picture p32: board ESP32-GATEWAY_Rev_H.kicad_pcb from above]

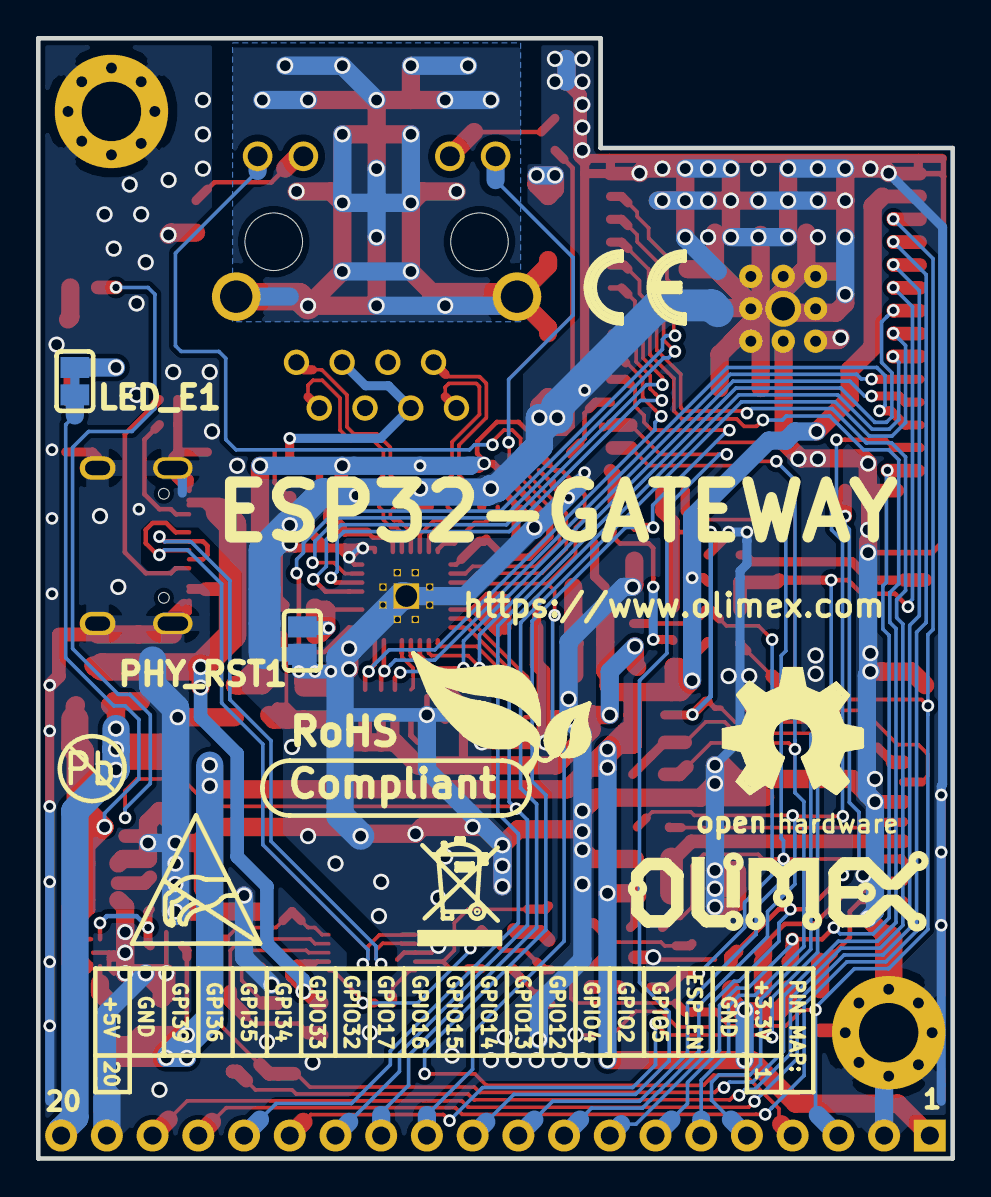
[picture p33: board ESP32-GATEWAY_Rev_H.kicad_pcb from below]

Board: 2 copper layers, 50.8 x 62.2 mm, 110 parts (9 on the bottom side), 79 nets.

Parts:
BUT1: T1107A(6x3,8x2,5MM)
C1, C4, C10: 47uF/6.3V/20%/X5R/C0805; C_0805_5MIL_DWS
C2, C8, C9, C12, C23: 22uF/6.3V/20%/X5R/C0603; C_0603_5MIL_DWS
C3: NA(47uF/6.3V/20%/X5R/C0805); C_0805_5MIL_DWS
C5: 1uF/C0603; C_0603_5MIL_DWS
C6: NA/C0402; C_0402_5MIL_DWS
C11, C13, C14, C15, C17, C24: 100nF/50V/20%/Y5V/C0603; C_0603_5MIL_DWS
C16: 2.2uF/6.3V/10%/X5R/C0603; C_0603_5MIL_DWS
C18: NA(10uF/6.3V/20%/X5R/C0603); C_0603_5MIL_DWS
C19: 1nF/2000V/10%/X7R/C1206; C_1206_5MIL_DWS_ISO
C20: NA(1nF/2000V/10%/X7R/C1206); C_1206_5MIL_DWS_ISO
CON1: NA(HN1x20); HN1x20
D1, D3, D5: 1N5819S4/SOD123; SOD-123_1C-2A_KA
D2: SMBJ6.0A(DO-214AA); DO214AA_1(K)-2(A)
D4: BAT54C(SOT23-3); SOT23-3
D6: 1N5822/SS34/SMA; SMA-KA
FET1, FET2: WPM2015-3/TR; SOT23
FID1, FID3: Fiducial; Fiducial1x3
FID2, FID4: Fiducial; Fiducial1x3_Past
GND1: TESTPAD; TESTPAD_40-ROUND
L1: NA(FB0805/600R/2A); L_0805_5MIL_DWS
L2: 1.0uH/2.5A/DCR=30mR/20%/3.00x3.00x1.50mm/CD32(SWP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; CD32
L3, L4: 600OHM/2A/UPZ2012E-601-2R0TF; L_0805_5MIL_DWS
LAN1: RJLD-060TC1(LPJ4013EDNL); RJLBC-060TC1
LED1: LED/GREEN/0603; LED_0603_KA
LED_E1: Closed; SJ
Logo-OLimeX: OLIMEX_LOGO_TB
Logo-OSHW: LOGO_OPENHARDWARE_8x8
Logo-OlimexBIG: OLIMEX_LOGO_TB
MH1, MH2: Mounting_hole_Shield_3.3mm
MICRO_SD1: TFC-WXCP11-08-LF
PHY_RST1: Opened; SJ
PWRLED1: LED/RED/0603; LED_0603_KA
Q4, Q5: BC817-40(SOT23); SOT23
R1, R2, R3, R4, R7, R8: 2.2k/R0603; R_0603_5MIL_DWS
R5, R41, R42: 1k/R0603; R_0603_5MIL_DWS
R6, R24, R29, R35, R38, R40, R45: 10k/R0603; R_0603_5MIL_DWS
R9, R10, R11, R46: NA/R0603; R_0603_5MIL_DWS
R12: 33R/R0603; R_0603_5MIL_DWS
R13, R15: 5.1k/1%/R0402; R_0402_5MIL_DWS
R14, R16, R37: 220R/R0603; R_0603_5MIL_DWS
R17: 4.7k/R0402; R_0402_5MIL_DWS
R19: 220k/R0603; R_0603_5MIL_DWS
R20: 49.9k/1%/R0603; R_0603_5MIL_DWS
R25: 0R(Board_Mounted); R_0603_5MIL_DWS
R26, R27: 330R/R0603; R_0603_5MIL_DWS
R28, R31, R32, R33: 49.9R/1%/R0402; R_0402_5MIL_DWS
R30: 1M/R0603; R_0603_5MIL_DWS
R39: 12.1k/1%/R0402; R_0402_5MIL_DWS
R43: 10R/R0603; R_0603_5MIL_DWS
RM2, RM3: RA1206_(4X0603)_4B8_2.2k; R_MATRIX_4
RST1: T1107A(6x3,8x2,5MM)
Sign-Antistatic: Val**; LOGO_ANTISTATIC_1
Sign-RecyclBin: LOGO_RECYCLEBIN_1
Sign_CE: CE_Sign
Sign_Pb-Free: LOGO_PBFREE
Sign_RoHS: Val**; LOGO_ROHS_1
T1: LMUN2211LT1G; SOT23
TVS1, TVS2, TVS3, TVS4: GG0402052R542P; D_0402_5MIL_DWS
U1: TPS62A02ADRLR(SOT-563-6); SOT-563-6
U3: ESP32-WROOM-32E-N4; ESP-WROOM-32_MODULE
U4: LAN8710A-EZC-ABC; QFN32_EP(33)_5.00x5.00x0.90mm_Pitch_0.50mm
U5: CH340X(MSOP-10); MSOP-10_Pitch-0.5mm_3.00x3.00x1.00mm
USB-UART1: USB-C-16P-F-PTH; USB2.0_TYPE-C(A40-00119-A52-12)

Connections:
+3.3VLAN: C8.1, C9.1, C13.1, FET1.3, L1.2, L3.1, R38.2, RM2.3.1, RM2.4.1, RM3.1.2, RM3.2.2, RM3.3.2, U4.12
+3V3: C1.1, C2.1, CON1.1, FET1.2, L1.1, L2.2, L4.1, R2.1, R3.1, R6.1, R7.1, R8.1, R19.2, R24.1, R29.1, R45.1, U3.2
+5V: C3.1, C4.1, D2.1, D6.1, FET2.2, LED_E1.1, LED_E1.2, PWRLED1.2, U1.3, U1.4
+5V_EXT: CON1.20, D6.2, FET2.1, R30.1
/+5V_USB: C23.1, FET2.3, R35.1, U5.7, USB-UART1.A4, USB-UART1.A9, USB-UART1.B4, USB-UART1.B9
/D+: U5.1, USB-UART1.A6, USB-UART1.B6
/D-: U5.2, USB-UART1.A7, USB-UART1.B7
/D_Com: D4.3, R37.2, R46.2
/ESP_EN: C5.1, CON1.3, D5.2, R24.2, RST1.1, U3.3
/GPI34\BUT1: BUT1.1, CON1.15, R45.2, R46.1, U3.6
/GPI35: CON1.16, U3.7
/GPI36: CON1.17, U3.4
/GPI39: CON1.18, U3.5
/GPIO0: D4.2, U3.25
/GPIO1\U0TXD: D3.1, U3.35
/GPIO2\HS2_DATA0: CON1.5, D4.1, R3.2, R16.1, U3.24
/GPIO3\U0RXD: D1.2, R40.2, U3.34
/GPIO4\HS2_DATA1: CON1.6, R10.1, U3.26
/GPIO5\PHY_PWR: CON1.4, T1.1, U3.29
/GPIO12\HS2_DATA2: CON1.7, R11.1, U3.14
/GPIO13\HS2_DATA3: CON1.8, R9.1, U3.16
/GPIO14\HS2_CLK: CON1.9, R43.1, U3.13
/GPIO15\HS2_CMD: CON1.10, MICRO_SD1.3, R29.2, U3.23
/GPIO16: CON1.11, U3.27
/GPIO17\EMAC_CLK_OUT_180: C6.1, CON1.12, R12.2, U4.5
/GPIO18\MDIO(RMII): RM3.1.1, U3.30, U4.16
/GPIO19\EMAC_TXD0(RMII): U3.31, U4.22
/GPIO21\EMAC_TX_EN(RMII): U3.33, U4.21
/GPIO22\EMAC_TXD1(RMII): U3.36, U4.23
/GPIO23\MDC(RMII): U3.37, U4.17
/GPIO25\EMAC_RXD0(RMII): RM3.3.1, U3.10, U4.11
/GPIO26\EMAC_RXD1(RMII): RM2.4.2, U3.11, U4.10
/GPIO27\EMAC_RX_CRS_DV: RM3.2.1, U3.12, U4.15
/GPIO32: CON1.13, U3.8
/GPIO33\LED: CON1.14, LED1.2, U3.9
/PHYAD0: RM3.4.1, U4.13
/PHYAD1: RM2.1.2, U4.7
/PHYAD2: RM2.2.2, U4.8
/RMIISEL: RM2.3.2, U4.9
/VDD1A-2A: C11.1, C12.1, C14.1, C15.1, L3.2, LAN1.3, LAN1.6, R25.1, R25.2, R26.1, R28.1, R31.1, R32.1, R33.1, U4.1, U4.27
/VDDCR: C16.1, C17.1, U4.6
GND: C1.2, C3.2, C4.2, C5.2, C6.2, C8.2, C9.2, C10.2, C11.2, C12.2, C13.2, C14.2, C15.2, C16.2, C17.2, C18.1, C19.2, C20.2, C23.2, C24.2, CON1.2, CON1.19, D2.2, GND1.1, MH1.GND1, MH2.GND1, MICRO_SD1.6, MICRO_SD1.SH1, MICRO_SD1.SH2, PHY_RST1.1, R1.1, R4.2, R13.2, R14.2, R15.2, R20.2, R27.2, R30.2, R39.2, RM2.1.1, RM2.2.1, RM3.4.2, RST1.2, T1.2, TVS1.1, TVS2.1, TVS3.2, TVS4.2, U1.1, U3.1, U3.15, U3.38, U3.39, U4.24, U4.25, U4.33, U5.3, USB-UART1.0, USB-UART1.A1, USB-UART1.A12, USB-UART1.B1, USB-UART1.B12
unnamed: BUT1.2, R14.1
unnamed: C2.2, FET1.1, R5.1, R6.2
unnamed: C10.1, L4.2, MICRO_SD1.4
unnamed: C18.2, PHY_RST1.2, R38.1, U4.19
unnamed: C19.1, C20.1, LAN1.GND1, LAN1.GND2
unnamed: C24.1, R40.1, U5.10
unnamed: D1.1, U5.8
unnamed: D3.2, R35.2, U5.9
unnamed: D5.1, Q4.3
unnamed: L2.1, U1.2
unnamed: LAN1.1, R33.2, TVS4.1, U4.29
unnamed: LAN1.2, R32.2, TVS3.1, U4.28
unnamed: LAN1.7, R31.2, TVS2.2, U4.31
unnamed: LAN1.8, R28.2, TVS1.2, U4.30
unnamed: LAN1.AG1, R26.2
unnamed: LAN1.AY1, U4.3
unnamed: LAN1.KG1, U4.2
unnamed: LAN1.KY1, R27.1
unnamed: LED1.1, R1.2
unnamed: MICRO_SD1.1, R8.2, R11.2
unnamed: MICRO_SD1.2, R2.2, R9.2
unnamed: MICRO_SD1.5, R43.2
unnamed: MICRO_SD1.7, R16.2
unnamed: MICRO_SD1.8, R7.2, R10.2
unnamed: PWRLED1.1, R4.1
unnamed: Q4.1, R41.2
unnamed: Q4.2, R42.1, U5.4
unnamed: Q5.1, R42.2
unnamed: Q5.2, R17.2, R41.1, U5.6
unnamed: Q5.3, R37.1
unnamed: R5.2, T1.3
unnamed: R12.1, U3.28
unnamed: R13.1, USB-UART1.B5
unnamed: R15.1, USB-UART1.A5
unnamed: R17.1, U5.5
unnamed: R19.1, R20.1, U1.5
unnamed: R39.1, U4.32

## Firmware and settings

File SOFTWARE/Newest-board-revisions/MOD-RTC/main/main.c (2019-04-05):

/* i2c - Example

   For other examples please check:
   https://github.com/espressif/esp-idf/tree/master/examples

   This example code is in the Public Domain (or CC0 licensed, at your option.)

   Unless required by applicable law or agreed to in writing, this
   software is distributed on an "AS IS" BASIS, WITHOUT WARRANTIES OR
   CONDITIONS OF ANY KIND, either express or implied.
*/
#include <stdio.h>
#include "driver/i2c.h"

/**
 * TEST CODE BRIEF
 *
 * This example will show you how to use I2C module.
 *
 * - read external i2c module, here we use a PCF8563
 *
 * Pin assignment:
 *
 * - master:
 *    GPIO32 is assigned as the data signal of i2c master port
 *    GPIO16 is assigned as the clock signal of i2c master port
 *
 * Connection:
 * - connect MOD-OLED to ESP32-GATEWAY using
 *   jumper wires (as shown on the picture)
 *   or any other kind of connections.
 * by default:
 *  MOD-RTC UEXT --> ESP32-GATEWAY extension
 *  pin 1 (3.3V) -->  pin 1 (3.3V)
 *  pin 2 (GND)  -->  pin 2  (GND)
 *  pin 5 (SCL)  -->  pin 11 (GPIO 16)
 *  pin 6 (SDA)  -->  pin 13 (GPIO 32)
 *
 *
 * - read the data from the module, if connected.
 * - on the terminal date and time will be printed
 * - by default the date and time is set to 28 February 2020; 23:59:50
 */

#define I2C_EXAMPLE_MASTER_SCL_IO          16               /*!< gpio number for I2C master clock */
#define I2C_EXAMPLE_MASTER_SDA_IO          32               /*!< gpio number for I2C master data  */
#define I2C_EXAMPLE_MASTER_NUM             I2C_NUM_1        /*!< I2C port number for master dev */
#define I2C_EXAMPLE_MASTER_TX_BUF_DISABLE  0                /*!< I2C master do not need buffer */
#define I2C_EXAMPLE_MASTER_RX_BUF_DISABLE  0                /*!< I2C master do not need buffer */
#define I2C_EXAMPLE_MASTER_FREQ_HZ         100000           /*!< I2C master clock frequency */

// I2C address of the module
#define  ADDRESS 0x51

// Control and status registers
#define  CTRL_STAT1  0x00
#define  CTRL_STAT2  0x01

// Time and date registers
#define  SECONDS     0x02
#define  MINUTES     0x03
#define  HOURS       0x04
#define  DAYS        0x05
#define  WEEKDAYS    0x06
#define  MONTHS      0x07
#define  YEARS       0x08

// Alarm registers
#define  AMINUTES    0x09
#define  AHOURS      0x0A
#define  ADAYS       0x0B
#define  AWEEKDAYS   0x0C

//CLKOUT control register
#define  CLKOUT_CTRL 0x0D

// Timer registers
#define  TIMER_CTRL  0x0E
#define  TIMER       0x0F

#define WRITE_BIT                          I2C_MASTER_WRITE /*!< I2C master write */
#define READ_BIT                           I2C_MASTER_READ  /*!< I2C master read */
#define ACK_CHECK_EN                       0x1              /*!< I2C master will check ack from slave*/
#define ACK_CHECK_DIS                      0x0              /*!< I2C master will not check ack from slave */
#define ACK_VAL                            0x0              /*!< I2C ack value */
#define NACK_VAL                           0x1              /*!< I2C nack value */

// 28 february 2020; 23:59:50
#define	INITIAL_DATE_TIME	{20, 2, 28, 5, 23, 59, 50}

struct _Date_Time
{
	unsigned char Year, Month, Day, WeekDay, Hour, Minute, Second;
};
typedef struct _Date_Time Date_Time;

SemaphoreHandle_t print_mux = NULL;

const int Mask[16] =
{
	0xFF,  // 0
	0xFF,  // 1
	0x7F,  // 2
	0x7F,  // 3
	0x3F,  // 4
	0x3F,  // 5
	0x07,  // 6
	0x1F,  // 7
	0xFF,  // 8
	0x7F,  // 9
	0x3F,  // 10
	0x3F,  // 11
	0x07,  // 12
	0x03,  // 13
	0x03,  // 14
	0xFF,  // 15
};

const char WeekDays[7][10] =
{
	"Sunday",
	"Monday",
	"Tuesday",
	"Wednesday",
	"Thursday",
	"Friday",
	"Saturday"
};

int BCD_to_Int (int Input)
{
	return (Input>>4)*10+(Input&0x0F);
}

int Int_to_BCD (int Input)
{
	return ((Input/10)<<4) | (Input%10);
}

/**
 * @brief i2c master initialization
 */
static void i2c_example_master_init()
{
	int i2c_master_port = I2C_EXAMPLE_MASTER_NUM;
	i2c_config_t conf;
	conf.mode = I2C_MODE_MASTER;
	conf.sda_io_num = I2C_EXAMPLE_MASTER_SDA_IO;
	conf.sda_pullup_en = GPIO_PULLUP_ENABLE;
	conf.scl_io_num = I2C_EXAMPLE_MASTER_SCL_IO;
	conf.scl_pullup_en = GPIO_PULLUP_ENABLE;
	conf.master.clk_speed = I2C_EXAMPLE_MASTER_FREQ_HZ;
	i2c_param_config(i2c_master_port, &conf);
	i2c_driver_install(i2c_master_port, conf.mode, I2C_EXAMPLE_MASTER_RX_BUF_DISABLE, I2C_EXAMPLE_MASTER_TX_BUF_DISABLE, 0);
}

static esp_err_t i2c_example_master_sensor_test(i2c_port_t i2c_num, uint8_t* Data)
{
	int ret;
	i2c_cmd_handle_t cmd = i2c_cmd_link_create();
	i2c_master_start(cmd);
	i2c_master_write_byte(cmd, ADDRESS << 1 | WRITE_BIT, ACK_CHECK_EN);
	i2c_master_write_byte(cmd, CTRL_STAT1, ACK_CHECK_EN);
	i2c_master_stop(cmd);
	ret = i2c_master_cmd_begin(i2c_num, cmd, 1000 / portTICK_RATE_MS);
	i2c_cmd_link_delete(cmd);
	if (ret != ESP_OK)
	{
		return ret;
	}
	vTaskDelay(30 / portTICK_RATE_MS);
	cmd = i2c_cmd_link_create();
	i2c_master_start(cmd);
	i2c_master_write_byte(cmd, ADDRESS << 1 | READ_BIT, ACK_CHECK_EN);
	i2c_master_read(cmd, Data, 15, ACK_VAL);
	i2c_master_read_byte(cmd, Data+15, NACK_VAL);
	i2c_master_stop(cmd);
	ret = i2c_master_cmd_begin(i2c_num, cmd, 1000 / portTICK_RATE_MS);
	i2c_cmd_link_delete(cmd);

	return ret;
}

void I2C_Send (unsigned char Register, unsigned char Data)
{
	unsigned char Temp[2] = {Register, Data};
	i2c_cmd_handle_t cmd = i2c_cmd_link_create();
	i2c_master_start(cmd);
	i2c_master_write_byte(cmd, ADDRESS << 1 | WRITE_BIT, ACK_CHECK_EN);
	i2c_master_write(cmd, Temp, 2, ACK_CHECK_EN);
	i2c_master_stop(cmd);
	i2c_master_cmd_begin(I2C_EXAMPLE_MASTER_NUM, cmd, 1000 / portTICK_RATE_MS);
	i2c_cmd_link_delete(cmd);
}

void Set_Date_Time (Date_Time *Start_Date_Time)
{
	I2C_Send (YEARS, Int_to_BCD(Start_Date_Time->Year));
	I2C_Send (MONTHS, Int_to_BCD(Start_Date_Time->Month));
	I2C_Send (DAYS, Int_to_BCD(Start_Date_Time->Day));
	I2C_Send (WEEKDAYS, Int_to_BCD(Start_Date_Time->WeekDay));
	I2C_Send (HOURS, Int_to_BCD(Start_Date_Time->Hour));
	I2C_Send (MINUTES, Int_to_BCD(Start_Date_Time->Minute));
	I2C_Send (SECONDS, Int_to_BCD(Start_Date_Time->Second));

	return;
}

static void i2c_test_task(void* arg)
{
	unsigned char Data[16];
	int ret, i;
	Date_Time Start_Date_Time = INITIAL_DATE_TIME;
	Set_Date_Time (&Start_Date_Time);
	while (1)
	{
		ret = i2c_example_master_sensor_test( I2C_EXAMPLE_MASTER_NUM, Data);
		xSemaphoreTake(print_mux, portMAX_DELAY);
		if(ret == ESP_ERR_TIMEOUT)
		{
			printf("I2C timeout\n");
		}
		else if(ret == ESP_OK)
		{
			// raw data
			// for (i=0; i<16; i++)
				//printf ("Data[%d] = %x\n", i, Data[i]);
			for (i=0; i<16; i++)
				Data[i] = BCD_to_Int(Data[i] & Mask[i]);
			printf ("\f%.2d/%.2d/%.2d (%s) %.2d:%.2d:%.2d\n", Data[8], Data[7], Data[5], WeekDays[Data[6]], Data[4], Data[3], Data[2]);
		}
		else
		{
			printf("No ack, sensor not connected...skip...\n");
		}
		xSemaphoreGive(print_mux);
		vTaskDelay(50);	// equals ~half a seconds
	}
}

void app_main()
{
	print_mux = xSemaphoreCreateMutex();
	i2c_example_master_init();
	xTaskCreate(i2c_test_task, "i2c_test_task_1", 1024 * 2, (void* ) 1, 10, NULL);
}

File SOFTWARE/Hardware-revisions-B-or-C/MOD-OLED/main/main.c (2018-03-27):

/* i2c - Example

   For other examples please check:
   https://github.com/espressif/esp-idf/tree/master/examples

   This example code is in the Public Domain (or CC0 licensed, at your option.)

   Unless required by applicable law or agreed to in writing, this
   software is distributed on an "AS IS" BASIS, WITHOUT WARRANTIES OR
   CONDITIONS OF ANY KIND, either express or implied.
*/
#include <stdio.h>
#include <string.h>
#include "driver/i2c.h"
#include "Draw_Functions.h"
#include "SSD1306.h"

/**
 * TEST CODE BRIEF
 *
 * This example will show you how to use MOD-OLED with ESP32-EVB.
 * https://github.com/OLIMEX/ESP32-EVB
 *
 * Pin assignment:
 *
 * - master:
 *    GPIO16 is assigned as the data signal of i2c master port
 *    GPIO13 is assigned as the clock signal of i2c master port
 *
 * Connection:
 * - connect MOD-OLED to the UEXT of the ESP32-EVB
 *
 *
 * - on the screen you will see a welcome message
 * - when you press the button you will see the button counter
 * - it will inverse the colors on every click
 */

uint8_t oledBuffer[OLED_SIZE];

SemaphoreHandle_t print_mux = NULL;

#define	PRESSED 	1
#define	RELEASED	0

// button scan function with simple debounce check
int Button_State (void)
{
	int Debounce_Timeout = 100;	// threshold value
	if (!gpio_get_level(GPIO_NUM_34))
	{
		while ((!gpio_get_level(GPIO_NUM_34)) && --Debounce_Timeout);
		if (!Debounce_Timeout)
			return PRESSED;
	}
	return RELEASED;
}

void i2c_test_task(void* arg)
{
	int ret, Flag=1, Counter=0;
	char Text [32];

	// button initialized as input
	gpio_set_direction (GPIO_NUM_34, GPIO_MODE_INPUT);
	
	oledInitialize ();
	print_text(1, " OLIMEX");
	print_smtext(3, (unsigned char *)"         Hello World!", 1);
	print_smtext(5, (unsigned char *)"         Press BUT1  ", 1);
	print_smtext(6, (unsigned char *)"         to see the  ", 1);
	print_smtext(7, (unsigned char *)"        click counter", 1);
	 

	drawLine(1, 25, 128, 25);

	drawEllipse(20, 70, 5, 20);
	drawLine(23, 52, 37, 60);
	drawLine(17, 52, 10, 64);

	drawCircle(20, 40, 10);
	drawLine(15, 38, 18, 38);
	drawLine(22, 38, 25, 38);
	drawLine(20, 40, 21, 42);
	drawLine(15, 43, 16, 45);
	drawLine(17, 46, 20, 47);
	drawTriangle(5, 35, 20, 28, 35, 35);

	drawRectangle(37, 55, 40, 65);
	drawSolidRectangle(37, 54, 40, 30);

	oledUpdate ();

	while (1)
	{
		ret = ESP_OK;
		xSemaphoreTake(print_mux, portMAX_DELAY);
		if(ret == ESP_OK)
		{
			if ((Button_State() == PRESSED) && Flag)
			{
				Counter++;
				Flag = 0;
				sprintf (Text, "BUT1 click count: %d", Counter);
				oledClear ();
				_set_inverse_display (Counter&1);
				print_text(1," OLIMEX");
				print_smtext(4,(unsigned char *)Text,0);
				oledUpdate ();
			}
			if (Button_State() == RELEASED)
				Flag = 1;
		}
		else
			if(ret == ESP_ERR_TIMEOUT)
			{
				printf("I2C timeout\n");
			}
			else
			{
				printf("No ack, sensor not connected...skip...\n");
			}
		xSemaphoreGive(print_mux);
	}
}

void app_main()
{
	print_mux = xSemaphoreCreateMutex();
	i2c_example_master_init();
	xTaskCreate(i2c_test_task, "i2c_test_task_1", 1024 * 2, (void* ) 1, 10, NULL);
}

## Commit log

2017-06-21 initial update ESP32-GATEWAY KiCAD files
    [ESP32-GATEWAY_Rev_A-BOM.ods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]
2017-09-12 Updated hardware revision B
    [ESP32-GATEWAY_Rev_A-BOM.ods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]
2018-03-27 Tested demos update
    ESP-IDF demos tested with ESP32-GATEWAY
2018-07-31 update
    hardware revision C
    [ESP32-GATEWAY_Rev_C.kicad_pcb, ESP32-GATEWAY_Rev_C.sch]
2019-01-04 Update
    Revison D and E and revision changes.
    [ESP32-GATEWAY_Rev_D.kicad_pcb, ESP32-GATEWAY_Rev_D.sch]
2019-04-05 Update
    new demo for boards from hardware revision D or newer
2019-09-23 Fix
    Wrong sources were uploaded by mistake
    [ESP32-GATEWAY_Rev_E.kicad_pcb, ESP32-GATEWAY_Rev_E.sch]
2019-12-09 Update
    Added sources and notes revision F
    [434121043836 (rev1).stp, 5040771891.stp, BAT54.step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]
2020-05-12 Update
    Added revision G
    [434121043836 (rev1).stp, 5040771891.stp, BAT54.step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]
2020-10-22 Update
    "Toggle_relay" project renamed to "led_button" to avoid confusion since there is not relay but only LED on Gateway board.
    [led_button.c]
2024-10-08 Update
    Revisions H and I
    [434121043836 (rev1).stp, 5040771891.stp, BAT54.step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]
2024-10-10 Update
    New hardware revision changes the USB connector
2025-07-18 Update sdkconfig
    Changed Eth reset pin value from -1 to 5
2026-01-19 Update
    Added plastic box design
    [esp32_gateway-v16-bambu-lab-project.3mf, esp32_gateway-v16.stl]

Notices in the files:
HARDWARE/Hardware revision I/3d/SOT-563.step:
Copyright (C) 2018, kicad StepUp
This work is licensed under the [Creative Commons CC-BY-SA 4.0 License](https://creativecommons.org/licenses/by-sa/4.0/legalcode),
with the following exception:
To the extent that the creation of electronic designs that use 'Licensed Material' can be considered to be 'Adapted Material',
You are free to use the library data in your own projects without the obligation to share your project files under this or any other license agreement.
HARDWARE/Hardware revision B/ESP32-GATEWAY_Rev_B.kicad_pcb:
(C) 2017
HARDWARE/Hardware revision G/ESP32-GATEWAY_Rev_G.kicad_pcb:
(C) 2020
